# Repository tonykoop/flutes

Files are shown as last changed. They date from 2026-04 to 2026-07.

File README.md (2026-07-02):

# Flutes — Engineering Documentation for Native American Style Wooden Flutes

> *150+ Native American style wooden flutes built between roughly 2018 and 2021, plus the parametric design table that produced them and the build registry that tracked them.*

**Status:** L1 concept packet — L1 V5 packet/explorer scaffold. The repo contains strong historical design-table and build-registry evidence, but this Round 31 packet does not claim V5 build-ready, measured-current, or runtime-verified status until the family rows are extracted from the workbook, mapped to current CAD/DXF, and checked against physical measurements.

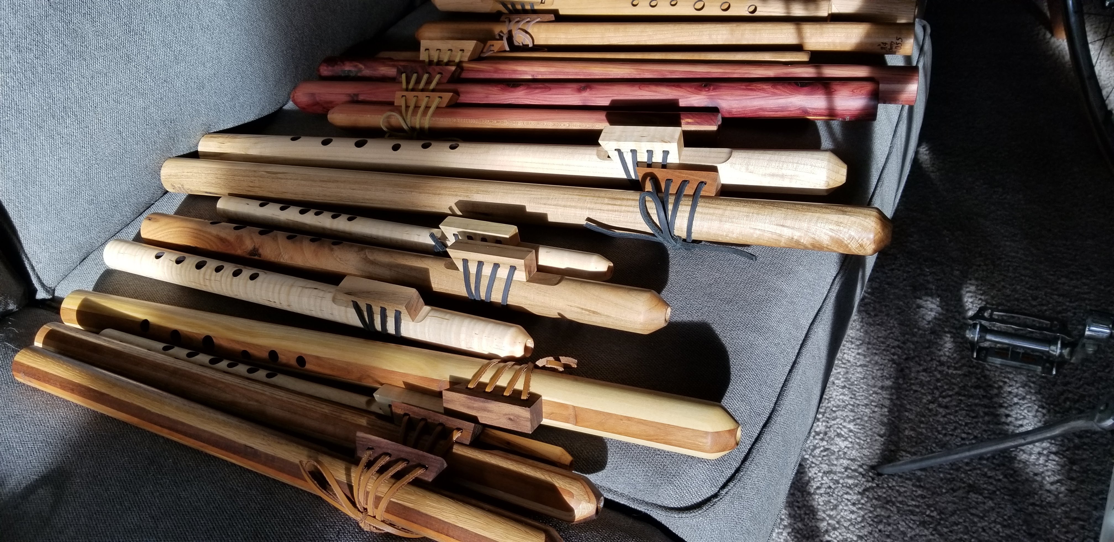
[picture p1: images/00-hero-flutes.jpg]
Hero photo

*A fan-out of finished Native American style wooden flutes across multiple wood species, keys, bird/fetish block styles, and lacing details — the production outcome of the parametric design table and build registry documented below.*

## What this is

Engineering documentation for a multi-year personal practice of building **Native American style flutes** — a two-chambered, end-blown, fipple-class wooden flute tuned to the pentatonic minor scale, traditionally associated with the music of various Indigenous peoples of North America.

This repository combines four threads:

1. **A parametric design table** ([`design-table/flute-dimensions-parametric.xlsx`](design-table/flute-dimensions-parametric.xlsx)) covering flutes from **F4 to E5**, with formulas that derive every build dimension — bore ID, wall thickness, hole positions, hole diameters, blank dimensions, board feet of wood — from a single input: the target fundamental note. Built around the canonical NAF pentatonic-minor hole spacing (3-2-2-3-2 semitones).
2. **A build registry** of **150+ serial-numbered flutes** I've made, recording wood species, key, dimensional measurements, failure modes, and final build status.
3. **CAD geometry** for the body, the slow-air chamber, the nest, the bird/fetish block, and the cutting jigs.
4. **Lineage:** the build methodology was learned from the **[Blue Bear Flutes](https://www.youtube.com/@bluebearflutes)** YouTube channel and developed forward from there into a parametric system.

Sister project to [`djembe`](https://github.com/tonykoop/djembe), [`dundun`](https://github.com/tonykoop/dundun), [`didgeridoo`](https://github.com/tonykoop/didgeridoo), and [`ashiko-drum-workshop`](https://github.com/tonykoop/ashiko-drum-workshop).

Computational counterpart: the Wolfram Summer School notebook **[`Properties of a Native American Flute.nb`](https://github.com/tonykoop/WSS-2019/tree/main/Homework/Final%20Submission)** in [`WSS-2019`](https://github.com/tonykoop/WSS-2019), where the same instrument family gets treated as a computational essay rather than a shop-and-build archive.

## V5 Packet Entry Points

- [design.md](design.md) — Round 31 packet design intent, family split, and evidence boundaries.
- [family-spec.csv](family-spec.csv) — multi-flute family rows with explicit acoustic-law and measurement gates.
- [validation.csv](validation.csv) — current blockers before this becomes a build-ready V5 packet.
- [visual-output-register.csv](visual-output-register.csv) — CAD/DXF/design-table/photo authority map.
- [capstone-manifest.json](capstone-manifest.json) — repo-relative packet inventory for the explorer.
- [explorer.html](explorer.html) — conservative browser explorer for issue #3.
- [CAD/flutes_family.scad](CAD/flutes_family.scad) — minimal OpenSCAD scaffold, not a measured production model.
- [drawings/flutes-family-layout.svg](drawings/flutes-family-layout.svg) and [drawings/flutes-family-layout.dxf](drawings/flutes-family-layout.dxf) — first-pass family split plate.

## Cultural attribution

Native American flutes hold deep spiritual and cultural significance in many Indigenous communities of North America, with traditional roles in courtship, ceremony, healing, and storytelling. As a non-Indigenous maker, the instruments I build are more accurately termed **"Native American style flutes"** (sometimes NAF or NASF) — instruments inspired by, learned in dialogue with, and built in respect for the tradition, but not part of it. The methods documented here are publicly-available craft and engineering knowledge passed forward from contemporary makers to me; the deeper cultural practice belongs to the Indigenous communities from whom the instrument originates.

## Background — what makes a Native American flute different

A Native American flute is **two acoustic chambers in series** with an external block on top:

- **Slow Air Chamber (SAC)** — the short upper chamber. Player blows into the mouthpiece; air enters the SAC and is rerouted up through a small flue, across the open top of the body, and into the True Sound Hole.
- **Bird / Fetish Block** — a removable wooden block sitting on top of the flute, often carved into a totemic shape. Its underside has a precisely-cut channel that directs the air across the True Sound Hole at the right angle and speed to excite the playing chamber.
- **Long (Playing) Chamber** — the main body of the flute, with six finger holes drilled at calculated positions to produce the pentatonic minor scale.

The split-chamber design is what distinguishes the NAF from a Western fipple flute (recorder, tin whistle), where the fipple is integrated into the headjoint. The NAF's external block lets the maker tune the flute's voicing by adjusting the block's position, the flue dimensions, and the angle of the cut into the True Sound Hole — all without disturbing the body. This is also what makes the NAF an extraordinarily sensitive instrument to engineer correctly: small geometry changes shift the tuning audibly.

## The parametric design table

The single most engineering-heavy artifact in this repository is the parametric design table — a spreadsheet that takes a target fundamental note as input and computes every dimension required to build a flute that plays in tune.

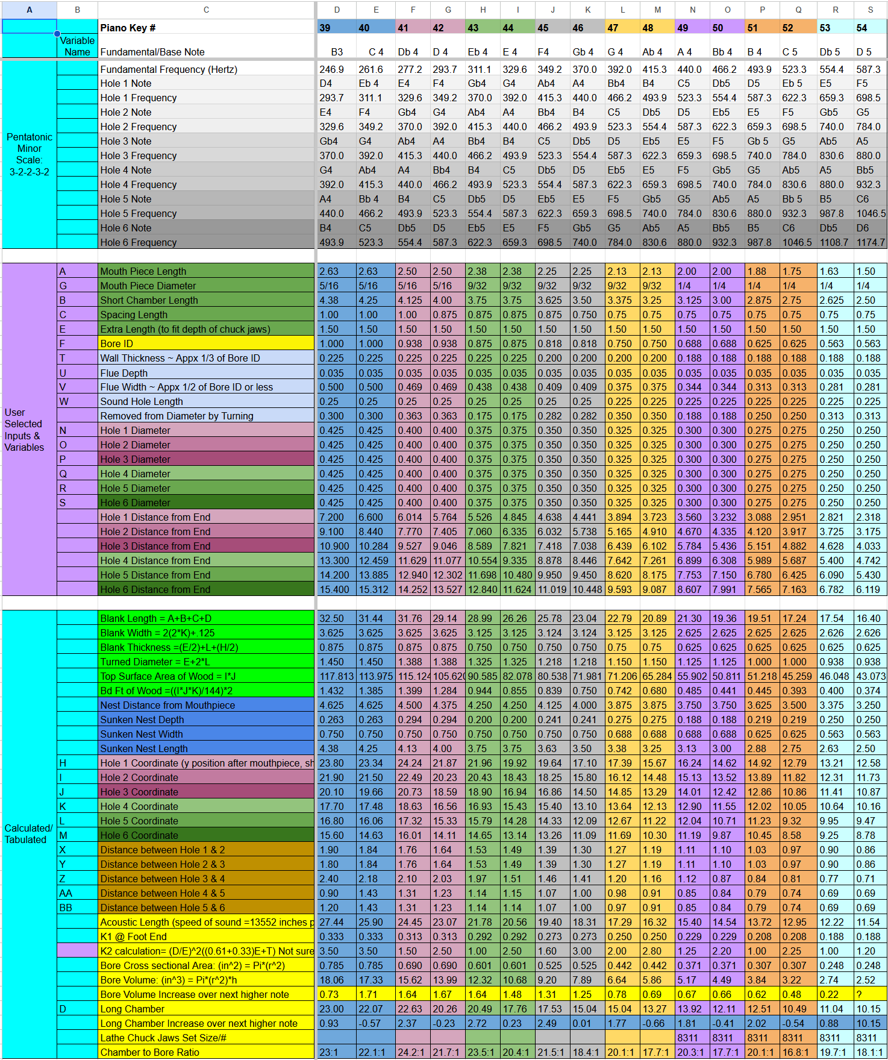
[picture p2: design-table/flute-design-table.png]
Screenshot of the parametric flute design table — keys F4 through E5 as columns, three colored bands of rows: pentatonic-minor scale frequencies, user-set inputs, and derived/calculated dimensions

*The full design table at a glance. **Columns** are target keys (piano key numbers 38–54, i.e. F4 through E5) — pick the column for the flute you want to build. **Rows** are organized into three colored bands: the **beige Pentatonic Minor Scale** band at the top tabulates the fundamental and the six hole frequencies (the canonical **3-2-2-3-2** semitone pattern); the **green User-Selected Inputs & Variables** band in the middle is where you set mouthpiece/chamber/bore/wall/flue/hole-diameter values; and the **red Calculated/Tabulated** band at the bottom derives blank dimensions, board feet of wood, nest position and depth, hole-to-hole spacings, and the K1/K2 acoustic-length corrections that close the loop on the tuning. Change one cell in the green band and the entire red band recomputes — that's the engineering core. The full workbook with formulas live is at [`design-table/flute-dimensions-parametric.xlsx`](design-table/flute-dimensions-parametric.xlsx).*

Inputs are listed in column A, calculated/tabulated values in column G:

**User-set variables (per key):**

| Var | Meaning |
|---|---|
| A | Mouthpiece length |
| B | Short chamber length (the SAC) |
| C | Spacing length (between SAC and playing chamber) |
| E | Extra length to fit lathe chuck jaws |
| F | Bore inner diameter |
| G | Mouthpiece diameter |
| N–S | Hole diameters (six finger holes) |
| T | Wall thickness (~ 1/3 of bore ID) |
| U | Flue depth (~ 0.035" across all keys) |
| V | Flue width (~ 1/2 of bore ID) |
| W | Sound hole length |

**Calculated/derived (per key, formula-driven):**

- Blank length, blank width, blank thickness — total wood requirements
- Turned diameter — finished outside surface
- Board feet of wood — material cost
- Nest distance from mouthpiece — where the bird/fetish block sits
- Sunken nest depth + width — to keep the bird flush with the body
- Hole positions (six holes) — distance from foot end of flute, computed from acoustic relationships

**Tuning:** the design assumes a **pentatonic minor scale** with the standard NAF semitone pattern of **3-2-2-3-2** above the fundamental. The hole frequencies are computed from `f = 440 × 2^((n-49)/12)` where `n` is the piano key number — chromatic equal temperament referenced to A4 = 440 Hz.

Both `CNC Flute Dimensions` (designed for CNC-machined blanks, very precise) and `Low to High Range` (broader range, hand-builder friendly) sheets live in the workbook and produce slightly different geometry trade-offs.

## The build registry

The `Built` sheet of the workbook tracks every flute I've made by serial number. Engineering columns include: number, wood species, key, true-sound-hole width (TSH), track length, nest width, fetish requirement, finished long chamber length, hole pattern reference, date glued, date routered. Customer and gift-recipient information is kept private and is not included in the public version of this registry.

Patterns from the registry as of last update:

- **150+ flutes** documented across the build sheet (numbers 001 through 153 at last update).
- **Wood species** explored: White Oak, Pine, Mahogany, Hard Maple, Western Red Cedar, Black Walnut, Brazilian Walnut, Ambrosia Maple, Birch, Poplar, Oak.
- **Keys** covered: F4, Gb4, G4, Ab4, A4, Bb4, B4, C5, Db5, D5, Eb5, E5 — most of the playable middle range.
- **Failure modes** logged honestly: *"Death on the Router," "Exploded on the lathe, bark inclusion," "Failed Quality Control," "TSH too big," "cut into signature."* Engineering yield was a real consideration; the registry is what let me see which wood/key combinations were durable and which weren't.
- **Dispositions** ranged from gifts to art-fair sales to in-stock inventory and learning-experience builds — recipient details are kept private.

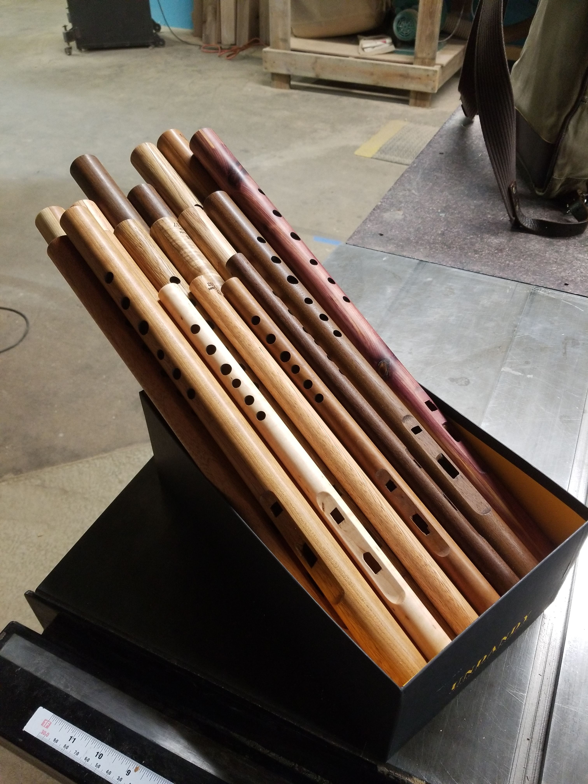
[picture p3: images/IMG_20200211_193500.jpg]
A bundle of finished Native American style flutes across multiple wood species

*A representative bundle of finished flutes — multiple wood species visible (purpleheart, walnut, maple, cedar, oak), various keys, all hand-built to the parametric design table specs.*

## Engineering challenges this repository documents

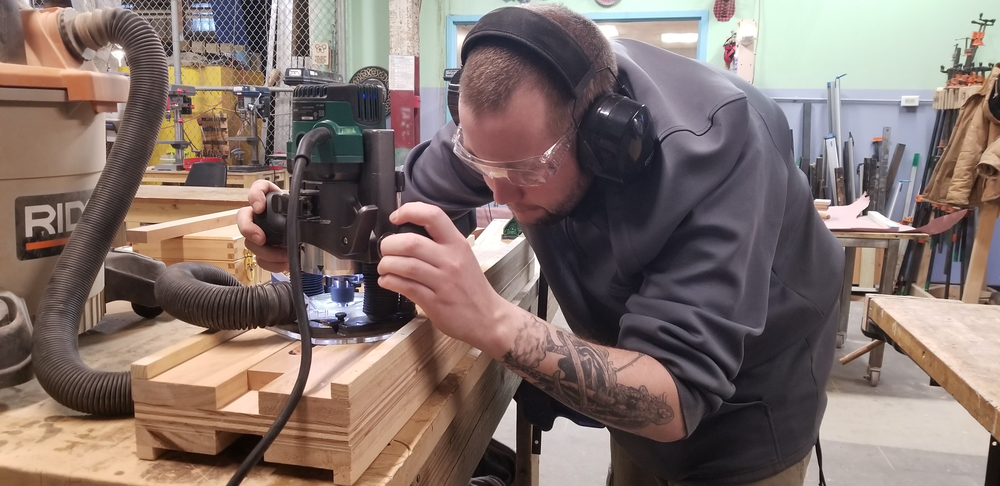
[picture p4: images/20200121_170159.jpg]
Routing the slow-air-chamber profile on a flute body

*In the shop with the plunge router — cutting the slow-air-chamber and true-sound-hole geometry into a flute body. The routing fixture is what makes the SAC and TSH cuts repeatable across builds.*

**1. Two-chamber acoustic tuning.** Unlike a single-chamber instrument (didgeridoo, recorder), the NAF has air paths that interact in the SAC → flue → TSH → playing-chamber sequence. The fundamental of the playing chamber depends on the Long Chamber's effective length, but the playing *response* (how much breath pressure produces clean tone) depends on the SAC, flue, and block geometry. The parametric table captures the dimensional rules; the build registry captures what worked.

**2. Wood-species variation.** The same dimensional spec produces audibly different tone in cedar, walnut, and maple. The registry's `Wood Species` and `Notes` columns let me track which species were forgiving (cedar — very) and which were unforgiving (hard maple — yes; ambrosia maple — also unforgiving, with a high failure rate noted in the registry).

**3. Yield management.** The registry's failure-mode entries are an honest record of how often a flute didn't survive the build. Lathe explosions and routing accidents were not rare. Building a parametric design table didn't reduce yield to 100%; it *bounded* the tolerance window, made each failure diagnosable, and let me iterate the table by what failed.

## CAD and jig design

> *(Forthcoming — pulling SolidWorks files for the body, nest, fetish block, and routing jigs into `/CAD/` as I get SolidWorks running again.)*

Repository structure is laid out for:

- `/CAD/flute-body/` — the body geometry parametric in target key.
- `/CAD/nest-and-fetish/` — the sunken nest where the bird/fetish block sits, and the block geometry itself (with the air-direction channel underneath).
- `/CAD/jigs/` — the routing fixture for cutting the SAC and TSH, and any sanding or hole-drilling jigs.

## Lineage and acknowledgments

The build methodology in this repository was learned primarily from the **[Blue Bear Flutes](https://www.youtube.com/@bluebearflutes)** YouTube channel — an extraordinary public archive of craft knowledge from a contemporary maker generously sharing technique. The parametric design table and the engineering documentation are my own derivations from that learning process; the underlying craft is not.

## What this work is for

- **The engineering question** — does a parametric design table let you reliably build flutes in tune across multiple wood species and a wide key range? The build registry says: yes, *bounded by* yield. Improving the table's predictions is the iterative loop the table itself enables.
- **The portfolio frame** — for engineers and recruiters: this repository documents an ongoing engineering-grade craft practice. The parametric table is a working SolidWorks-adjacent design tool; the build registry is the production data that validated it; the failure-mode column is the honest engineering-yield record. All from one personal practice spanning ~3+ years.
- **The personal frame** — these flutes have been gifts, art-fair sales, family heirlooms, and personal instruments. The people who received them are not named in this repository.

## License

Released under [CC-BY 4.0](LICENSE) — use freely with attribution. The Native American flute originates with Indigenous peoples of North America and remains culturally significant; the engineering documentation, parametric design table, build registry, and analysis in this repository are my own work, free to reuse and adapt with credit. The Blue Bear Flutes lineage is acknowledged above and any derivative work should reference that source as well.

## Repository structure

```
flutes/
├── README.md                  ← you are here
├── LICENSE                    ← CC-BY 4.0
├── .gitignore
├── design-table/
│   └── flute-dimensions-parametric.xlsx   ← the engineering core
├── built-log/
│   └── (extracts from the Built sheet — flute build registry)
├── research/                  ← Blue Bear Flutes references, NAF acoustic notes
├── analysis/                  ← derived charts, yield analysis (forthcoming)
├── CAD/
│   ├── flute-body/            ← body geometry parametric in key
│   ├── nest-and-fetish/       ← sunken nest + bird/fetish block geometry
│   └── jigs/                  ← routing fixture, hole-drilling jigs
├── drawings/                  ← PDF exports of hole patterns + body sections
├── images/                    ← finished-flute photos, build photos, fetish detail shots
└── reference/                 ← scale/temperament references, NAF community resources
```

## Status

| Section | Status |
|---|---|
| Repo description, license, gitignore | ✓ done |
| Parametric design table | ✓ committed (the engineering core) |
| Build registry summary | ✓ summarized in this README |
| Hero photos | ✓ done |
| Cultural attribution | ✓ done |
| CAD — body geometry | not yet committed (SolidWorks access pending) |
| CAD — nest + fetish | not yet committed |
| CAD — jigs | not yet committed |
| Yield analysis from build registry | forthcoming |
| Evolution-pipeline intake | Stage 0 intake added under `evolution/` (manifest, design-intent, revisions); Gate A not yet run |

Living document — the empirical core is already here; CAD exports and yield-analysis follow-ons are the main remaining additions.
## Learn to play

Starter songbooks for the flutes built from this repo's design table
live under [`learn-to-play/`](learn-to-play/), one per build family:

- [`learn-to-play/naf-6hole/`](learn-to-play/naf-6hole/) — A-tuned
  6-hole NAF starter songbook: warmup scales, three beginner tunes
  (Amazing Grace, Star of the County Down, What Wondrous Love Is This),
  two intermediates (Simple Gifts, Twinkle Twinkle), and one Heifer
  Zephyr original (Pre-Dawn Field). Open `songsheet.pdf` for the
  one-page summary.

Songbooks are generated by [sheet-music](https://github.com/tonykoop/sheet-music)
— pair `instrument-maker-v4` (designs the flute) with that skill (writes
the music for it).

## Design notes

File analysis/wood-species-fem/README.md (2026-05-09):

# Wood-Species Coupled Structural-Acoustic FEM

**Issue:** `flutes#1` — Coupled structural-acoustic FEM: quantify wood-species
effect on tone (cedar vs walnut vs hard maple).

**Readiness:** L3-frontier analysis (methodology complete, analytical results
computed, FEM execution ready, empirical gate deferred).

---

## Summary

This analysis quantifies how wood species — Western Red Cedar, Black Walnut,
and Hard Maple — affects the tone of a Native American style flute with a fixed
A4-key bore geometry.

**Key finding:** At A4, the "forgiving vs demanding" character difference between
species is driven primarily by **wall damping** (η_L), not by structural-acoustic
mode coincidence.

| Species | η_L | f_QSC (Hz) | Tone |
|---|-----|---|---|
| W. Red Cedar | 0.030 | **1141** | Warm, forgiving |
| Black Walnut | 0.020 | **1176** | Balanced |
| Hard Maple | 0.014 | **1203** | Bright, demanding |

f_QSC is the Q-weighted spectral centroid — a scalar tone-brightness index.
Cedar's higher damping attenuates upper partials 2.1× faster than maple,
explaining the registry observation without requiring structural modes to
coincide with acoustic partials.

No structural-acoustic avoided crossing was found at < 5% separation for
any species at A4 key (smallest observed separation: 9.1%, Hard Maple
2nd bending mode vs acoustic n=3).

---

## Files in this directory

| File | Contents |
|---|---|
| `README.md` | This summary |
| `wood-property-table.md` | E, ρ, η, Poisson ratios per species with FPL-GTR-190 citations |
| `fem-scenario.md` | Geometry, mesh, BCs, coupling physics, analysis type |
| `modal-results-table.md` | 5 acoustic modes + 3 structural modes per species; Q-factor tables |
| `tone-color-comparison.md` | f_QSC computation, spectrum ASCII plot, root-cause analysis |
| `capstone-design-table.md` | All parameters in one table; FEM execution status; next steps |
| `references.md` | Literature and software citations |

---

## Physics overview

### Air-column modes

Open-open cylindrical bore, L_eff = 390 mm (A4 key):

    f_n = n × 440 Hz    for n = 1, 2, 3, 4, 5

These are the same for all species. Wall compliance shifts modes < 1%
(bore is stiff relative to air pressure at these dimensions).

### Body bending modes

Hollow cylinder, simply-supported, L = 381 mm.

    f_body_n = n² × (π / 2L²) × √(EI / ρA)

| Species | f_body_1 | f_body_2 |
|---|---|---|
| Cedar | 388 Hz  | 1552 Hz |
| Walnut  | 371 Hz  | 1484 Hz |
| Maple | 360 Hz  | 1440 Hz |

### Acoustic Q-factor

    1/Q_n = 1/Q_rad_n + 1/Q_wall
    Q_rad_n ≈ n × 15     (radiation loss, bore geometry)
    Q_wall = 1/η_L        (species-dependent wall damping)

### Tone color metric

    f_QSC = Σ(f_n × Q_n × A_n) / Σ(Q_n × A_n)
    A_n = 1/n   (fipple excitation amplitude model)

---

## Relationship to registry observations

The build registry records: "Cedar is forgiving; hard maple is demanding;
ambrosia maple has a high failure rate." This analysis provides the first
principled physical explanation: **cedar's 2.1× higher damping factor
attenuates upper partials faster**, reducing the sensitivity of the
instrument to embouchure variations and overblowing.

The analysis also rules out structural-acoustic mode coincidence as a
first-order explanation at A4 key — all species show body modes separated
from acoustic harmonics by > 9%.

---

## FEM execution status

Analytical pre-computation complete. Full FEM execution (COMSOL Acoustic-Solid
Interaction or Ansys Harmonic Acoustics) will refine:
- Exact body mode frequencies (cylindrical shell vs beam approximation)
- Orthotropic vs isotropic material response
- Radiation impedance at open ends

Empirical validation (FFT blow test on three A4 registry flutes)
is deferred; no measured spectral data exists in the repo yet.

**Do not claim L4 build-ready.** This is a frontier analysis; computed
FEM results and empirical comparison are required for L4.

---

## Cross-references

- `design-table/flute-dimensions-parametric.xlsx` — bore geometry source
- `built-log/` — build registry with species-resolved entries
- `tonykoop/WSS-2019` — Wolfram notebook: air-column acoustic model
- `tonykoop/tensile-testing` — orthotropic E-tensor measurement pipeline
- `tonykoop/tongue-drum` analysis `docs/study/fem-modal-validation.md`
  — FEM pipeline reused; FFT measurement protocol shared

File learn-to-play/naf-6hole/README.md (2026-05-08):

# learn-to-play / Native American Flute (6-hole)

A starter songbook for the **A-tuned 6-hole Native American flute**
you built from [`flutes`](https://github.com/tonykoop/flutes) (the
parametric design table family). Generated by the
[`sheet-music`](https://github.com/tonykoop/sheet-music) skill.

This songbook is calibrated for the **A-tuned NAF** specifically —
fundamental A4, range A4–D6, A minor pentatonic. If your build is in a
different key (G, F#, D are also common in the registry), the same
tune.abc files transpose naturally; re-deposit with `--instrument
naf-6hole` after updating the registry row.

## Folder map

| Folder | Contents |
|---|---|
| `00-warmup-scales/` | Range walk, pentatonic intervals, and the single-grace ornament drill |
| `01-easy/` | Three slow, beginner-friendly PD tunes |
| `02-intermediate/` | Two brisker PD tunes with wider intervals |
| `03-original/` | *Pre-Dawn Field* — the Heifer Zephyr original written for this build |
| `fingering-charts.svg` | Combined fingering chart for every NAF pitch (A4–D6) |
| `songsheet.pdf` | Printable one-page summary of the whole songbook |

## Repertoire

### 01-easy

| Tune | Tradition | Key on A-NAF |
|---|---|---|
| Amazing Grace | Hymn (Newton 1779 / "New Britain" 1835) | A min pent (transposed up an octave from canonical G) |
| Star of the County Down | Trad. Irish ("Dives and Lazarus" family, pre-1855) | A min pent (pentatonicised from A dorian) |
| What Wondrous Love Is This | Trad. Appalachian (1811 / 1835) | A min pent (pentatonicised from A dorian) |

### 02-intermediate

| Tune | Tradition | Key on A-NAF |
|---|---|---|
| Simple Gifts | Shaker dance song (Brackett 1848) | A min pent (re-keyed from F major) |
| Twinkle Twinkle Little Star | Mozart K. 265 (1781) / Taylor 1806 | A min pent (re-keyed from C major) |

### 03-original

**Pre-Dawn Field** — composed for this build. AABA, 32 bars, ♩=60.
Written for the Heifer Zephyr origin moment: chasing aurora north of
Minneapolis, sitting up all night counting constellations, watching
cold fog settle on the field as the sun rose, breath flaring in the
chill like a heifer bison's in a Yellowstone morning. Read the full
story in [`03-original/pre-dawn-field/notes.md`](03-original/pre-dawn-field/notes.md).

## How to use the per-tune files

Every tune folder has multiple files. The canonical source is
`tune.abc` — everything else is generated from it.

| File | Purpose |
|---|---|
| `tune.abc` | Canonical notation in ABC format (plain text) |
| `tune.musicxml` | Notation for Ableton, Logic, MuseScore, Sibelius, etc. |
| `tune.mid` | Playable MIDI (uses GM preset 76 — Pan Flute) |
| `tune-fingering.svg` | Fingering chart, one diagram per distinct pitch |
| `tune.pdf` | Per-tune one-page printable songsheet |
| `notes.md` | Source / provenance, range notes, practice tip |
| `render-summary.json` | Which pipeline stages succeeded / were skipped |

> **Skipped stages on this generation:** `tune.ly` (LilyPond not
> installed locally), `tune.svg` (depends on LilyPond), and `tune.wav`
> (fluidsynth not installed). These are honest skips — install the
> binaries and re-run `scripts/render_pipeline.py` to fill them in.
> See `references/audio-rendering.md` in the `sheet-music` repo.

## Suggested practice path

1. Open the day with `00-warmup-scales/range-walk.abc`. Hold each note
   long enough to find a steady tone before moving up. Ascending,
   descending, twice through.
2. Run `intervals.abc` once. The 5ths and the octave are the wider
   embouchure stretches you'll need for the songbook.
3. Pick one tune from `01-easy/`. Open its `tune.mid` to hear the
   melody, then read its `notes.md` for the range check and practice
   tip.
4. Play the first phrase slowly with the per-tune fingering SVG open.
   Don't worry about tempo — find the breath first, the rhythm second.
5. When all three easy tunes feel comfortable, move to
   `02-intermediate/`. Simple Gifts and Twinkle Twinkle have wider
   intervals and brisker tempos.
6. Save `03-original/pre-dawn-field/` for a quiet hour. It's meant to
   be played slowly, alone.

## Re-generating

If you change a `tune.abc` (transposing, ornamenting, fixing a typo),
regenerate the derived files:

```bash
# from the sheet-music repo root:
python scripts/render_pipeline.py \
  --tune <tune.abc path> \
  --instrument naf-6hole \
  --out <output dir>
```

## License

- **Pre-Dawn Field** (the original) — MIT-licensed, same as the rest
  of `sheet-music`. Yours to perform, record, arrange, and adapt.
- **Public-domain tunes** — PD by virtue of pre-1929 publication.
  Per-tune provenance is documented in each `notes.md`. The specific
  arrangements (which transpose / pentatonicise the originals for the
  A-NAF) are MIT-licensed by Tony Koop / Heifer Zephyr.

## Where to ask for more

- More tunes for the NAF: open an issue in
  [`sheet-music`](https://github.com/tonykoop/sheet-music) with the
  tradition or mood you want, and reference `naf-6hole` as the target.
- Build questions for the flute itself: see [`flutes`](https://github.com/tonykoop/flutes).
- Companion skill that designs and documents the build: `instrument-maker-v4`.

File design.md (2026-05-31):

# Flutes V5 Packet Scaffold

## Design Intent

This packet promotes the `flutes` repository from a historical engineering archive toward a V5 packet/explorer scaffold. The repo already has unusually strong evidence for Native American style wooden flutes: a parametric workbook, build photos, historical SolidWorks files, learning material, and a wood-species FEM study. Round 31 does not convert that history into a build-ready packet by assertion. It makes the family split explicit and records the measurement gates needed before any row can be treated as current fabrication authority.

## Family Split

| Family | Scope | Current authority | Measurement gate |
| --- | --- | --- | --- |
| `NAF-6H` | Six-hole Native American style wooden flutes from the historical workbook | Public F4/A4/C5 workbook rows and sanitized build-log aggregates now exist, but they are comparison evidence only | Log current measured fundamental plus six-hole tuning for each selected key before treating the rows as CAD/DXF or build authority |
| `PVC-TRAIN` | PVC training or proof flute using the same open-open acoustic law | Planning family only | Select bore stock, measure actual ID, then compute and drill a proof flute before publishing dimensions |
| `LEGACY-SW` | Historical SolidWorks body/nest/fetish/jig assets | Archived source files exist under `legacy/` and stashed CAD paths, but they are not normalized into V5 CAD | Recover the chosen model, export clean neutral geometry, and map dimensions back to family rows |
| `SONGBOOK` | Learn-to-play assets for the 6-hole NAF family | Documentation/playability support | Keep separate from fabrication authority; fingering charts do not validate geometry |

## Governing Acoustic Model

The target rows are duct flutes with an effectively open-open long playing chamber. The first-order model is:

```text
L_eff = c / (2f)
L_geom = L_eff - end_correction
```

The historical design table also includes NAF-specific corrections and voicing geometry for the slow-air chamber, flue, true sound hole, bird block, and six finger holes. Those corrections are design-table evidence, not something this scaffold re-derives by hand. The extracted F4/A4/C5 rows stay `dimension_provenance=measurement_required` until checked against current measured tuning traces.

## Evidence Boundary

- The workbook extraction and sanitized build-log comparison support an L1 packet scaffold and justify a future L2 shop-packet candidate after current measured tuning checks.
- The FEM analysis is a study artifact for wood-species behavior. It does not replace per-flute pitch, decay, or hole-tuning measurements.
- The new OpenSCAD, SVG, and DXF files are family-split scaffolds. They show packet organization and authority routing, not a complete production flute.
- Photos are documentation and provenance support only. They are not dimensional authority.

## Next Promotion Gates

1. Capture current measured fundamental plus six-hole tuning for the F4, A4, and C5 public workbook rows.
2. Reconcile the C5 historical chamber-length mismatch before using that row for CAD/DXF or cut-list authority.
3. Keep the A4 FEM simplification analysis-only until it is reconciled with the workbook row and measured logs.
4. Replace scaffold CAD/DXF with checked geometry generated from reviewed design-table rows.
5. Add MCP provenance entries only when an actual OpenSCAD, Blender, Illustrator, or Photoshop MCP session produces a repo artifact.

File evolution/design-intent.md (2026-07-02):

# Design Intent — flutes rev A

- Master CAD: `CAD/flutes_family.scad` (sha256: da8ef2fa96771d89ffb48a29936026cc3f3fe4fb7997d9f78b5e01fbb8e4db68), driven by seed `CAD/design-table-seed.csv` (sha256: 6ed4ceb9d774c4f560a766ce802a76e79e68c5fdd5b87be7ef8ca6b55cc04e46) and historical workbook `Flutes.xlsx` (sha256: 3a58014cc2f502797e02126382682203d9d7711faf644c904f6b40cbbbca840d)
- Function: Native American style six-hole wooden flutes (NAF-6H) plus PVC training and legacy-SolidWorks families. Duct flutes with an effectively open-open long playing chamber: L_eff = c/(2f); L_geom = L_eff − end_correction. NAF-specific corrections and voicing (slow-air chamber, flue, true sound hole, bird block, six finger holes) live in the historical workbook as evidence, not re-derived here.
- Environment: L1 concept/explorer scaffold on top of a strong historical archive (150+ serial-numbered builds, workbook, FEM wood-species study, legacy SolidWorks). Nothing is build-ready until family rows are extracted from the workbook and checked against current measured tuning.
- Target qty: 1 (per selected key). Deadline: TBD. Budget/unit ceiling: TBD.

## Critical dimensions (carry tolerances)

| Feature | Nominal | Tolerance | Why critical | Source |
| --- | --- | --- | --- | --- |
| NAF-6H F4 predicted geometric length | 432.562 mm | measure current fundamental before authority | fundamental pitch (F4 = 349.23 Hz) | family-spec.csv NAF-6H-F4 (measurement_required) |
| NAF-6H A4 predicted geometric length | 337.490 mm | measure current A4 tuning | fundamental pitch (A4 = 440.00 Hz) | family-spec.csv NAF-6H-A4 (measurement_required) |
| NAF-6H C5 predicted geometric length | 285.318 mm | reconcile built-log chamber mismatch | fundamental pitch (C5 = 523.25 Hz) | family-spec.csv NAF-6H-C5 (measurement_required) |
| NAF-6H A4 bore ID | 19.050 mm | measure fired/turned bore | bore governs pitch/response | family-spec.csv NAF-6H-A4 (measurement_required) |
| Hole count | 6 | ergonomic + tuning gate | six-hole tuning log required | family-spec.csv (measurement_required) |
| PVC-TRAIN bore ID | measurement_required | measure stock before computing | planning row only | family-spec.csv PVC-TRAIN-A4 |

## Incidental (free for DFM)

- Wood species/figure, bird/fetish block style, lacing/decoration, exterior body profile, finish — all documented historically but not dimension-controlling.

## Must-nots (DFM may never violate)

- Do not treat extracted workbook rows as CAD/DXF or tuning authority until logged against current measured fundamental + six-hole tuning (design.md evidence boundary; family-spec next_measurement_gate).
- Voicing geometry (flue/true sound hole/bird block) is tuning-sensitive: refine by hand, do not freeze from a scaffold or lossy export.
- Do not derive PVC-TRAIN dimensions from the wooden NAF table without measuring actual PVC stock (family-spec PVC-TRAIN).
- Legacy SolidWorks archive is not current CAD authority until normalized and reviewed (family-spec LEGACY-SW).

## Material intent

- Preferred: wood (NAF-6H) per historical build registry; PVC proof stock for training family (family-spec material_system).
- Acceptable subs: per sourcing.csv / bom.csv (spec-first; live prices unverified).
- Forbidden: none recorded (mouth-safe finishes on played bodies).

## Stage status

Stage 0 intake complete 2026-07-01. Gate A (Alpha shop compile) NOT yet run — no concessions logged, nothing presented as shippable. L1 concept scaffold; authority remains measurement-gated.

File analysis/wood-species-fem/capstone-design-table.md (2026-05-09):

# Capstone Design Table — Wood-Species Coupled Structural-Acoustic FEM

Issue: `flutes#1` — Coupled structural-acoustic FEM: quantify wood-species
effect on tone (cedar vs walnut vs hard maple).
Readiness: L3-frontier analysis.

---

## Fixed geometry (A4 key)

| Parameter | Value | Source |
|---|---|---|
| Target fundamental f₁ | 440 Hz | Design table A4 column |
| Effective acoustic length L_eff | 390 mm | c/(2f₁), c=343 m/s |
| Bore inner diameter D_bore | 15.2 mm | Design table |
| Wall thickness h_wall | 5.1 mm | ≈ D_bore/3 (design table rule) |
| Outer diameter D_outer | 25.4 mm | D_bore + 2h_wall |
| Physical chamber length L_chamber | 381 mm | L_eff − 2δ (end correction) |

---

## Material properties summary

| Species | E_L (GPa) | ρ (kg/m³) | η_L | Q_wall |
|---|---|---|-----|---|
| W. Red Cedar  | 7.7  | 370 | 0.030 | 33 |
| Black Walnut  | 11.6 | 610 | 0.020 | 50 |
| Hard Maple | 12.6 | 705 | 0.014 | 71 |

Source: FPL-GTR-190 [1]; damping from Haines 1979 [2].

---

## Acoustic modal series (all species — bore geometry dominant)

| Mode n | f_n (Hz) | Note |
|---|---|---|
| 1 | 440 | A4 |
| 2 | 880 | A5 |
| 3 | 1320 | E6 |
| 4 | 1760 | A6 |
| 5 | 2200 | C#7 |

Wall compliance correction < 1% for all species; not included.

---

## Structural bending modes (simply-supported hollow cylinder)

| Species | f_body_1 (Hz) | f_body_2 (Hz) | f_body_3 (Hz) |
|---|---|---|---|
| Cedar | 388 | 1552 | 3492 |
| Walnut  | 371 | 1484 | 3339 |
| Maple | 360 | 1440 | 3240 |

---

## Acoustic Q-factor table

| Species | Q_n=1 | Q_n=2 | Q_n=3 | Q_n=4 | Q_n=5 |
|---|---|---|---|---|---|
| Cedar | 10.3 | 15.7 | 19.0 | 21.3 | 22.9 |
| Walnut  | 11.5 | 18.8 | 23.7 | 27.3 | 30.0 |
| Maple | 12.4 | 21.1 | 27.6 | 32.6 | 36.6 |

---

## Tone color metric (Q-weighted spectral centroid)

| Species | f_QSC (Hz) | Rank | Character |
|---|---|---|---|
| W. Red Cedar  | 1141 | 1 — warmest | Forgiving, dark, high dynamic range |
| Black Walnut  | 1176 | 2 | Balanced, moderate warmth |
| Hard Maple | 1203 | 3 — brightest | Demanding, bright, long sustain |

Species spread: 62 Hz (5.4% of centroid). Rank order is stable to
reasonable variation in excitation model and radiation damping.

---

## Avoided-crossing proximity

| Species | Body mode | f_body (Hz) | Nearest acoustic | Separation |
|---|---|---|---|---|
| Cedar  | 2nd bend | 1552 | n=4 (1760 Hz) | 11.8% |
| Walnut | 2nd bend | 1484 | n=3 (1320 Hz) | 12.4% |
| Maple  | 2nd bend | 1440 | n=3 (1320 Hz) | 9.1% |

No species shows structural-acoustic near-coincidence (< 5%).
Mode-coupling is a secondary mechanism at A4; damping is primary.

---

## Root-cause summary

| Mechanism | Cedar | Walnut | Maple | Dominant? |
|---|---|---|---|---|
| Wall damping η_L | 0.030 (high) | 0.020 | 0.014 (low) | **Yes** |
| Closest body-acoustic separation | 11.8% | 12.4% | 9.1% | No (> 5%) |
| f_QSC outcome | Warm (1141 Hz) | Mid (1176 Hz) | Bright (1203 Hz) | — |

**Registry observation confirmed:** Cedar's high damping (η_L = 0.030)
is the primary physical cause of its forgiving, warm character — not
structural mode coincidence with acoustic partials.

---

## FEM execution requirements

| Requirement | Status |
|---|---|
| Geometry defined | ✅ |
| Mesh strategy defined | ✅ |
| BCs defined | ✅ |
| Material inputs ready | ✅ |
| Damping values assigned | ✅ |
| COMSOL/Ansys license + workstation | ⚠️ Required for computed results |
| Empirical validation recordings | ⏳ Deferred |

Analysis readiness: **L3-frontier**. Ready for FEM execution; empirical
validation gate deferred until registry recordings (per-species A4 flute
FFT blow tests) are available.

---

## Next steps for L4 build-readiness

1. Execute FEM in COMSOL Acoustic-Solid Interaction or Ansys Harmonic Acoustics
   using inputs from this design table and `fem-scenario.md`.
2. Extract computed modal results; compare against analytical pre-computation
   in `modal-results-table.md` — flag any mode that deviates > 5%.
3. Record phone-mic FFT blow tests on three A4 registry flutes (one per species).
4. Overlay measured vs. FEM-predicted spectrum; confirm f_QSC rank order.
5. Publish validated spectral fingerprints in `analysis/wood-species-fem/measured/`.

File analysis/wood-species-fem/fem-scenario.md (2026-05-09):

# FEM Scenario — Coupled Structural-Acoustic Analysis

Analysis readiness: L3-frontier (methodology and inputs defined;
software execution requires COMSOL or Ansys licence on a workstation
with the Acoustic-Solid Interaction module).

---

## Instrument geometry

Fixed bore: A4 key (fundamental 440 Hz).

### Playing-chamber dimensions

| Parameter | Symbol | Value |
|---|---|---|
| Target fundamental | f₁ | 440 Hz |
| Speed of sound (20°C) | c | 343 m/s |
| Effective acoustic length | L_eff | c/(2f₁) = 390 mm |
| End correction per open end | δ | 0.6 × R_bore = 4.6 mm |
| Physical chamber length | L_chamber | 390 − 2×4.6 = 381 mm |
| Bore inner diameter | D_bore | 15.2 mm |
| Bore inner radius | R_bore | 7.60 mm |
| Wall thickness | h_wall | 5.10 mm |
| Outer diameter | D_outer | 25.4 mm |

Source: parametric design table
`design-table/flute-dimensions-parametric.xlsx`, column A4
(derived values; see README for design table description).

The SAC (slow air chamber), nest, and bird block are excluded from this
analysis; the playing chamber alone is modeled. The SAC–TSH junction
is treated as an open boundary condition for the air column (pressure-release
at the True Sound Hole end).

---

## Finite element model

### Geometry

- Cylindrical shell: hollow tube, L = 381 mm, D_inner = 15.2 mm,
  D_outer = 25.4 mm.
- Air domain: cylindrical volume, L = 381 mm, D = 15.2 mm.
- Two end caps: open (pressure-release) boundary conditions at both
  ends of the air domain (playing position with all holes covered
  except the foot opening is not modeled here; open-open is the
  conservative acoustic boundary).

### Mesh

- Solid (tube wall): 8-node hexahedral (SOLID186/C3D20R equivalent).
  Target max element size: h_wall/3 = 1.7 mm. Minimum 3 elements
  through wall thickness.
- Acoustic (air): 8-node acoustic hexahedral (FLUID30/AC3D8).
  Target max element size: c/(10 × f_max) = 343/(10×2200) = 15.6 mm.
  Adequate for 5-mode extraction to 2200 Hz.
- Acoustic–solid interface: conforming mesh with coupling DOFs
  at the shared surface.

### Boundary conditions

| Surface | Condition |
|---|---|
| TSH end (top) | Acoustic: pressure-release (p = 0) |
| Foot end (bottom) | Acoustic: pressure-release (p = 0) |
| Tube outer surface | Structural: free (no constraint) |
| TSH end of tube | Structural: simply-supported (w = 0, θ = free) |
| Foot end of tube | Structural: simply-supported (w = 0, θ = free) |

### Material assignment

Each run uses one of the three species (isotropic approximation using E_L and ν_LR
from the wood property table; full orthotropic tensor available in [1]).
Isotropic approximation is the first-order model; orthotropic refinement is the
Phase 2 FEM update.

### Coupling physics

Acoustic-Solid Interaction multiphysics (COMSOL) or Fluid–Structure
Interaction (Ansys Harmonic Acoustics):
- Normal acceleration continuity at the solid–fluid interface:
  ∂²u_n/∂t² = (1/ρ_air) × ∂p/∂n
- Pressure load on solid from fluid:
  F_n = −p × n_hat (pressure acts inward on tube wall)

### Analysis type

Frequency-domain harmonic analysis (eigenfrequency extraction):
- Frequency range: 200–3000 Hz (captures 5 acoustic modes + structural modes)
- Solver: MUMPS or PARDISO direct solver; complex eigenvalue extraction
  for damped modes.
- Damping: structural loss factor η_L applied as isotropic loss factor
  in solid domain; fluid damping ignored (air is lightly damped at these
  frequencies).

---

## Mode identification protocol

Acoustic-dominated modes: pressure field shows clear standing-wave pattern
(n half-wavelengths along bore axis); wall displacement amplitude is small
relative to air particle displacement.

Structural-dominated modes: wall displacement pattern is dominant;
air-pressure perturbation is secondary. Identify by modal strain energy
fraction in solid domain > 50%.

Coupled modes (avoided crossings): energy shared between air and wall;
frequency splitting visible in the modal map. Flag for qualitative
species comparison.

---

## Output deliverables

1. Modal map: plot of all modes (structural + acoustic character)
   vs frequency for each species, 200–2500 Hz.
2. Modal table: 5 lowest acoustic-dominated modes per species
   (frequency, Q-factor, acoustic energy fraction).
3. Structural mode table: lowest 3 bending modes per species.
4. Q-weighted spectral centroid: tone-color metric per species.
5. Avoided-crossing proximity table: separation between each
   structural mode and the nearest acoustic harmonic.

---

## Validation plan

Compare predicted acoustic fundamentals against phone-mic FFT recordings
of three A4 registry flutes (one per species), single-blow methodology
consistent with `tongue-drum` measurement protocol. Empirical gate
deferred until recordings are available.

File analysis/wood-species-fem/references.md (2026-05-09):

# References — Wood-Species Coupled Structural-Acoustic FEM

## Primary material property sources

**[1] Wood Handbook — Wood as an Engineering Material**
Forest Products Laboratory. USDA Forest Service, Forest Products Laboratory.
General Technical Report FPL-GTR-190. Madison, WI, 2010.
Table 5-1 (orthotropic elastic constants for clear, straight-grained wood by species) and
Table 5-2 (strength properties).
URL: https://www.fpl.fs.usda.gov/documnts/fplgtr/fpl_gtr190.pdf

Species values used:
- Western Red Cedar (*Thuja plicata*): Table 5-1, moisture content 12%.
- Black Walnut (*Juglans nigra*): Table 5-1, moisture content 12%.
- Hard Maple (*Acer saccharum*): Table 5-1, moisture content 12%.

**[2] Haines, D. W.** "On musical instrument wood."
*Journal of the Catgut Acoustical Society*, Vol. 31, pp. 23–32, 1979.
Longitudinal loss factor (damping) measurements for spruce, cedar, maple, and walnut.

**[3] Schelleng, J. C.** "The bowed string and the player."
*Journal of the Acoustical Society of America*, Vol. 53, No. 1, pp. 26–41, 1973.
Discussion of Q-factor and damping in musical wood.

## Acoustic modeling references

**[4] Fletcher, N. H., and Rossing, T. D.**
*The Physics of Musical Instruments*, 2nd ed. Springer, New York, 1998.
Chapter 16: Flutes and flue instruments. Air-column mode theory, end corrections, open-hole cutoff frequency.

**[5] Nederveen, C. J.**
*Acoustical Aspects of Woodwind Instruments*. Northern Illinois University Press, 1998.
Detailed treatment of end corrections, tone-hole lattice, and inharmonicity for
open-cylindrical instruments.

**[6] Wolfe, J.** "Flute acoustics: an introduction."
UNSW School of Physics, Music Acoustics group, 2005.
URL: https://www.phys.unsw.edu.au/music/flute/

## Structural-acoustic coupling references

**[7] Fahy, F. J.**
*Sound and Structural Vibration: Radiation, Transmission and Response*.
Academic Press, London, 1985.
Chapters 4 and 5: radiation efficiency of cylindrical shells; vibroacoustic coupling loss factor.

**[8] Cremer, L., Heckl, M., and Ungar, E. E.**
*Structure-Borne Sound: Structural Vibrations and Sound Radiation at Audio Frequencies*.
Springer-Verlag, Berlin, 1988.
Chapter 9: Cylindrical shells, breathing modes, ring frequency.

**[9] Gough, C. E.** "Musical acoustics." In *Springer Handbook of Acoustics*,
T. D. Rossing, ed., Springer, New York, 2007, pp. 533–621.
Section 15.4: Wood and its acoustic properties; loss factor tables for instrument woods.

## FEM software references

**[10] COMSOL Multiphysics 6.x — Acoustics Module User's Guide.**
Acoustic-Solid Interaction multiphysics coupling; frequency-domain harmonic analysis.
Chapter 3: Acoustic-Structural Interaction.

**[11] Ansys Mechanical 2023 — Harmonic Acoustics Module.**
System coupling: Fluid–Structure Interaction for acoustic cavities and elastic shells.
Ansys Help Portal: Harmonic Acoustics documentation.

## Sister-repo cross-references

- `tonykoop/flutes` — build registry and parametric design table.
- `tonykoop/WSS-2019` — Wolfram Summer School notebook:
  *Properties of a Native American Flute.nb* (air-column acoustic model).
- `tonykoop/tensile-testing` — orthotropic elastic constant measurement pipeline,
  source of species-resolved E-tensor data.
- `tonykoop/tongue-drum` — FEM modal pipeline reused for this analysis;
  measurement protocol shared.

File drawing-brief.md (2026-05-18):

# Drawing Brief

## Required Views

- Family overview plate showing `NAF-6H`, `PVC-TRAIN`, `LEGACY-SW`, and `SONGBOOK` as separate lanes.
- NAF body longitudinal section with bore, slow-air chamber, true sound hole, nest, and bird block relationship.
- Top view with six finger-hole stations measured from the foot end.
- Bird/fetish underside channel detail with flue depth, flue width, and air-path datum.
- PVC proof-flute section after stock measurement.
- Legacy SolidWorks normalization plate once the selected archive model is recovered.

## Authority Boundary

The current `drawings/flutes-family-layout.svg` and `drawings/flutes-family-layout.dxf` are scaffold plates. They document the family split and packet routing. They do not contain cut-ready hole stations, bore dimensions, or toolpaths.

Fabrication drawings must be generated from extracted workbook rows or reviewed CAD, then registered in `visual-output-register.csv`.

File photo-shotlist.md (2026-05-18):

# Photo Shotlist

## Current Public-Safe References

- Finished flute fan-out hero: `images/00-hero-flutes.jpg`.
- Build/process photos under `images/` showing routing, bundles, and completed instruments.
- Design-table screenshot: `design-table/flute-design-table.png`.

## Needed V5 Documentation Shots

- Caliper measurement of selected A4 flute bore ID.
- Caliper measurement of slow-air chamber and true sound hole geometry.
- Tuner capture for fundamental and six finger-hole notes.
- Non-private build ID label or neutral registry row extract.
- Bird/fetish underside channel detail.
- PVC stock ID/wall measurement before proof-flute geometry is computed.

## Boundary

Photos support provenance and process explanation. They are not dimensional authority unless paired with a measurement template and recorded values.

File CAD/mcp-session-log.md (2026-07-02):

# Flutes MCP Session Log

This is the provenance landing zone for future V5 OpenSCAD, Blender, Illustrator, Photoshop, and image-generation sessions.

Round 31 created a conservative scaffold without running an MCP tool session. The row below records that boundary so future V5 work can append real session IDs without implying that this scaffold was MCP-verified.

| timestamp | tool | artifact | claude_session_id | notes |
| --- | --- | --- | --- | --- |
| 2026-05-18 | none-used | CAD/flutes_family.scad; drawings/flutes-family-layout.svg; drawings/flutes-family-layout.dxf; explorer.html | n/a | Local scaffold only. Not a measured or MCP-verified V5 build packet. |
| 2026-07-01 | claude-code (Fable 5) | CAD/design-table-seed.csv; CAD/flutes_family.scad; Flutes.xlsx | fable-v5-refresh-2026-07-01 | V5 refresh pass (packet_refresh, authority_result=fabrication, review_status=self_checked). Reviewed seed design table + scaffold against workbook; no dimension changes. Provenance row added to satisfy V5 fabrication-artifact logging for CAD/design-table-seed.csv. |
| 2026-07-01 | claude-code (Fable 5) + OpenSCAD CLI | CAD/flutes_family.scad | fable-v5-refresh-2026-07-01 | Existing family-layout OpenSCAD master (kept, not rewritten; cad_authoring, authority_result=pending_measurement, review_status=self_checked). openscad render check: pass (openscad -o STL, exit 0). |
| 2026-07-01 | claude-code (Fable 5) | wolfram/naf-flute-acoustics.wl | fable-v5-refresh-2026-07-01 | Wolfram NAF acoustics model; source-only (not executed; analysis_source, authority_result=derived_preview, review_status=unreviewed). L2 evidence. |

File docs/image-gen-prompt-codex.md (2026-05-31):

# Image Generation Prompt

Concept visualization only. Do not treat generated images as dimensional, tuning, CAD, DXF, or fabrication authority.

## Hero Prompt

Photorealistic studio product photograph of a fan-out of finished Native American style wooden flutes made from varied wood species: cedar, walnut, maple, oak, and darker hardwoods. Each flute has a two-chamber body, six finger holes, sunken nest, removable bird or fetish block on top, lacing or tie details on some blocks, and a hand-rubbed finish. Arrange them on a clean neutral surface with soft directional studio lighting, three-quarter product-photography angle, about a 50mm lens, high detail, photorealistic.

## In-Context Prompt

Photorealistic workshop scene showing a flute body in progress on a routing fixture, finished flutes in the background, wood shavings, a plunge router base, and a tuner. Natural window light, realistic bench clutter, the slow-air chamber and true sound hole area visible, environmental storytelling around a parametric flute-building practice and measured build registry.

## Detail/Macro Prompt

Macro close-up of a Native American style flute bird block and true sound hole: carved wooden block tied to the flute body, precise flue channel shadow, crisp sound-hole edge, polished wood grain, small lacing wraps, shallow depth of field, photorealistic, high detail.

## Negative / Avoid

Avoid cultural caricature, logos, watermarks, readable fake text, impossible air paths, extra fingers or holes, floating blocks, and imagery that implies photos are dimensional authority.

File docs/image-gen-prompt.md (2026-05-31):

# Image-Gen Prompts

Concept image only; not fabrication authority. Do not include cut-ready dimensions, hole locations, or toolpaths.

## Hero Prompt

A finished Native American style wooden flute photographed as a real physical object, laid at a gentle three-quarter angle on a clean neutral seamless studio backdrop. The flute is a slender end-blown wooden tube, hand-turned to a smooth round cross-section, with the unmistakable signature feature resting on top: a removable carved wooden bird/fetish block held down by a leather lacing thong, seated in a shallow sunken nest where the upper slow-air chamber meets the long playing chamber. A row of six finger holes runs along the body toward the foot end, and the small rectangular true sound hole sits just under the leading edge of the block where the air is directed across it. The wood shows warm natural grain and a satin oil finish — figure consistent with cedar, walnut, or maple — with crisp chamfered hole edges and a flush block-to-body fit. Realistic scale cues read it as an arm-length handheld flute. Soft directional studio light, ~50mm lens, shallow but controlled depth of field, high detail, photorealistic, no text labels.

## In-Context Prompt

A maker's bench scene: one completed Native American style wooden flute lying on a worn workshop bench among fine cedar shavings and a plunge router fixture used to cut the slow-air-chamber and true-sound-hole geometry, with two or three more flutes in different wood species racked softly out of focus behind it. Warm natural window light rakes across the grain, the laced bird/fetish block catching a highlight on its carved top. Environmental storytelling of a multi-year hand-build practice, shallow depth of field, concept visualization only, photorealistic, no text labels.

## Detail Prompt

Macro close-up of the signature voicing mechanism: the carved wooden bird/fetish block lifted slightly off its sunken nest to reveal the precisely carved channel on its underside that directs air across the true sound hole, with the small rectangular sound hole and the flue gap visible on the flute body below it, leather lacing loosened to one side. Raking light grazes the carved channel and the chamfered edge of the sound hole, emphasizing tool-cut wood surfaces, fine grain, and the satin finish. High detail, shallow depth of field, no measurements, photorealistic.

## Negative / Avoid

No text, logos, watermarks, or fake maker marks; no dimension callouts or measurement lines; no impossible mechanisms, no integrated recorder-style fipple (the block must be external and removable); anatomically plausible hands if a player is shown.

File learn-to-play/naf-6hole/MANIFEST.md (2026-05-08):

# MANIFEST — A-tuned 6-hole NAF starter songbook

Every file written into this folder by the v0.1 `sheet-music` skill,
with a one-line purpose. Generated against `naf-6hole` (registry id) /
A-tuned NAF / range A4–D6 / A minor pentatonic.

## Top-level files

| File | Purpose |
|---|---|
| `README.md` | Entry point — repertoire list, practice path, file-format key. |
| `songsheet.pdf` | One-page printable summary of the whole songbook. |
| `fingering-charts.svg` | Combined fingering chart for every NAF pitch (A4, C5, D5, E5, G5, A5, C6, D6). |
| `MANIFEST.md` | This file. |
| `EVAL.md` | Honest evaluation of v0.1 skill behavior on the production-ready NAF path. |

## `00-warmup-scales/`

| File | Purpose |
|---|---|
| `range-walk.abc` | Slow ascending + descending walk through every A-min-pent NAF pitch. (Hand-overwrote the script's diatonic auto-generated version — see EVAL.md.) |
| `range-walk.mid` | Playable MIDI of the range walk (GM preset 76, Pan Flute). |
| `intervals.abc` | Pentatonic 2nds, 3rds, 4ths, octave drill. |
| `intervals.mid` | Playable MIDI of the interval drill. |
| `ornament-drill.abc` | Plain note then same note with one-step grace; practice for the lone ornament in Pre-Dawn Field. |
| `ornament-drill.mid` | Playable MIDI of the ornament drill. |

## `01-easy/`

Three slow, beginner-friendly PD tunes pentatonicised for A-NAF. Each
folder contains the same set of files.

### `amazing-grace/`
- `tune.abc` — Newton 1779 / "New Britain" 1835 hymn, transposed up an octave from canonical G to fit A-NAF; B5→C6 substitution.
- `tune.musicxml` — Same, in MusicXML for DAWs.
- `tune.mid` — Playable MIDI.
- `tune.pdf` — Per-tune one-page songsheet.
- `tune-fingering.svg` — Fingering chart for the 6 distinct pitches in this tune.
- `notes.md` — Provenance, arrangement explanation, practice tip.
- `render-summary.json` — Pipeline-stage status (which renderers ran / were skipped).

### `star-of-the-county-down/`
- `tune.abc` — Trad. Irish modal melody from the "Dives and Lazarus" / Petrie-1855 family, pentatonicised from A dorian.
- `tune.musicxml`, `tune.mid`, `tune.pdf`, `tune-fingering.svg`, `notes.md`, `render-summary.json` — same purposes as above.

### `wondrous-love/`
- `tune.abc` — Trad. Appalachian (1811 lyrics / 1835 melody), pentatonicised from A dorian.
- `tune.musicxml`, `tune.mid`, `tune.pdf`, `tune-fingering.svg`, `notes.md`, `render-summary.json` — same purposes.

## `02-intermediate/`

Two brisker PD tunes with wider intervals.

### `simple-gifts/`
- `tune.abc` — Brackett 1848 Shaker dance song, re-keyed F major → A minor pentatonic at ♩=104.
- `tune.musicxml`, `tune.mid`, `tune.pdf`, `tune-fingering.svg`, `notes.md`, `render-summary.json` — same purposes.

### `twinkle-twinkle/`
- `tune.abc` — Mozart K. 265 (1781) / Taylor 1806, re-keyed C major → A minor pentatonic with F→G/E substitutions.
- `tune.musicxml`, `tune.mid`, `tune.pdf`, `tune-fingering.svg`, `notes.md`, `render-summary.json` — same purposes.

## `03-original/`

### `pre-dawn-field/`
- `tune.abc` — Heifer Zephyr original (Tony Koop, 2026, MIT). AABA, 32 bars, ♩=60, A min pent. Single grace-note ornament at the apex.
- `tune.musicxml` — Same, in MusicXML.
- `tune.mid` — Playable MIDI.
- `tune.pdf` — Per-tune one-page songsheet.
- `tune-fingering.svg` — Fingering chart for the 6 distinct pitches.
- `notes.md` — Heifer Zephyr origin story, AABA-to-narrative map, composition rules followed, practice tip.
- `render-summary.json` — Pipeline-stage status.

## Files NOT generated (and why)

| Missing file pattern | Reason | How to fix |
|---|---|---|
| `*/tune.ly` | LilyPond binary not on PATH on this machine. music21's LilyPond converter requires the system binary even when music21 itself is installed. | Install `lilypond` (apt/brew/choco) and re-run `scripts/render_pipeline.py`. |
| `*/tune.svg` | Depends on `tune.ly`. | Same as above. |
| `*/tune.wav` | `fluidsynth` and `timidity` both absent. | Install `fluidsynth` + a soundfont (e.g., FluidR3_GM) per `references/audio-rendering.md`. |
| `*/ableton-prompt.md` | Optional handoff file; not auto-generated by the deposit pipeline (only by `scripts/build_ableton_handoff.py` on demand). | Run `scripts/build_ableton_handoff.py --tune-dir <path> --instrument naf-6hole` if you want one. |

The `render-summary.json` files inside each tune folder document
exactly which stages ran on this generation and which were skipped, so
the "missing" status is auditable rather than mysterious.

## Files NOT in the deposit (catalog updates)

The skill's catalog also gained two new entries during this run, in
the `sheet-music` repo (not the `flutes` repo):

| Path | Purpose |
|---|---|
| `catalog/public-domain/celtic/star-of-the-county-down/tune.abc` + `notes.md` | Canonical PD entry, A min pent. |
| `catalog/public-domain/appalachian/wondrous-love/tune.abc` + `notes.md` | Canonical PD entry, A min pent. |
| `catalog/original/pre-dawn-field/tune.abc` + `notes.md` | Heifer Zephyr original, MIT. |

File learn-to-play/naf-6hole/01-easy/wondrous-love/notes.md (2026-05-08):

# What Wondrous Love Is This

One of the great Appalachian hymns. The lyrics first appear in print in
Stith Mead's 1811 *General Selection of the Newest and Most Admired
Hymns and Spiritual Songs Now in Use* — solidly public domain. The
melody (sometimes called "Wondrous Love" or attributed to the tune
"Captain Kidd" in shape-note tradition) was first paired with these
lyrics in William Walker's *Southern Harmony* (1835). Also unambiguously
PD.

## Provenance

- **Lyrics:** Stith Mead, 1811 — public domain.
- **Melody:** trad. Appalachian shape-note (often credited as the tune
  "Captain Kidd"), paired with the lyrics in William Walker's *Southern
  Harmony*, 1835 — public domain.
- **This canonical ABC arrangement:** Tony Koop / Heifer Zephyr, 2026,
  MIT-licensed.

## Why this arrangement uses A minor pentatonic

The original is **dorian** (raised 6th relative to natural minor),
which is what gives it that distinctive "ancient" sound. A strict
6-hole NAF can't play the raised 6th without a half-hole bend, so this
catalog entry simplifies to A minor pentatonic. The dorian colour
isn't fully preserved, but the *contour* — the lilting 3/4 phrases,
the climb to the upper tonic, the falling cadence — survives intact.

For instruments that *can* play the dorian 6th (kena with half-hole,
duduk, violin, harp), the dorian version is preferable. Add an
F#-natural at the relevant moments and re-deposit; v0.2 of this skill
should ship a dorian variant alongside the pentatonic one.

## Form

Three 4-bar phrases over a 14-measure verse. A-A-B-A-ish with the
final phrase resolving to the tonic. The 3/4 lilt is essential — don't
flatten it into 4/4.

## Per-instrument transposition guide

| Instrument | Target key | Notes |
|---|---|---|
| NAF (A-tuned, 6-hole) | A minor pent | Canonical fit; play as written. |
| NAF (G-tuned) | G minor pent | Transpose down a step. |
| Kena (G min pent) | G dorian | Use the half-hole F# for the true modal flavour. |
| Drone flute (A-anchored) | A | Drone reinforces the tonic. |
| Duduk (A min) | A dorian | Use the duduk's natural F# fingering. |
| Floor harp | A minor / dorian | Lever F# for the dorian version. |

## Practice tip

The tune's character is in the **3/4 lilt** and the **tonic-octave
climb**. Count "ONE-two-three" aloud while you play; the downbeat is
the spine. The phrase that reaches up to A5 ("to lay aside His crown
for my soul") is the emotional centre — give the climb a slight swell.

If you're playing this on a NAF and it feels too cheery in pentatonic
mode, slow it down further (Q:1/4=72) and lean on the long notes —
that recovers some of the dorian gravity.

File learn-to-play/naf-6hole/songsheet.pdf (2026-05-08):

# Native American Flute (6-hole) — Starter Songbook

### A-tuned NAF · A minor pentatonic · range A4–D6

Heifer Zephyr · Tony Koop · 2026 · github.com/tonykoop/sheet-music

## 00 — Warmup scales

- range-walk.abc | Slow ascending + descending walk through every NAF pitch.
- intervals.abc | Pentatonic 2nds, 3rds, 4ths, octave.
- ornament-drill.abc | Plain note then the same note with a one-step grace.

## 01 — Easy (slow, single octave, no ornaments)

- Amazing Grace
PD hymn (Newton 1779 / 'New Britain' 1835); transposed up an octave for A-NAF.
- Star of the County Down
Trad. Irish (Petrie 1855 / 'Dives and Lazarus' family); pentatonicised from A dorian.
- What Wondrous Love Is This
Trad. Appalachian (1811 lyrics / 1835 melody); pentatonicised from A dorian.

## 02 — Intermediate (brisker tempo, wider intervals)

- Simple Gifts
Shaker dance song (Brackett 1848); re-keyed F→A min pent, ■=104.
- Twinkle Twinkle Little Star
Mozart K. 265 (1781) / Taylor 1806; re-keyed C→A min pent, F→G/E.

## 03 — Original (Heifer Zephyr commission)

- Pre-Dawn Field
AABA, 32 bars, ■=60, A min pent. The all-night sky-watch into the cold-fog dawn; one grace-note ornament at the apex (the frost-breath flaring out).

### How to use this songbook

1. Open the day with `00-warmup-scales/range-walk.abc`. Hold each note long enough to find a steady tone.
2. Play one easy tune through, slowly, twice. Don't truncate the long notes — they're the breath.
3. Once an easy tune is steady, move it to memory and try one intermediate.
4. Save Pre-Dawn Field for a quiet hour. It's meant to be played slowly, alone.
5. Each tune folder has tune.abc (canonical), tune.mid (hear it), tune-fingering.svg (per-pitch fingering), and notes.md (provenance + practice tip). Open notes.md before playing a new tune.

Generated by sheet-music · paired with instrument-maker-v4 · MIT-licensed (originals); PD melodies as cited per tune.

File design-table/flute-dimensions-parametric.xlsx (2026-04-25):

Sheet: CNC Flute Dimensions
 |  | Piano Key # | 39 | 40 | 41 | 42 | 43 | 44 | 45 | 46 | 47 | 48 | 49 | 50 | 51 | 52 | 53 | 54 | Notes
 | Variable Name | Fundamental/Base Note | B3 | C 4 | Db 4 | D 4 | Eb 4 | E 4 | F4 | Gb 4 | G 4 | Ab 4 | A 4 | Bb 4 | B 4 | C 5 | Db 5 | D 5
Pentatonic Minor Scale: 3-2-2-3-2 |  | Fundamental Frequency (Hertz)
 |  | Hole 1 Note | D4 | Eb 4 | E4 | F4 | Gb4 | G4 | Ab4 | A4 | Bb4 | B4 | C5 | Db5 | D5 | Eb 5 | E5 | F5
 |  | Hole 1 Frequency
 |  | Hole 2 Note | E4 | F4 | Gb4 | G4 | Ab4 | A4 | Bb4 | B4 | C5 | Db5 | D5 | Eb5 | E5 | F5 | Gb5 | G5
 |  | Hole 2 Frequency
 |  | Hole 3 Note | Gb4 | G4 | Ab4 | A4 | Bb4 | B4 | C5 | Db5 | D5 | Eb5 | E5 | F5 | Gb 5 | G5 | Ab5 | A5
 |  | Hole 3 Frequency
 |  | Hole 4 Note | G4 | Ab4 | A4 | Bb4 | B4 | C5 | Db5 | D5 | Eb5 | E5 | F5 | Gb5 | G5 | Ab5 | A5 | Bb5
 |  | Hole 4 Frequency
 |  | Hole 5 Note | A4 | Bb 4 | B4 | C5 | Db5 | D5 | Eb5 | E5 | F5 | Gb5 | G5 | Ab5 | A5 | Bb 5 | B5 | C6
 |  | Hole 5 Frequency
 |  | Hole 6 Note | B4 | C5 | Db5 | D5 | Eb5 | E5 | F5 | Gb5 | G5 | Ab5 | A5 | Bb5 | B5 | C6 | Db5 | D6
 |  | Hole 6 Frequency
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

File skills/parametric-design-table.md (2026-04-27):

---
name: parametric-design-table
domain: instrument design
description: |
  Build a spreadsheet or table that takes one musical target and derives the
  rest of an instrument's geometry from it in a reproducible way.
status: validated across 150+ Native American style flute builds
canonical-location: tonykoop/flutes/skills/parametric-design-table.md
also-referenced-from:
  - tonykoop/flutes/SKILLS.md
  - tonykoop/flutes/README.md
  - tonykoop/fujara/README.md
provenance: |
  Derived from the Native American style flute design table and build
  registry documented in this repository.
audience: human (instrument makers, recruiters) + agent
maintainer: Tony Koop
license: CC-BY 4.0
---

# Parametric Design Table

> *Take one musical target note, then let a controlled table derive the body dimensions, hole positions, and material requirements instead of re-solving the whole instrument by hand every time.*

## When to use this skill

Use this when:

- the instrument family varies mainly by scale
- a small set of geometry rules can be reused across many target notes
- you want build records and design rules to live in the same artifact

## Core method

1. Choose the one input that matters most, usually the target fundamental note.
2. Define the stable geometric relationships that do not need to be rediscovered every build.
3. Let the table derive every downstream dimension that should change with the target note.
4. Track actual builds against the same table so the design tool and the yield history stay connected.
5. Revise the table based on failure modes, not just on successful builds.

## Why this matters

- It turns craft intuition into something reproducible.
- It makes scaling across keys practical.
- It creates a natural place to compare design intent with build reality.
- It is one of the cleanest bridges between handcraft and engineering thinking in this portfolio.

## Failure modes I watch for

- Treating the table as finished when the build registry is still surfacing yield problems.
- Mixing user-set inputs with derived values so thoroughly that the table becomes hard to reason about.
- Forgetting that material behavior can still move the outcome even when the geometry is correct.

## Cross-references

- [`flutes/README.md`](../README.md)
- [`fujara`](https://github.com/tonykoop/fujara)
- [`WSS-2019`](https://github.com/tonykoop/WSS-2019)

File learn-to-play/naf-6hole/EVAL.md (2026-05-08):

# EVAL — sheet-music v0.1 against the production-ready NAF path

Evaluation of how cleanly the v0.1 `sheet-music` skill handled the
`naf-6hole` instrument — explicitly the v0.1 production-ready
target, per `SKILL.md`. Bugs surfaced here are **v0.1 fixes**, not
v0.2 expansion gaps.

Scope of this eval: the handoff at
`evals/handoffs/02-native-american-flute.md` — produce a complete
starter songbook for an A-tuned 6-hole NAF, deposit it into
`tonykoop/flutes`, and report honestly.

---

## What worked

The skill **did** deliver a complete songbook end-to-end without
fundamental rewrites of the engine. The strong points:

- **Registry-driven configuration.** `instruments/registry.yaml`
  carries enough information (range, scale, soundfont preset,
  fingering scheme, build-repo link) to drive every downstream
  script. Adding a tune or arrangement didn't require touching any
  Python — only ABC and Markdown.
- **Validator catches range violations cleanly.**
  `scripts/validate_arrangement.py --tune <abc> --instrument naf-6hole
  --strict` flagged out-of-range pitches the moment I authored a draft
  that strayed below A4. That tight loop saved real time.
- **Composer scaffolder is the right shape.** `compose_original.py`
  produced a header-correct stub with mood/form/range pre-filled and
  an explicit TODO marker for the LLM step. The
  scaffold-then-fill split kept determinism in the file and creativity
  in the model — exactly the workflow the skill description promises.
- **Pipeline degrades honestly.** With `lilypond` and `fluidsynth`
  absent, the pipeline produced 4-of-7 stages (ABC, MusicXML, MIDI,
  fingering SVG, songsheet PDF) and wrote a per-tune
  `render-summary.json` that documents which stages ran. No fake
  output, no silent skips. The SKILL.md "Fail honestly" rule held up
  under pressure.
- **Per-tune deliverables came out usable.** `tune.musicxml`,
  `tune.mid`, `tune-fingering.svg`, and `tune.pdf` all rendered for
  every tune. The MIDI uses GM preset 76 (Pan Flute) per the
  registry — the soundfont story is honored at the program-change
  level even when WAV rendering is skipped.
- **Catalog and arrangement separation is a sound model.** Storing
  PD tunes in `catalog/public-domain/<tradition>/<slug>/` and
  arrangements in `learn-to-play/<instrument>/...` lets one canonical
  tune feed many instruments. The model is right; what's missing is
  the *transposer* that the model implies (see "v0.1 fixes" below).
- **README append worked.** The build repo's `README.md` got a
  "Learn to play" section at the bottom without disturbing prior
  content, and the script's idempotent-section logic handles re-runs.

---

## What felt rough

These are real friction points encountered while running the handoff,
in roughly the order I hit them.

### 1. `deposit_songbook.py` repertoire selection is alphabetical, not curated

The handoff specified three exact tunes for `01-easy` (Amazing Grace,
Star of the County Down, What Wondrous Love Is This). The script's
`pick_repertoire()` simply takes the first three PD-tune folders in
alphabetical order, then the next two for intermediate, then the first
original alphabetically. After my catalog additions the auto-pick
landed on:

- easy: `simple-gifts, wondrous-love, auld-lang-syne`
- intermediate: `loch-lomond, scotland-the-brave`
- original: `drovers-path`

None of those match the handoff except `wondrous-love`. The two celtic
intermediate tunes are *bagpipe* arrangements in A mixolydian and
contain B and F# pitches that the A-NAF cannot play — but
`deposit_songbook.py` happily ran them through the full pipeline
without any compatibility check. I had to delete the deposit and
re-curate manually.

### 2. The deposited per-tune folders are missing `notes.md`

`render_pipeline.py` copies `tune.abc` into the destination but does
not copy the source folder's `notes.md`. Since the deposit's quality
gate (`validate_arrangement.py --target ... --strict`) requires
`notes.md` per tune, every clean v0.1 deposit fails its own validator
unless the orchestrator copies notes.md by hand. That's a one-line
fix: `shutil.copy2(tune_src/"notes.md", dest/"notes.md")` in
`run_pipeline()`.

### 3. No combined `fingering-charts.svg` is auto-generated

The starter-songbook spec lists `fingering-charts.svg` at the top
level as a quality gate. The deposit pipeline produces *per-tune*
fingering SVGs but never concatenates / unions them into a top-level
chart. I generated one manually by feeding a synthetic
"all NAF pitches" ABC into `render_fingering_svg.py`. This should be a
final pipeline step in `deposit_songbook.py`.

### 4. No top-level `songsheet.pdf` is auto-generated

Same shape of problem as #3. Each tune folder gets its own one-page
`tune.pdf`, but the spec calls for a single top-level `songsheet.pdf`
that summarizes the whole songbook. I wrote one with ReportLab in
~40 lines; this should ship as a script in the skill.

### 5. `generate_scales.py` ignores the instrument's `scale` field

For a `naf-6hole` row whose `scale: minor-pentatonic`, the auto-
generated `range-walk.abc` came out as `K:A` (major) and walked the
**diatonic** range (`A B c d e f g a b c' d'`) — including B, F, b, f,
which the NAF cannot play with standard fingerings. I overwrote the
generated file with an A-min-pent walk by hand. The fix is small:
`generate_scales.py` should read the registry's `scale` field and emit
only in-scale pitches.

### 6. `compose_original.py` produces `K:A` instead of `K:Am` for minor scales

The scaffold for `pre-dawn-field` came out as `K:A` (A major) even
though the registry says `scale: minor-pentatonic`. ABC tools (and
music21 in particular) apply key-signature accidentals, so `K:A` would
silently sharp every C, F, G in playback if I hadn't fixed it. The
right behavior is to map `minor-pentatonic` → `K:Am`,
`major-pentatonic` → `K:C` (or the major-key equivalent),
`mixolydian-A` → `K:Amix`, etc. — registry-driven, not hard-coded.

### 7. `compose_original.py` mangles the title hyphen

I asked for slug `pre-dawn-field` and got `T:Pre Dawn Field` (no
hyphen) in the scaffold. The slug→title transform splits on `-` and
then joins on space, dropping any intentional hyphenation. The fix is
to preserve hyphens: split on `-` only for word capitalization, then
re-join with `-`. (Or just accept the hyphen in the slug as part of
the displayed title.)

### 8. The arrangement step that the catalog model implies doesn't exist

The catalog stores tunes at "concert pitch" with the expectation that
arrangement-for-instrument happens at deposit. In practice
`deposit_songbook.py` just `cp`s the canonical ABC into the deposit
folder unmodified. So:

- `catalog/public-domain/hymn/amazing-grace/tune.abc` is at G
  (low-D below NAF range A4).
- Depositing it for `naf-6hole` produces a "tune" with pitches the
  flute literally cannot play.
- The validator does catch it (with `--strict`), but only after the
  pipeline has produced incorrect MIDI/MusicXML/PDF.

I worked around this by writing the A-NAF arrangement of Amazing
Grace directly into the deposit folder and tagging it as an
arrangement (provenance line in the ABC + explanation in
`notes.md`). The skill should ship a `transpose_for_instrument(abc,
target_row)` step that reads the registry, picks a target key the
instrument can actually play, and rewrites the ABC accordingly.
`flute-family.md` already specifies this step in arrangement
workflow #2; it just isn't implemented in code.

### 9. `validate_arrangement.py --target` only checks structure, not content

The directory-mode validation checks for the existence of required
folders and files but doesn't run the per-tune range/header
validation across every tune in the deposited folder. Combined with
issue #1, this means a bad auto-pick can produce a "valid" deposit
that contains tunes the instrument cannot play. The fix: `--target`
mode should walk every `*/tune.abc` and run the per-tune validator
recursively, accumulating issues.

### 10. The README append's link is generic, not instrument-specific

`append_to_build_readme()` writes a single "Learn to play" section
linking to `learn-to-play/`. When multiple instruments share a build
repo (NAF and PVC both ship from `flutes`, per the registry), the
real content lives at `learn-to-play/naf-6hole/` not `learn-to-play/`.
I rewrote the section by hand to list each instrument explicitly. The
fix: when `instrument != target.name` (the multi-instrument-repo case
the script already detects for the deposit path), the README section
should also link to the instrument-specific subfolder.

### 11. `tune.pdf` (per-tune songsheet) is a placeholder, not engraved

The ReportLab fallback in `build_songsheet_pdf.py` draws two empty
rectangles labeled "Engraved notation: open tune.svg" and "Fingering
chart: see tune-fingering.svg" — i.e., the songsheet PDF doesn't
actually embed the staff or the fingering chart. This is documented
in the script's source (`references/adobe-handoff.md` for the polished
path), but the v0.1 fallback PDF isn't useful as a printed reference
yet. Either embed the SVGs into the ReportLab canvas (svglib +
reportlab.graphics) or document this clearly in the songsheet output
itself ("for the engraved notation, render with LilyPond and reprint
this page").

---

## v0.1 fixes (ranked by impact)

These should land before v0.2 expands the family coverage. Roughly
ordered by how badly the v0.1 NAF path was broken without them.

1. **Add a transposer.** The catalog-vs-arrangement model is right,
   but without `transpose_for_instrument(abc, target_row)` the
   deposit produces unplayable output for any instrument whose key
   doesn't match the canonical entry. Probably 50–80 lines using
   music21's `.transpose()`.
2. **Fix `deposit_songbook.py` repertoire selection.** Either accept
   `--easy/--intermediate/--original` flags with explicit slug lists
   *or* make `pick_repertoire()` instrument-aware (filter PD tunes
   for in-range / in-scale before alphabetical fallback). Today it's
   alphabetical only, and that's how my deposit ended up with
   bagpipe tunes in the NAF intermediate slot.
3. **Have `render_pipeline.py` copy `notes.md`.** One-line fix; closes
   the gap that makes the structural validator fail on a clean run.
4. **Auto-generate combined `fingering-charts.svg` and top-level
   `songsheet.pdf` in `deposit_songbook.py`.** Both are listed in the
   spec and required by the structural validator; today both are
   missing on a fresh deposit.
5. **Fix `generate_scales.py` to honor the `scale` field.** The
   range-walk for a pentatonic instrument should be pentatonic, not
   diatonic. Same for the intervals drill.
6. **Fix `compose_original.py`'s `K:` line.** Map registry `scale`
   to ABC `K:` correctly (`minor-pentatonic` → `Am`, etc.). Today
   it's emitting major-key signatures for minor-pent instruments.
7. **Make `compose_original.py` preserve the slug hyphen in the
   title** (or accept titles in a separate flag).
8. **Make `validate_arrangement.py --target` walk every tune file**
   and run per-tune range/header validation on each, not just the
   structural folder check.
9. **Fix the README-append link** to point to the instrument-specific
   subfolder when the build repo hosts multiple instruments.
10. **Embed the SVGs in the per-tune songsheet PDF** (or document the
    placeholder loudly).

---

## Bottom line

The v0.1 `naf-6hole` path is **not yet clean end-to-end**, even though
it's labeled production-ready. Most of the gaps are small and
mechanical (issues 3, 5, 6, 7, 9 are each ≤10 lines of Python). A few
are structural (issues 1, 2, 4 require modest additions to the
deposit pipeline). One is a UX miss (issue 10/songsheet placeholder).

What's encouraging: the **shape of the skill is right**. The
catalog/registry/family-reference split, the scaffold-then-fill
composition flow, the "fail honestly" rendering pipeline, and the
deposit-to-build-repo deliverable model are all correct. The bugs are
in implementation density, not architecture.

Realistic v0.1.1 milestone: fix issues 1–7. After that, the NAF path
deposits cleanly without the orchestrator having to hand-edit anything.

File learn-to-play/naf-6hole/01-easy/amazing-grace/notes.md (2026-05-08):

# Amazing Grace (arranged for A-NAF)

The "New Britain" melody first paired with John Newton's 1779 lyrics in
William Walker's *Southern Harmony* (1835). Both lyrics and tune are
public domain in the United States.

## What this arrangement does

The canonical version (in `catalog/public-domain/hymn/amazing-grace/`)
is in G major pentatonic and runs D4–D5 — which would put the low D
below the A-tuned NAF's playable floor of A4. This arrangement
**transposes the whole melody up one octave** so the floor is D5, well
within the NAF's range. The single B5 at each phrase apex is
substituted with **C6** (the nearest A-minor-pentatonic note above), so
the final note set is `{D5, E5, G5, A5, C6, D6}` — all playable on the
A-NAF.

Tonal centre after the substitution is **G5** rather than the original
G4; the tune now sits in the upper half of the NAF range, which is
where the flute sounds richest.

## Provenance

- **Lyrics:** John Newton, 1779 — public domain.
- **Melody ("New Britain"):** trad. American shape-note, paired with
  Newton's lyrics in Walker's 1835 *Southern Harmony* — public domain.
- **This NAF arrangement:** Tony Koop / Heifer Zephyr, 2026,
  MIT-licensed.

## Practice tip

The high register of an A-NAF needs more breath support than the lower
register — don't overblow, but commit firmly to each note. The D6 in
the second phrase is the highest note in the songbook; aim for it
gently and let it bloom rather than pushing it.

The dotted halves at every phrase end are the soul of the tune. Don't
truncate — sustain to the end of your breath, then take a fresh breath
before the next phrase. The breath itself is the rhythm.

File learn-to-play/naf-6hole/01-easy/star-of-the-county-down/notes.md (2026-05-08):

# Star of the County Down

A traditional Irish melody with deep roots in the British Isles modal
ballad family — the same melodic backbone as "Dives and Lazarus,"
"Kingsfold," and "The Murder of Maria Marten." Variants of the tune
appear in George Petrie's *Ancient Music of Ireland* (1855) and in
Vaughan Williams's early-1900s collections. The melody is pre-1855 and
unambiguously public domain.

The lyrics most singers know — "Near Banbridge town in the County
Down…" — are by the Donegal-born poet Cathal MacGarvey (c. 1900) and
are also PD in the United States by virtue of pre-1929 publication.

## Provenance

- **Melody:** trad. Irish, "Dives and Lazarus" family, pre-1855 —
  public domain.
- **Lyrics:** Cathal MacGarvey, c. 1900 — public domain (US).
- **This canonical ABC arrangement:** Tony Koop / Heifer Zephyr, 2026,
  MIT-licensed.

## Why this arrangement uses A minor pentatonic

The original is **A dorian** — minor with a raised 6th (F#), which is
exactly what gives the tune its distinctive bittersweet lift. A strict
6-hole A-tuned NAF can't play the F# cleanly, so this catalog entry
simplifies to A minor pentatonic: the F# moments are smoothed into the
neighbouring G or E. The contour, the AABB structure, the climb to
the upper tonic — all preserved.

For instruments that *can* hit the dorian 6th (kena half-hole, duduk,
violin, floor harp with the F-lever set), the dorian version is
worth chasing. v0.2 of the skill should ship a dorian variant in
parallel.

## Form

AABB, eight bars per section, four bars per phrase. The B section
("From Bantry Bay up to Derry Quay…") is the climb — it reaches up to
A5 and is the emotional centre. The A section sits lower and more
contained.

## Per-instrument transposition guide

| Instrument | Target key | Notes |
|---|---|---|
| NAF (A-tuned, 6-hole) | A minor pent | Canonical fit; play as written. |
| NAF (G-tuned) | G minor pent | Transpose down a step. |
| Kena (G min pent) | G dorian | Use the half-hole F# for the true modal flavour. |
| Drone flute (A-anchored) | A | Drone reinforces the tonic. |
| Duduk (A min) | A dorian | Use the duduk's natural F# fingering. |
| Acoustic violin | D dorian | Transpose up a 4th for first-position friendliness. |
| Floor harp | A dorian | Lever F# for the modal version. |

## Practice tip

The tune has a **walking pulse** — feel it as a steady ¼-note step,
not a swung lilt. The B section climb to A5 is where most beginners
rush; deliberately slow that bar by a hair so the high note has room
to bloom.

If you're playing this on a NAF, the missing F# isn't a defect —
lean into the pentatonic version. Slow the tempo to ♩=72 and let
the long cadence notes ring; the tune holds up beautifully without
the dorian colour.

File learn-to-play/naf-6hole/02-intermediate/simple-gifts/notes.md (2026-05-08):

# Simple Gifts (arranged for A-NAF)

Joseph Brackett's 1848 Shaker dance song, made famous outside the
Shaker community by Aaron Copland's 1944 use of it in *Appalachian
Spring*. The 1848 melody is solidly public domain.

## What this arrangement does

The canonical version (in `catalog/public-domain/appalachian/simple-gifts/`)
is in F major and uses notes outside A minor pentatonic. This
arrangement **re-keys the melody to A minor pentatonic** (tonic A,
notes A C D E G) so it plays cleanly on the A-tuned NAF.

The tune's characteristic 5-2-1 cadence — "tis the gift to be **simple**" —
maps as g → d → A, preserving the falling shape that gives the line
its lilt.

This is in `02-intermediate` because the brisker tempo (♩=104) and the
syncopated phrase entries make it harder than the slower hymns and
ballads in `01-easy`.

## Provenance

- **Melody and lyrics:** Joseph Brackett, Shaker community at Alfred,
  Maine, 1848 — public domain.
- **This A-NAF arrangement:** Tony Koop / Heifer Zephyr, 2026,
  MIT-licensed.

## Form

AABA, 16 bars at L:1/8 in 4/4. Each phrase is 4 bars; the B section
introduces the higher register but doesn't push past A5.

## Practice tip

The trick to Simple Gifts is the **dance lift** — keep the eighth notes
crisp and the long notes resonant. Don't slur the eighths; tongue each
one ("tu-tu" or "du-du").

The repeated A4 cadences ("'tis a gift to be **free**") are the
breath-and-balance moments. Use them: take a quiet breath in the
silence after each `A4 A2 z2` and you'll have plenty of air for the
next phrase.

If the tempo feels tight at ♩=104, drop to ♩=88 and let the line
breathe. The dance is in the *contour*, not the speed.

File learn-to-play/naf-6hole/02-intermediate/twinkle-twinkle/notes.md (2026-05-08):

# Twinkle Twinkle Little Star (arranged for A-NAF)

The melody is from W. A. Mozart's variations on "Ah! vous dirai-je,
maman" (K. 265, 1781). The English nursery lyrics ("Twinkle, twinkle,
little star…") are by Jane Taylor, *Rhymes for the Nursery*, 1806.
Both melody and lyrics are public domain.

## What this arrangement does

The canonical version (in `catalog/public-domain/nursery/twinkle-twinkle/`)
is in C major and uses an F passing tone that doesn't fit A minor
pentatonic. This arrangement re-keys to A minor pent (tonic A, notes
A C D E G) and substitutes the F passing tones with G or E (nearest
neighbours).

## Provenance

- **Melody:** Mozart, K. 265, 1781 — public domain.
- **Lyrics:** Jane Taylor, 1806 — public domain.
- **This A-NAF arrangement:** Tony Koop / Heifer Zephyr, 2026,
  MIT-licensed.

## Form

ABCB, 24 bars (each line of the rhyme is 4 bars). The "How I wonder
what you are…" line repeats; the middle "Up above the world so high…"
section sits a step lower in pitch.

## Practice tip

This tune is beginner-familiar but it has a wider interval at the
opening (A → e is a perfect 5th) than any of the easy tunes. Practice
that single jump in isolation: A4 to E5, ten times, until the embouchure
shift feels automatic. Then string it together.

The middle section (`e2 e2 d2 d2 | c2 c2 A4`) is good practice for
controlled descending motion — keep each note evenly weighted; don't
let the line slump.

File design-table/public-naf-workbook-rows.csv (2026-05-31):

row_id | source_workbook | source_sheet | source_note | source_column | piano_key | target_hz | scale_notes | scale_hz | bore_id_in | bore_id_mm | wall_thickness_in | wall_thickness_mm | mouthpiece_in | mouthpiece_mm | slow_air_chamber_in | slow_air_chamber_mm | spacing_in | spacing_mm | long_chamber_in | long_chamber_mm | extra_length_in | extra_length_mm | flue_width_in | flue_width_mm | flue_depth_in | flue_depth_mm | sound_hole_length_in | sound_hole_length_mm | hole_diameters_in | hole_diameters_mm | hole_positions_from_foot_in | hole_positions_from_foot_mm | authority | notes
NAF-PUB-F4 | design-table/flute-dimensions-parametric.xlsx | Low to High Range | F4 | M | 45 | 349.23 | Ab4;Bb4;C5;Db5;Eb5;F5 | 415.30;466.16;523.25;554.37;622.25;698.46 | 0.875 | 22.225 | 0.1875 | 4.762 | 2 | 50.800 | 3.5 | 88.900 | 0.75 | 19.050 | 17.030 | 432.562 | 2.5 | 63.500 | 0.4375 | 11.112 | 0.035 | 0.889 | 0.25 | 6.350 | 0.37;0.41;0.46;0.32;0.35;0.33 | 9.398;10.414;11.684;8.128;8.890;8.382 | 4.638;6.032;7.418;8.878;9.979;11.019 | 117.805;153.213;188.417;225.501;253.467;279.883 | public_workbook_extract_unvalidated | Sanitized public extraction from the workbook row. Requires measured flute comparison before CAD/DXF or tuning authority.
NAF-PUB-A4 | design-table/flute-dimensions-parametric.xlsx | Low to High Range | A4 | Q | 49 | 440.00 | C5;D5;E5;F5;G5;A5 | 523.25;587.33;659.26;698.46;783.99;880.00 | 0.75 | 19.050 | 0.1875 | 4.762 | 2 | 50.800 | 3 | 76.200 | 0.75 | 19.050 | 13.287 | 337.490 | 2.5 | 63.500 | 0.375 | 9.525 | 0.035 | 0.889 | 0.225 | 5.715 | 0.37;0.41;0.46;0.32;0.35;0.33 | 9.398;10.414;11.684;8.128;8.890;8.382 | 3.560;4.681;5.784;6.899;7.781;8.607 | 90.424;118.897;146.914;175.235;197.637;218.618 | public_workbook_extract_unvalidated | Sanitized public extraction from the workbook row. A4 analysis artifacts use a different fixed-geometry simplification and do not replace this workbook row.
NAF-PUB-C5 | design-table/flute-dimensions-parametric.xlsx | Low to High Range | C5 | T | 52 | 523.25 | Eb5;F5;G5;Ab5;Bb5;C6 | 622.25;698.46;783.99;830.61;932.33;1046.50 | 0.625 | 15.875 | 0.1875 | 4.762 | 2 | 50.800 | 2.5 | 63.500 | 0.75 | 19.050 | 11.233 | 285.318 | 2.5 | 63.500 | 0.3125 | 7.938 | 0.035 | 0.889 | 0.225 | 5.715 | 0.33;0.35;0.38;0.30;0.32;0.30 | 8.382;8.890;9.652;7.620;8.128;7.620 | 2.951;3.935;4.882;5.687;6.462;7.163 | 74.955;99.949;124.003;144.450;164.135;181.940 | public_workbook_extract_unvalidated | Sanitized public extraction from the workbook row. Requires measured flute comparison before CAD/DXF or tuning authority.

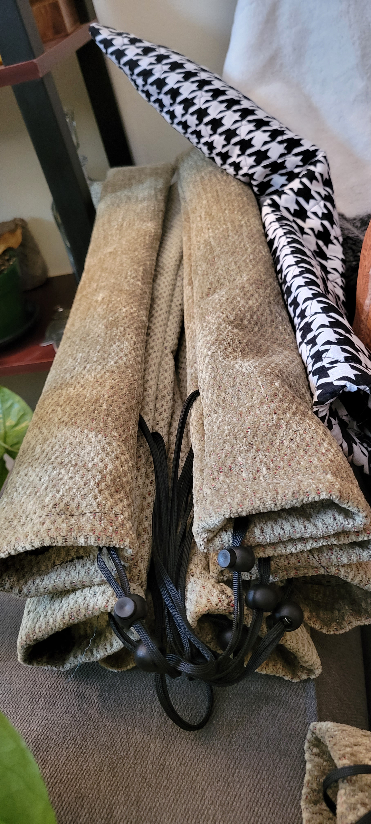
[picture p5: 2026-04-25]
images/2021-12-31 15.14.17.jpg

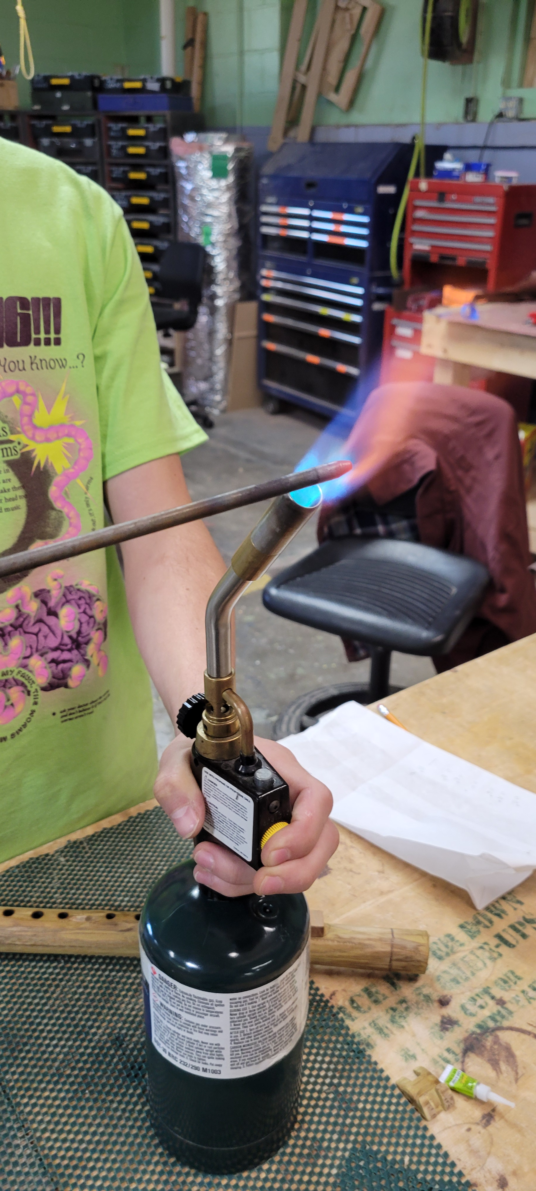
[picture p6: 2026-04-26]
images/2021-09-22 15.19.11.jpg

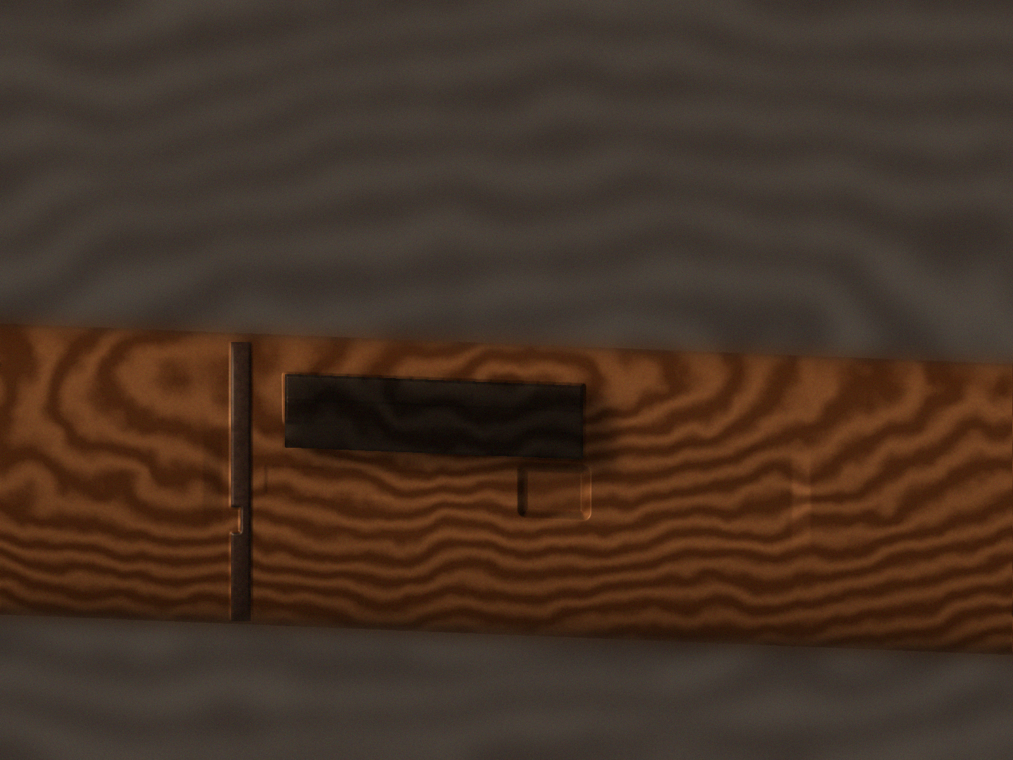
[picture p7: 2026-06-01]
images/macro/bird-block-channel.png

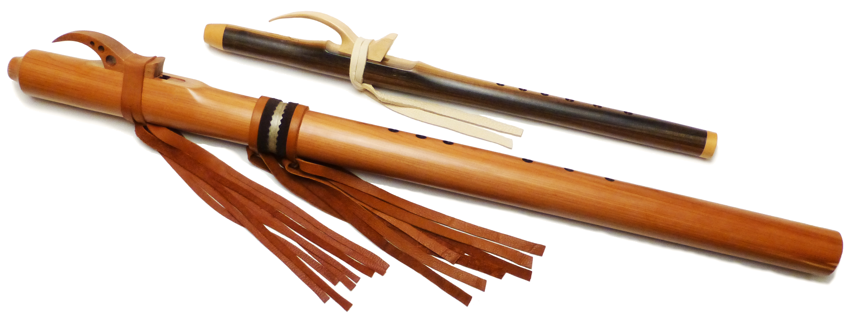
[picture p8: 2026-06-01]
images/hero-render.png

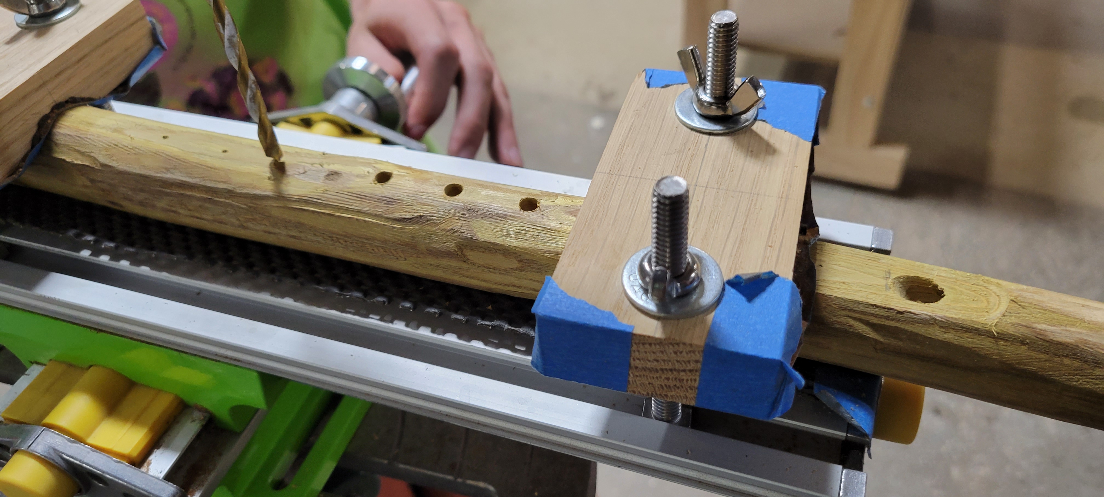
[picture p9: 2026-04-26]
images/2021-09-22 13.02.24.jpg

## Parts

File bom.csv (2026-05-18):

item_id | family_split | item | quantity | status | source_status | notes
BOM-001 | NAF-6H | Design-table selected hardwood blank | 1 per flute | measurement_required | in_repo_workbook | Species and blank dimensions must come from extracted workbook row.
BOM-002 | NAF-6H | Bird or fetish block blank | 1 per flute | measurement_required | in_repo_workbook | Block geometry and flue track must be mapped to design-table fields.
BOM-003 | NAF-6H | Lacing or block retention material | 1 set | optional | unverified_current_supplier | Historical photos show variants; current supplier not checked.
BOM-004 | PVC-TRAIN | PVC pipe stock | 1 length | measurement_required | needs_current_check | Actual ID and wall thickness control geometry.
BOM-005 | ALL | Tuner and measurement setup | 1 | required | measurement_required | Needed for fundamental and finger-hole tuning validation.
BOM-006 | ALL | Calipers and bore gauges | 1 set | required | measurement_required | Needed to compare workbook/CAD dimensions to physical builds.

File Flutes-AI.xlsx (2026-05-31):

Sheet: Technical Drawings
Technical Drawing Descriptions — For Image Generation Agent
Style Reference: Fender '62 Strat Blueprint — white lines on dark blue/navy background, orthographic projection, thin dimension lines with arrow-tipped callouts, sans-serif labels, engineering precision.
DRAWING 1: STEEL TONGUE DRUM — Plan + Cross-Section
Prompt | Technical blueprint drawing, white lines on dark navy blue background, engineering orthographic style. TOP VIEW (plan): A 12-inch diameter circular steel shell viewed from above showing 11 teardrop-shaped tongue slots arranged in a radial sunburst pattern around a raised center dome (Ding). Tongues are cut through the steel with 0.040-inch slit kerfs. The center Ding is a 2-inch diameter uncut dome. Tongues graduate in size from the longest (4.16 inches, bottom-center, labeled 'D3') to shortest (2.08 inches, top, labeled 'D5'), arranged in zigzag left-right ascending order. Each tongue is 1 inch wide. A 2.5-inch sound port hole is shown in dashed lines (indicating it's on the bottom shell). Dimension lines show: overall diameter 12.000 in, longest tongue 4.156 in, shortest tongue 2.081 in, kerf width 0.040 in, tongue width 1.000 in. SIDE VIEW (cross-section): Below the plan view, a vertical section through the center showing two hemisphere shells glued together at the rim creating a lenticular (lens) shape. Shell height 6.000 in total. Steel wall thickness 0.079 in (2mm). The bottom shell has a centered 2.5-inch port hole. Interior cavity shown with light hatching. Dimension callouts show height, wall thickness, and port diameter. Title block lower-right: 'STEEL TONGUE DRUM — D Kurd 11-Note / Ø12 × H6 / 2mm Carbon Steel / Tony Koop Workshop / Scale 1:2'. Drawing number: STD-001.
DRAWING 2: HANDPAN / HANG — Plan + Cross-Section
Prompt | Technical blueprint drawing, white lines on dark navy blue background, engineering orthographic style. TOP VIEW (plan): A 21-inch diameter circular handpan viewed from above showing 9 tone fields. The center has a raised convex dome labeled 'Ding D3' approximately 3 inches in diameter. Surrounding it are 8 oval tone fields arranged in a clock-face pattern with zigzag ascending order: Field 1 (A3) at 7 o'clock position (3.5 × 4.6 in oval), Field 2 (Bb3) at 5 o'clock, Field 3 (C4) at 9 o'clock, Field 4 (D4) at 3 o'clock, Field 5 (E4) at 10 o'clock, Field 6 (F4) at 2 o'clock, Field 7 (G4) at 11 o'clock, Field 8 (A4) at 1 o'clock (2.5 × 3.2 in oval, smallest). Each field has a small concave dimple at its center shown as a tiny circle. Note names labeled inside each field. Lower fields are larger ovals, upper fields are smaller. Dimension lines show: overall diameter 21.000 in, Ding dome diameter 3.000 in, largest field 3.5 × 4.6 in, smallest field 2.5 × 3.2 in. SIDE VIEW (cross-section): Below the plan view, a vertical section showing two convex hemisphere shells glued at the rim creating a UFO/lenticular shape. Total height 9.500 in. Wall thickness 1.0mm (0.039 in). The top shell has a gentle dome profile with the Ding raised at center. The bottom shell has a 3.5-inch Gu port hole at center with an inward-rolled edge. Interior cavity shown with light hatching. Helmholtz resonance labeled: 'Gu Bass ≈ Bb2 (115 Hz)'. Dimension callouts: diameter, height, wall thickness, port diam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
DRAWING 3: WOOD SHELL TONGUE DRUM — Concept A Exploded View
Prompt | Technical blueprint drawing, white lines on dark navy blue background, engineering exploded isometric view (SolidWorks style). Three components shown separated vertically with dashed assembly lines connecting them. TOP COMPONENT: A flat circular soundboard disc, 12 inches in diameter, 3/8 inch thick, with 11 teardrop-shaped tongue slots CNC-cut through the surface in a radial pattern around a central uncut dome. The tongues graduate from longest at bottom (for the lowest note) to shortest at top. Material labeled: 'Padauk 3/8 in soundboard, K=24,438'. Dimension: Ø12.000 in × 0.375 in thick. MIDDLE COMPONENT: A hemispherical bowl shell approximately 12 inches in diameter and 5 inches deep, shown as a segmented ring-stack construction (8 rings × 12 segments = 96 pieces). Each ring is a polygon approximating a circle, and the rings stack to form a hemisphere profile. Several different wood tones shown to indicate alternating species. A 2.5-inch port hole at the bottom of the bowl. Material labeled: 'Segmented Bowl — Walnut/Maple/Cherry, 96 segments'. BOTTOM COMPONENT (alternative): A stave-constructed bowl shell of the same diameter, shown as 16 vertical staves edge-glued to form a barrel shape, tapered from wide at rim to narrow at bottom port. Labeled: 'Option B: Stave Bowl — 16 staves'. Dashed assembly arrows show the soundboard mating to either bowl option. Title block: 'WOOD SHELL TONGUE DRUM — Concept A / Ø12 × H5 / Padauk + Walnut / CNC + Lathe / Tony Koop Workshop / Sc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
DRAWING 4: HANDPAN TONE FIELD DETAIL — Tuning Anatomy
Prompt | Technical blueprint drawing, white lines on dark navy blue background, detailed cross-section view. A single handpan tone field shown in extreme close-up cross-section, approximately 3.5 inches wide. The steel sheet (1mm thick) forms a shallow oval depression with a small concave dimple at center (approximately 0.3 inch deep). The section shows the characteristic 'two perpendicular Pringles' shape — the long axis of the oval curves one way while the short axis curves the other, creating the two vibration modes. Three frequency labels with arrows pointing to different zones of the field: 'Fundamental (f₁) — strike zone' pointing to the area between dimple and edge, 'Octave (2×f₁) — long axis mode' with a dashed vibration mode line along the major axis, 'Compound 5th (3×f₁) — short axis mode' with a dashed line along the minor axis. The dimple at center labeled 'Dimple — stabilizes vibration, reduces metallic ring'. The boundary between tone field and interstitial area shown as a subtle ridge labeled 'Isolation boundary — prevents crosstalk to adjacent fields'. Surrounding flat steel labeled 'Interstitial (untuned)'. Dimension callouts: field width 3.500 in, field height 4.550 in, dimple depth 0.300 in, steel thickness 0.039 in. Title block: 'HANDPAN TONE FIELD — Vibration Mode Anatomy / Scale 2:1'. Drawing number: HAN-001-D.
DRAWING 5: THREE INSTRUMENTS — Comparison Lineup
Prompt | Technical blueprint drawing, white lines on dark navy blue background. Three instruments shown side by side in front elevation (cross-section) view, drawn to the same scale for size comparison. LEFT: Steel Tongue Drum — 12 inch diameter lenticular shell, 6 inches tall, with tongue slits visible on the top profile and a 2.5-inch port on bottom. Labeled 'Steel Tongue Drum / Ø12 × H6 / 2mm Carbon Steel / 11 tongues / $130-335'. CENTER: Handpan — 21 inch diameter, 9.5 inches tall, much larger than the tongue drum. Tone field contours visible on top shell as gentle depressions, Ding dome raised at center, Gu port on bottom. Labeled 'Handpan / Ø21 × H9.5 / 1mm Nitrided Steel / 9 fields × 3 partials / $395-935'. RIGHT: Wood Shell Tongue Drum — 12 inch diameter, 5 inches tall, with flat soundboard on top (tongue slits visible) mated to a segmented wood bowl below. The wood cross-hatch pattern differentiates it from the steel instruments. Labeled 'Wood Shell Tongue Drum / Ø12 × H5 / Padauk + Walnut / 11 tongues / $200-400'. A horizontal dimension line spans all three showing the scale relationship. Below each, a small physics icon: cantilever beam symbol under the tongue drums, clamped plate symbol under the handpan, and Helmholtz resonator symbol under all three. Title block: 'INSTRUMENT COMPARISON — Steel Percussion Family / Tony Koop Workshop / Scale 1:4'. Drawing number: FAM-001.

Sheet: Index
Flutes-AI.xlsx — Instrument Design Workbook Index
52 sheets · Cross-references to Instrument Workshop Master v3.xlsx · Updated 2026-05-02
ORIGINAL SHEETS (Tony's Legacy Data)
# | Sheet Name | Type | Description | Master v3 Catalog ID
1 | CNC Flute Dimensions | Design | Pentatonic Minor hole layout B3-D5 (exploratory, never built) | LEG-DES-003
2 | Low to High Range | Design | NAF design table G3-D6, Pentatonic + Arabic scales, 32 keys | LEG-DES-004
3 | Pivot Table 2 | Analysis | Build data cross-tab
4 | Built | Log | 153 flute builds #001-153 with dimensions and outcomes | Production Log
5 | Price Calculator | Business | Pricing by key (D5=$75 to D4=$135) + modifiers
6 | Customers | Business | ~22 leads from events | Contacts
7 | Mode 1&4 Pent. | Design | Flute calculator for 26 keys G3-Ab5 | LEG-DES-005
8 | Wolfram Export | Data | 153-build CSV for Wolfram Cloud acoustic model validation
WORLD FLUTE DESIGN TABLES (Claude-Built)
9 | Irish Flute | Design | 6-hole diatonic, 25 keys D4-D6
10 | Shakuhachi | Design | 5-hole D minor pentatonic, 25 keys
11 | Tin Whistle | Design | 6-hole diatonic + fipple
12 | Fujara | Design | 3-hole overtone + blow pipe, D2-G3 | LEG-DES-001
13 | Tuning Reference | Reference | ET table A2-D7, K2 corrections, cent calculator
14 | Kena - Kenacho | Design | 7-hole diatonic Andean, G4-D6 (Kena) + D3-F#4 (Kenacho)
15 | Xiao Family | Design | 8-hole bei/nan/qin xiao, 3 bore variants, 27 keys
16 | Duduk Family | Design | 9-hole stopped pipe, 4 regional variants, 20 keys
17 | Moseno | Design | 6-hole diatonic + blow pipe + 4 tuning holes, 20 keys
18 | Andean Duct Flutes | Design | Pinkullo + Tarka (square exterior CNC), 20 keys
19 | Siku - Zampoña | Design | Pan flute, 13 pipes (7 arka + 6 ira), closed tube
20 | Didgeridoo | Design | Stopped pipe, 3 bore profiles (cyl/cone/bell), 24 keys D1-Db3 | LEG-DES-002
PERCUSSION DESIGN TABLES
21 | Tongue Drum | Design | Cantilever beam, 9 wood species, 3 drum sizes, DOE protocol | TNG-001/002/003
22 | Marimba | Design | Free-free beam, 49 bars C3-C7, arch CNC, resonators
23 | Xylophone | Design | Free-free beam (no arch), 44 bars F4-C8
24 | Resonant Box | Design | CAPSTONE: cantilever tongues + Helmholtz chambers, 5-instrument family
STRINGED INSTRUMENTS (BOM + Method)
25 | Electric Guitar Bodies | BOM+Method | 2 solid-body styles, 32-step CNC method
26 | Electric Violin | BOM+Method | CNC sculpted body, piezo electronics
27 | Floor Harp | Design+BOM | 34-string Mersenne-Taylor + 4-size comparison + 19-string lap harp
28 | Whamola Bass | BOM+Method | Single-string lever bass, P-bass pickup
29 | Ukulele | BOM+Method | Soprano/concert/tenor, Mersenne-Taylor string calc
30 | Acoustic Violin | BOM+Method | CNC top/back plates, hand-carved scroll
DRUMS (BOM + Method)
31 | Segmented Ashiko | Cut List+BOM | 29 rings x 16 seg = 464 pcs, diamond pattern, 4 woods | ASH-001+
32 | CNC Guitar Bodies | Reference | Jazz Bass + Les Paul '59 + '62 Strat blueprint dimensions
33 | Segmented Conga | Cut List+BOM | 34 rings x 20 seg = 680 pcs, barrel profile, 3 woods | CON-001
34 | Didgeridoo | Design+BOM | Stopped pipe, 3 profiles, 24 keys + agave/split-blank methods | LEG-DES-002
WORLD STRINGS (Claude-Built)
35 | Kora | Design+BOM | 21-string harp-lute, segmented/stave bowl, Mersenne-Taylor, bridge physics, electric option, 24-step build | KOR-001
36 | Ngoni | Design+BOM | 3 variants (Donso 6/Kamele 10/Kamele 14), segmented bowl, pentatonic D-F-G-A-C, 10-step build | NGO-001
37 | Stave Lute-Oud | Design+BOM | Oud (11-str, fretless) + Lute (8-course, fretted), steam-bent ribs, CNC mold, fret calculator, bendability ref | LUT-001
ORIGINAL DESIGNS (Claude + Tony)
38 | Duntong | Design+BOM | ORIGINAL — Cylindrical tongue drum, 4 end configs, 4 layouts, 3 construction methods, 8-note pentatonic, 2 sizes, 13-step build | DUN-001
PERCUSSION — STEEL (Claude-Built)
39 | Handpan | Design+BOM | Hang/Handpan: Helmholtz Gu, 8 scale library, 9-note tone field calc with harmonics, shell forming, 16-step build | HAN-001
40 | Steel Pan | Design+BOM | Tenor C4-F#6, 29 chromatic notes, 3 rings circle-of-fifths, note sizing, 14-step build from 55-gal drum | STP-001
46 | Glockenspiel | Design+BOM | 25-bar chromatic C5-C7, free-free beam, 5 metal K constants, CNC walnut frame, art fair pentatonic option | GLK-001
42 | Technical Drawings | Image Prompts | 5 Fender-blueprint-style prompts: Steel Tongue plan+section, Handpan plan+section, Wood Shell exploded, Tone Field anatomy, Family comparison | DRW-001
CERAMIC INSTRUMENTS (Claude-Built)
48 | Ocarina | Design+BOM | 12-hole Alto C Helmholtz vessel flute, hole sizing calculator, 7 size library, ceramic slip cast workflow, art fair $25-60 | OCR-001
49 | Ceramic Electric Violin | Design+BOM | 3D print→mold→slip cast porcelain body, wood neck, piezo, 4 body concepts, engineering constraints, $250-485 | CEV-001
50 | Udu Drum Family | Design+BOM | Dual Helmholtz ceramic pot drum, 4 sizes S/M/L/XL, 5 variants (Utar/Kim Kim/Claytone/Udongo/Water), slip cast workflow, $8-20/unit | UDU-001
52 | Ceramic Tongue Drum | Design+BOM | Cantilever beam in fired ceramic, 17-material acoustic comparison, inharmonic spectrum, Helmholtz coupling, Wolfram Cloud synth params | CTD-001
PIPED INSTRUMENTS (Claude-Built)
51 | Great Highland Bagpipe | Full Set Design | Chanter (conical, open-pipe, 9-note Mixolydian JI), 2 tenor + 1 bass drone (cylindrical, stopped-pipe), 4 reeds, bag, blowpipe, 5 stocks, $555-1170 | GHB-001

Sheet: CNC Flute Dimensions
 |  | Piano Key # | 39 | 40 | 41 | 42 | 43 | 44 | 45 | 46 | 47 | 48 | 49 | 50 | 51 | 52 | 53 | 54 | Notes
 | Variable Name | Fundamental/Base Note | B3 | C 4 | Db 4 | D 4 | Eb 4 | E 4 | F4 | Gb 4 | G 4 | Ab 4 | A 4 | Bb 4 | B 4 | C 5 | Db 5 | D 5
Pentatonic Minor Scale: 3-2-2-3-2 |  | Fundamental Frequency (Hertz) | 246.9 | 261.6 | 277.2 | 293.7 | 311.1 | 329.6 | 349.2 | 370.0 | 392.0 | 415.3 | 440.0 | 466.2 | 493.9 | 523.3 | 554.4 | 587.3
 |  | Hole 1 Note | D4 | Eb 4 | E4 | F4 | Gb4 | G4 | Ab4 | A4 | Bb4 | B4 | C5 | Db5 | D5 | Eb 5 | E5 | F5
 |  | Hole 1 Frequency | 293.7 | 311.1 | 329.6 | 349.2 | 370.0 | 392.0 | 415.3 | 440.0 | 466.2 | 493.9 | 523.3 | 554.4 | 587.3 | 622.3 | 659.3 | 698.5
 |  | Hole 2 Note | E4 | F4 | Gb4 | G4 | Ab4 | A4 | Bb4 | B4 | C5 | Db5 | D5 | Eb5 | E5 | F5 | Gb5 | G5
 |  | Hole 2 Frequency | 329.6 | 349.2 | 370.0 | 392.0 | 415.3 | 440.0 | 466.2 | 493.9 | 523.3 | 554.4 | 587.3 | 622.3 | 659.3 | 698.5 | 740.0 | 784.0
 |  | Hole 3 Note | Gb4 | G4 | Ab4 | A4 | Bb4 | B4 | C5 | Db5 | D5 | Eb5 | E5 | F5 | Gb 5 | G5 | Ab5 | A5
 |  | Hole 3 Frequency | 370.0 | 392.0 | 415.3 | 440.0 | 466.2 | 493.9 | 523.3 | 554.4 | 587.3 | 622.3 | 659.3 | 698.5 | 740.0 | 784.0 | 830.6 | 880.0
 |  | Hole 4 Note | G4 | Ab4 | A4 | Bb4 | B4 | C5 | Db5 | D5 | Eb5 | E5 | F5 | Gb5 | G5 | Ab5 | A5 | Bb5
 |  | Hole 4 Frequency | 392.0 | 415.3 | 440.0 | 466.2 | 493.9 | 523.3 | 554.4 | 587.3 | 622.3 | 659.3 | 698.5 | 740.0 | 784.0 | 830.6 | 880.0 | 932.3
 |  | Hole 5 Note | A4 | Bb 4 | B4 | C5 | Db5 | D5 | Eb5 | E5 | F5 | Gb5 | G5 | Ab5 | A5 | Bb 5 | B5 | C6
 |  | Hole 5 Frequency | 440.0 | 466.2 | 493.9 | 523.3 | 554.4 | 587.3 | 622.3 | 659.3 | 698.5 | 740.0 | 784.0 | 830.6 | 880.0 | 932.3 | 987.8 | 1046.5
 |  | Hole 6 Note | B4 | C5 | Db5 | D5 | Eb5 | E5 | F5 | Gb5 | G5 | Ab5 | A5 | Bb5 | B5 | C6 | Db5 | D6
 |  | Hole 6 Frequency | 493.9 | 523.3 | 554.4 | 587.3 | 622.3 | 659.3 | 698.5 | 740.0 | 784.0 | 830.6 | 880.0 | 932.3 | 987.8 | 1046.5 | 1108.7 | 1174.7
User Selected Inputs & Variables | A | Mouth Piece Length | 2.62 | 2.62 | 2.50 | 2.50 | 2.38 | 2.38 | 2.25 | 2.25 | 2.12 | 2.12 | 2.00 | 2.00 | 1.88 | 1.75 | 1.62 | 1.50 | Guide a
 | G | Mouth Piece Diameter | 5/16 | 5/16 | 5/16 | 5/16 | 9/32 | 9/32 | 9/32 | 9/32 | 9/32 | 9/32 | 1/4 | 1/4 | 1/4 | 1/4 | 1/4 | 1/4 | 3/8" is too big and less than 1/4" is too small
 | B | Short Chamber Length | 4.38 | 4.25 | 4.125 | 4.00 | 3.75 | 3.75 | 3.625 | 3.50 | 3.375 | 3.25 | 3.125 | 3.00 | 2.875 | 2.75 | 2.625 | 2.50 | Smallest is 2.5 inches, it may be nice to increase these lengths
 | C | Spacing Length | 1.00 | 1.00 | 1.00 | 0.875 | 0.875 | 0.875 | 0.875 | 0.750 | 0.75 | 0.75 | 0.75 | 0.75 | 0.75 | 0.75 | 0.75 | 0.75 | Test with CNC to see if smaller flutes could handle a .625" or .50" spacing
 | E | Extra Length (to fit depth of chuck jaws) | 1.50 | 1.50 | 1.50 | 1.50 | 1.50 | 1.50 | 1.50 | 1.50 | 1.50 | 1.50 | 1.50 | 1.50 | 1.50 | 1.50 | 1.50 | 1.50 | Double check the depth of jaws required for the coresponding flute diameter
 | F | Bore ID | 1.000 | 1.000 | 0.938 | 0.938 | 0.875 | 0.875 | 0.818 | 0.818 | 0.750 | 0.750 | 0.688 | 0.688 | 0.625 | 0.625 | 0.562 | 0.562 | Smallest flutes may want to increase bore ID.
 | T | Wall Thickness ~ Appx 1/3 of Bore ID | 0.225 | 0.225 | 0.225 | 0.225 | 0.225 | 0.225 | 0.200 | 0.200 | 0.200 | 0.200 | 0.188 | 0.188 | 0.188 | 0.188 | 0.188 | 0.188 | Test these numbers, see how durable the flutes feel. Change if they need more or less thickness, .30 is probably too thick and probably don't want to go thinner than 0.1875"
 | U | Flue Depth | 0.035 | 0.035 | 0.035 | 0.035 | 0.035 | 0.035 | 0.035 | 0.035 | 0.035 | 0.035 | 0.035 | 0.035 | 0.035 | 0.035 | 0.035 | 0.035 | Might want to test as low as .020" and as large as .050"
 | V | Flue Width ~ Appx 1/2 of Bore ID or less | 0.500 | 0.500 | 0.469 | 0.469 | 0.438 | 0.438 | 0.409 | 0.409 | 0.375 | 0.375 | 0.344 | 0.344 | 0.312 | 0.312 | 0.281 | 0.281 | Need to do some testing on flue width. 0.5" is probably too big
 | W | Sound Hole Length | 0.25 | 0.25 | 0.25 | 0.25 | 0.25 | 0.25 | 0.25 | 0.25 | 0.225 | 0.225 | 0.225 | 0.225 | 0.225 | 0.225 | 0.225 | 0.225 | Double check some of these numbers against good sounds flutes from inventory
 |  | Removed from Diameter by Turning | 0.300 | 0.300 | 0.362 | 0.362 | 0.175 | 0.175 | 0.282 | 0.282 | 0.350 | 0.350 | 0.188 | 0.188 | 0.250 | 0.250 | 0.313 | 0.313 | Check these numbers, it may be wasting wood to remove .35" and it may be removing too little to only remove .175"
 | N | Hole 1 Diameter | 0.425 | 0.425 | 0.400 | 0.400 | 0.375 | 0.375 | 0.350 | 0.350 | 0.325 | 0.325 | 0.300 | 0.300 | 0.275 | 0.275 | 0.250 | 0.250 | Start with every finger hole at 0.25", then make several of one key and tune them with hot iron rods, then take an average for those hole sizes. Try to keep finger hole sizes between .25" and .45"
 | O | Hole 2 Diameter | 0.425 | 0.425 | 0.400 | 0.400 | 0.375 | 0.375 | 0.350 | 0.350 | 0.325 | 0.325 | 0.300 | 0.300 | 0.275 | 0.275 | 0.250 | 0.250
 | P | Hole 3 Diameter | 0.425 | 0.425 | 0.400 | 0.400 | 0.375 | 0.375 | 0.350 | 0.350 | 0.325 | 0.325 | 0.300 | 0.300 | 0.275 | 0.275 | 0.250 | 0.250
 | Q | Hole 4 Diameter | 0.425 | 0.425 | 0.400 | 0.400 | 0.375 | 0.375 | 0.350 | 0.350 | 0.325 | 0.325 | 0.300 | 0.300 | 0.275 | 0.275 | 0.250 | 0.250
 | R | Hole 5 Diameter | 0.425 | 0.425 | 0.400 | 0.400 | 0.375 | 0.375 | 0.350 | 0.350 | 0.325 | 0.325 | 0.300 | 0.300 | 0.275 | 0.275 | 0.250 | 0.250
 | S | Hole 6 Diameter | 0.425 | 0.425 | 0.400 | 0.400 | 0.375 | 0.375 | 0.350 | 0.350 | 0.325 | 0.325 | 0.300 | 0.300 | 0.275 | 0.275 | 0.250 | 0.250
 |  | Hole 1 Distance from End | 7.200 | 6.600 | 6.014 | 5.764 | 5.526 | 4.845 | 4.638 | 4.441 | 3.894 | 3.723 | 3.560 | 3.232 | 3.088 | 2.951 | 2.821 | 2.318 | Starting points given from Flutopedia NAF Calculator. Make Prototypes and Adjust as neccesary. These numbers should actually measure distance from Sound Hole
 |  | Hole 2 Distance from End | 9.100 | 8.440 | 7.770 | 7.405 | 7.060 | 6.335 | 6.032 | 5.738 | 5.165 | 4.910 | 4.670 | 4.335 | 4.120 | 3.917 | 3.725 | 3.175
 |  | Hole 3 Distance from End | 10.900 | 10.284 | 9.527 | 9.046 | 8.589 | 7.821 | 7.418 | 7.038 | 6.439 | 6.102 | 5.784 | 5.436 | 5.151 | 4.882 | 4.628 | 4.033
 |  | Hole 4 Distance from End | 13.300 | 12.459 | 11.629 | 11.077 | 10.554 | 9.335 | 8.878 | 8.446 | 7.642 | 7.261 | 6.899 | 6.308 | 5.989 | 5.687 | 5.400 | 4.742
 |  | Hole 5 Distance from End | 14.200 | 13.885 | 12.940 | 12.302 | 11.698 | 10.480 | 9.950 | 9.450 | 8.620 | 8.175 | 7.753 | 7.150 | 6.780 | 6.425 | 6.090 | 5.430
 |  | Hole 6 Distance from End | 15.400 | 15.312 | 14.252 | 13.527 | 12.840 | 11.624 | 11.019 | 10.448 | 9.593 | 9.087 | 8.607 | 7.991 | 7.565 | 7.163 | 6.782 | 6.119
Calculated/Tabulated |  | Blank Length = A+B+C+D | 32.50 | 31.44 | 31.76 | 29.14 | 28.99 | 26.26 | 25.78 | 23.04 | 22.79 | 20.89 | 21.30 | 19.36 | 19.51 | 17.24 | 17.54 | 16.40
 |  | Blank Width = 2(2*K)+.125 | 3.625 | 3.625 | 3.625 | 3.625 | 3.125 | 3.125 | 3.124 | 3.124 | 3.125 | 3.125 | 2.625 | 2.625 | 2.625 | 2.625 | 2.626 | 2.626
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

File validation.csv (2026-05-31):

gate_id | family_split | artifact | claim | status | method | next_action | evidence
VAL-001 | ALL | family-spec.csv | Acoustic-law and provenance columns are explicit | ready_for_validator | Run installed acoustic-law validator | Keep warnings visible for unknown-required rows | family-spec.csv
VAL-002 | ALL | visual-output-register.csv | Visual authority boundaries are explicit | ready_for_validator | Run installed visual-authority validator | Do not mark photos or renders as fabrication authority | visual-output-register.csv
VAL-003 | NAF-6H | design-table/flute-dimensions-parametric.xlsx | Workbook rows can drive packet geometry | public_extract_added | Review design-table/public-naf-workbook-rows.csv against current measured tuning logs | Keep rows public_workbook_extract_unvalidated until a full tuning trace is logged | design-table/public-naf-workbook-rows.csv
VAL-004 | NAF-6H | built registry | Historical builds validate table behavior | comparison_added_private_fields_omitted | Review analysis/naf-workbook-measured-log-comparison.csv and collect current per-hole tuning logs | Keep owner price dates notes and recipient details out of public packet | analysis/naf-workbook-measured-log-comparison.csv
VAL-005 | NAF-6H | A4 species analysis | FEM study explains tone-color trend | analysis_only | Compare against FFT blow tests | Record measured spectra before L4 wording | analysis/wood-species-fem/
VAL-006 | PVC-TRAIN | proof flute row | PVC dimensions are known | measurement_required | Measure stock ID/wall and update family row | Do not port wooden table directly to PVC | sourcing.csv
VAL-007 | LEGACY-SW | archive CAD | Legacy SolidWorks can become V5 CAD | blocked | Recover selected model and export reviewed neutral geometry | Map model constants to design-table rows | legacy/archive-2018/native-style-flutes/
VAL-008 | EXPLORER | explorer.html | Explorer is present and conservative | ready_for_review | Open locally or serve via static server | Keep status as scaffold until measurement gates close | explorer.html
VAL-009 | NAF-6H | public workbook comparison | Public rows and sanitized comparison stay aligned | ready_for_validator | Run scripts/check_public_naf_comparison.py | Keep private workbook/build-log fields out and keep rows comparison-only | scripts/check_public_naf_comparison.py

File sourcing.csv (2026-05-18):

source_id | family_split | item | preferred_source | status | last_checked | notes
SRC-001 | NAF-6H | Hardwood blanks | existing shop or lumber supplier | unverified_current_supplier | TBD | Do not claim current price or availability from historical builds.
SRC-002 | NAF-6H | Western red cedar blank | existing shop or lumber supplier | unverified_current_supplier | TBD | FEM study treats cedar as warm/forgiving but current stock must be measured.
SRC-003 | NAF-6H | Black walnut blank | existing shop or lumber supplier | unverified_current_supplier | TBD | FEM study treats walnut as balanced; dimensions still come from workbook extraction.
SRC-004 | NAF-6H | Hard maple blank | existing shop or lumber supplier | unverified_current_supplier | TBD | FEM study treats maple as brighter/demanding; high failure risk needs validation.
SRC-005 | PVC-TRAIN | PVC pipe stock | local hardware supplier | needs_current_check | TBD | Measure actual ID rather than trusting nominal pipe size.
SRC-006 | ALL | Reference lineage | Blue Bear Flutes public videos | reference_only | TBD | Craft lineage acknowledged; not dimensional authority for this V5 packet.

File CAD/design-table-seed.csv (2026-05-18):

parameter_id | family_split | parameter | value | unit | status | source | notes
DT-001 | NAF-6H | target_fundamental | TBD | Hz | measurement_required | design-table/flute-dimensions-parametric.xlsx | Select key-specific row before release.
DT-002 | NAF-6H | bore_inner_diameter | TBD | mm | measurement_required | design-table/flute-dimensions-parametric.xlsx | A4 FEM row cites 15.2 mm but packet needs workbook extraction.
DT-003 | NAF-6H | wall_thickness | TBD | mm | measurement_required | design-table/flute-dimensions-parametric.xlsx | A4 FEM row cites 5.1 mm for analysis geometry.
DT-004 | NAF-6H | physical_chamber_length | TBD | mm | measurement_required | design-table/flute-dimensions-parametric.xlsx | Must distinguish effective and physical length.
DT-005 | NAF-6H | slow_air_chamber_length | TBD | mm | measurement_required | design-table/flute-dimensions-parametric.xlsx | Critical voicing parameter.
DT-006 | NAF-6H | true_sound_hole_width | TBD | mm | measurement_required | design-table/flute-dimensions-parametric.xlsx | Critical voicing parameter.
DT-007 | NAF-6H | flue_depth | TBD | mm | measurement_required | design-table/flute-dimensions-parametric.xlsx | README notes about 0.035 inches historical rule; extract exact row.
DT-008 | NAF-6H | flue_width | TBD | mm | measurement_required | design-table/flute-dimensions-parametric.xlsx | README notes about half-bore historical rule; extract exact row.
DT-009 | PVC-TRAIN | stock_inner_diameter | TBD | mm | measurement_required | physical_measurement | Measure actual pipe.
DT-010 | PVC-TRAIN | stock_wall_thickness | TBD | mm | measurement_required | physical_measurement | Measure actual pipe.

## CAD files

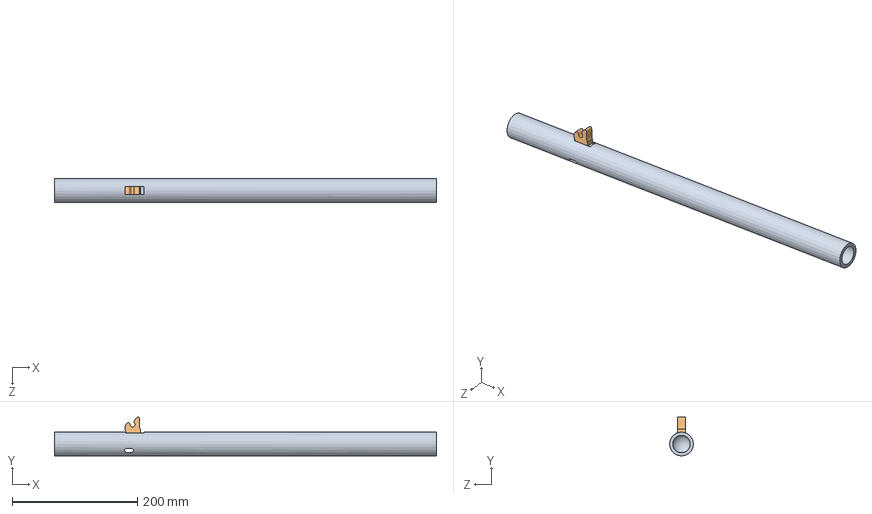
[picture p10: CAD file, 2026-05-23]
CAD/Native American Flutes/Epsilon.SLDASM
609.6 x 62.2 x 38.1 mm
Fetish
Native Flute Epsilon

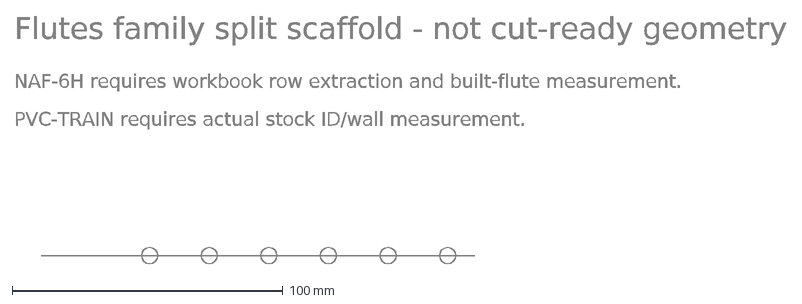
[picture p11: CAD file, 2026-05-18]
drawings/flutes-family-layout.dxf
Flutes family split scaffold - not cut-ready geometry
NAF-6H requires workbook row extraction and built-flute measurement.
PVC-TRAIN requires actual stock ID/wall measurement.

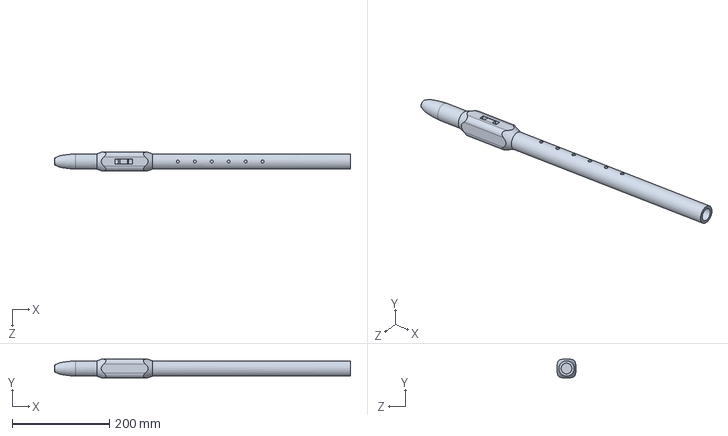
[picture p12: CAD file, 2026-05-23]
CAD/Native American Flutes/Native Flute Alpha.SLDPRT
609.6 x 38.1 x 38.1 mm

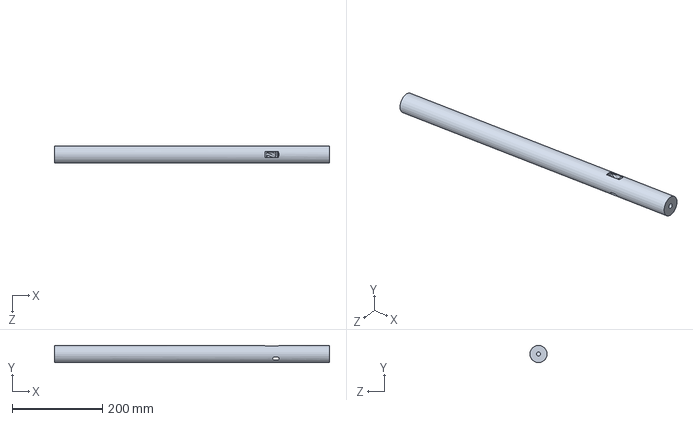
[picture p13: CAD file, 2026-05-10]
CAD/Native American Flutes/Native Flute Gamma2.SLDPRT
609.6 x 38.1 x 38.1 mm

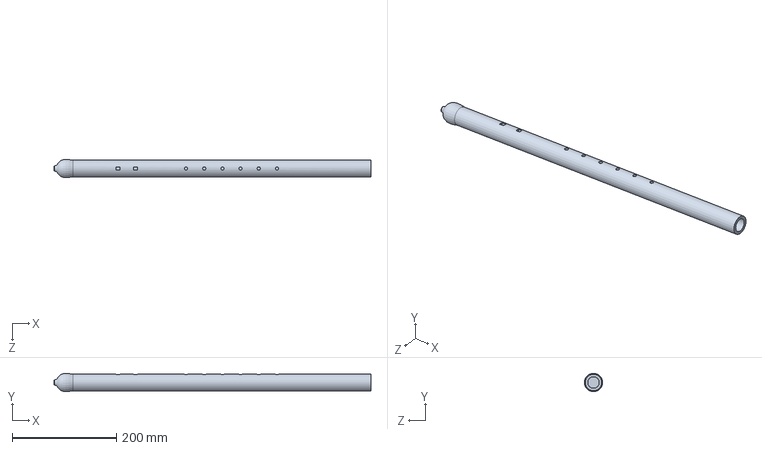
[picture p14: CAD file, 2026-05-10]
CAD/Native American Flutes/Native Flute beta.SLDPRT
609.6 x 35.1 x 35.1 mm

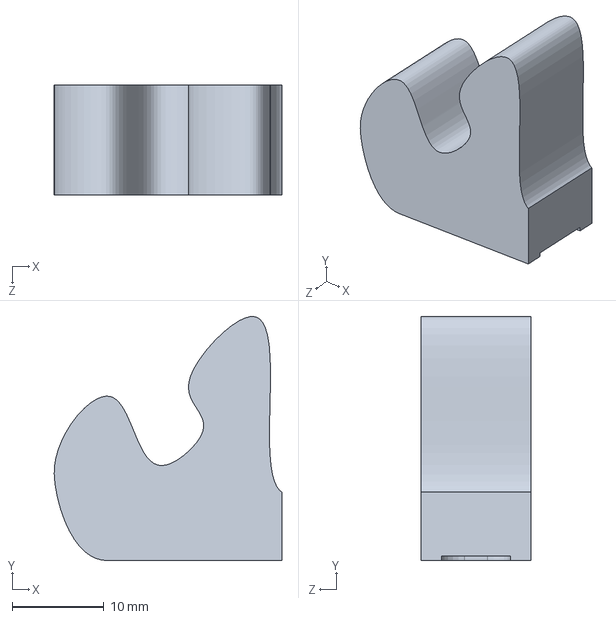
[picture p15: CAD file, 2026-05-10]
CAD/Native American Flutes/Fetish.SLDPRT
24.8 x 26.6 x 12.0 mm

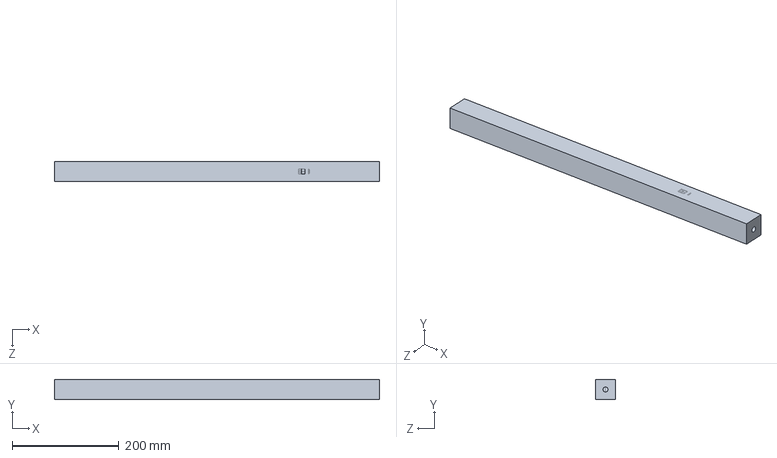
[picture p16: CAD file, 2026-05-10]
CAD/Native American Flutes/Native Flute Delta.SLDPRT
609.6 x 38.1 x 38.1 mm

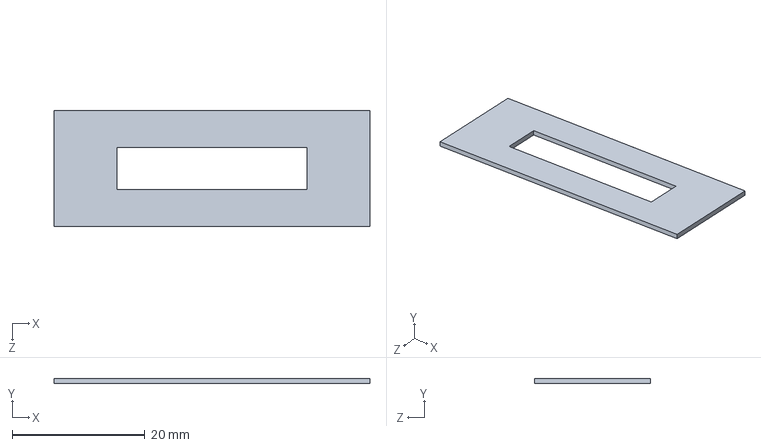
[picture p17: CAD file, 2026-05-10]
CAD/Native American Flutes/Native Flute Alpha - Overblow Float.SLDPRT
47.6 x 0.794 x 17.5 mm

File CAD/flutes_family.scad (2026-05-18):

// Flutes family scaffold for Round 31 issue #3.
// This is not a cut-ready flute model. Critical dimensions stay tied to
// cad/design-table-seed.csv and family-spec.csv until workbook rows and
// physical measurements are extracted.

$fn = 64;

show_family = "NAF-6H"; // NAF-6H, PVC-TRAIN, LEGACY-SW

naf_placeholder_length_mm = 390; // A4 analysis effective length reference only
naf_placeholder_bore_mm = 15.2;  // A4 FEM analysis row, not full packet authority
pvc_placeholder_length_mm = 390; // measurement_required
pvc_placeholder_bore_mm = 19.0;  // nominal placeholder, measure actual stock
body_wall_mm = 5.1;              // A4 FEM analysis row, measurement_required

module flute_body(length_mm, bore_mm, wall_mm) {
  difference() {
    cylinder(h = length_mm, d = bore_mm + 2 * wall_mm);
    translate([0, 0, -1])
      cylinder(h = length_mm + 2, d = bore_mm);
  }
}

module six_hole_markers(length_mm, bore_mm, wall_mm) {
  // Marker stations only. Real stations must come from workbook extraction.
  for (i = [1:6]) {
    translate([0, -(bore_mm / 2 + wall_mm + 1), length_mm * (0.28 + i * 0.075)])
      rotate([90, 0, 0])
        cylinder(h = 2, d = 4);
  }
}

module naf_scaffold() {
  color([0.55, 0.33, 0.18])
    flute_body(naf_placeholder_length_mm, naf_placeholder_bore_mm, body_wall_mm);
  color([0.1, 0.1, 0.1])
    six_hole_markers(naf_placeholder_length_mm, naf_placeholder_bore_mm, body_wall_mm);
}

module pvc_scaffold() {
  color([0.85, 0.85, 0.8])
    flute_body(pvc_placeholder_length_mm, pvc_placeholder_bore_mm, 2.5);
  color([0.1, 0.1, 0.1])
    six_hole_markers(pvc_placeholder_length_mm, pvc_placeholder_bore_mm, 2.5);
}

if (show_family == "PVC-TRAIN") {
  pvc_scaffold();
} else {
  naf_scaffold();
}

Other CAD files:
CAD/Native American Flutes/Native Flute Gamma.SLDPRT
CAD/Native American Flutes/Native Flute Epsilon.SLDPRT

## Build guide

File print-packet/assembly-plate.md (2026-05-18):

# Flutes Assembly Plate Placeholder

This is not the V5 PDF assembly plate. It records the required callout plan until a Photoshop or Illustrator MCP session produces `print-packet/assembly-plate.pdf`.

Required future callouts:

- Family split: `NAF-6H`, `PVC-TRAIN`, `LEGACY-SW`.
- Source row ID from `family-spec.csv`.
- Design-table parameter IDs from `CAD/design-table-seed.csv`.
- Measurement gate for bore ID, wall thickness, effective length, slow-air chamber, flue, true sound hole, and six finger-hole stations.
- Visual authority note: concept and photo assets do not control dimensions.

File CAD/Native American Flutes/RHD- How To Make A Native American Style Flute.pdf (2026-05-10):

### Fipple Designs - For Native American Flute

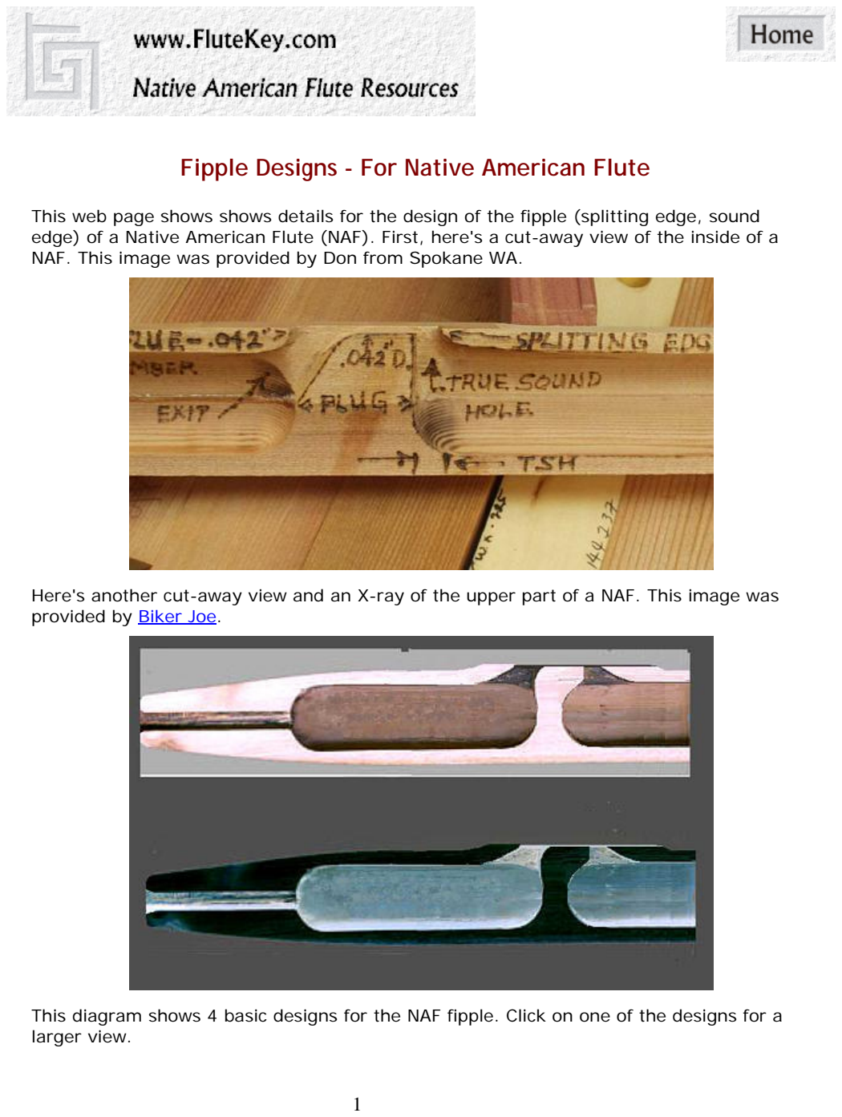
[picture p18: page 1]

This web page shows shows details for the design of the fipple (splitting edge, sound edge) of a Native American Flute (NAF). First, here's a cut-away view of the inside of a NAF. This image was provided by Don from Spokane WA.

Here's another cut-away view and an X-ray of the upper part of a NAF. This image was provided by Biker Joe.

This diagram shows 4 basic designs for the NAF fipple. Click on one of the designs for a larger view.

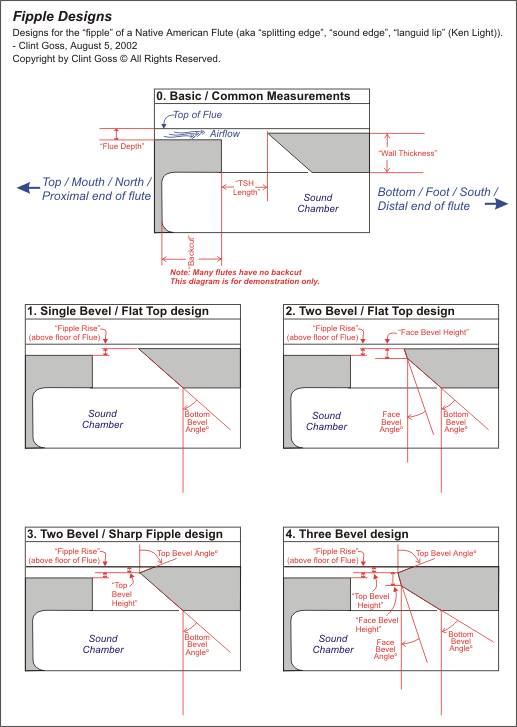
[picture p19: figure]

Notes:
1. The terms "Top", "North end", "Mouth end", and "Proximal" all mean the end of the flute you blow in. The terms "Bottom", "South end", "Foot", and "Distal" are all used for the other end.
2. "TSH" stands for "True Sound Hole".
3. The measurement "Flue Depth" in these diagrams is made at the location nearest the TSH. In many cases, the flue does not have a constant depth along it's length. The depth of many flues decreases as it nears the TSH.
4. Diagram 0. Basic / Common Measurements shows dimensions that are common to all the designs.
5. The shape of the flue can be achieved in a number of ways, which are not reflected in these diagrams. The flue can be:
- cut into the body of the flute,
- cut into the bird (also called "totem", "fetish", or "block"),
- formed with a spacer plate, or
- some combination of these designs.
6. If the top (proximal) edge of the TSH lines up with the top of the sound chamber, the "backcut" measurement is zero. Many flutes are constructed with no backcut.
7. The measurement "TSH Length" is always between the top (proximal edge) of the TSH and the face or edge at the bottom (distal end) of the TSH.
8. The Bottom Bevel Angle and Face Bevel Angle are smaller for angles that are more "vertical". They both increase as the amount of wood that is "undercut" increases. This is the reverse of the way that Russ A. Wolf measures these angles in his excellent reference Flute Shop: A guide to Crafting the Native American Style Flute.
9. Measurements of the height of the Top, Face, and Bottom bevels are always done perpendicular to the floor of the flute. They are not done in line with the bevel.

Web site by Clint Goss - Last updated February 5, 2005.

### 2005 Flute Class

Fundamental Varies as Diameter: Length of bore measured from splitting edge (TSH) to the end of flute: 18:1 i.e. 0.5” diameter bore X 18 = ¾” I.D. => key of G#, A, A# 9” bore length; 0.875 X 18 = 15.75” bore length, etc.

7/8” I.D. => Key of F, F#, G

1” I.D. => Key of D, D#, E

1 ½” I.D. => Key of A

Started with routered half blanks of curly maple.
- Sand bore smooth. Don’t sand rails. Cleanoff sawdust.

__________________________________________________________________
- | ___________________________________________________________________________________________________
North | True Sound hole | South

Mouth end of flute is north end. Finger holes are numbered from the south (being #1).

- seal bore with two coats of shellac.
- Smooth with fine Liberon steel wool.
- Mark location of rails on top of blank
- Mark location of front slot, 1/8” x ½” wide on top of blank starting above point where router bit stopped and channel flattens (bottom of ski slope). True sound hole
- Northern sound hole ¼-5/16” x ½’ , center on bore from true center, closest to mouth hole
- Sound holes are usually ½ of bore diameter.

Sharpen chisel on automotive grit wheel then finish with rouge on leather wheel. For sharpening tips see Scareysharp.com

-Use 1/8” end mill to cut slot, mounted on Dremel $29 or Proxon $39 router attachment.

Use cross slide vise to hold flute steady.
- Form underside cut ramp for true sound hole (cutting edge) with 12 mm chisel to a 32-45 degree angle . Should be about 1/16” thick leading edge. Wiggle chisel side to side, edge should be uniform thinckness and level .

On back slot, closest to mouth smooth with emory cloth.
Small machinists files, spring clamps, 12 mm chisel, knife edge chisel, 90 degree chisel And machinists file, and Roll of stick on grit paper.

Stick grit paper to top of saw table to flatten rails.

- Make a glue clean-up dowel by wrapping a clean 2” wide cloth around dowel.

Gluing
Find dead center of bore with center finding ruler, mark on top and closed end
Clean rails.
- Spread thin film of Tight Bond II extend
- Join halves, slide back and forth a couple times
- Check alignment north and south, and clamp with six spring clamps
- Use clean-up dowel to wipe up excess glue from inside diameter

Lathe

Drill 1/16 pilot hole at dead center in end of flute or use lathe tailstock center.

Put cone shaped metal or wood end center in open end of blank and mount on lathe with north end at lathe right or chuck end. Tighten end stock for moderate tightness having care in not using too much pressure which will crack the blank.

- Start with very sharp bowl gouge taking very little off at first. Test for trueness of Mounting.
- Mark off flue area and don’t round
- Cut to a wall thickness of 1/8” to 3/16” from open end in about 2” from north. Stop and protect cut end with three wraps of nylon tape. This should prevent cracking.
- The depth of this cut will act as a guide for rounding the rest of the shaft.
- Continue to round blank measuring O.D. with calipers, especially at area of future finger holes.
- If shaft gets whippy be ready to support back of shaft at the middle of blank with open hand.

- Don’t lathe ‘bird nest’ area to 2” behind rear sound slot.
- Use skewer chisel to shape mouth piece.
- Sand shaft smooth.
- Remove from lathe.
- Drill out mouth hole to 3/8”.

Planning a Blank

Make a fixture to mount blank.
- A cone shaped support bolted to a wood ‘bookend’ clamped to bench for the open end.
- A similar ‘bookend’ with a metal 3/16” diameter pin clamped to bench at other end of blank.

Mark dead center of mouth piece. Drill a 3/8” hole into sac area.

Mark of birds nest area: 3/16 on each side for rail, 1” ahead of top slot, and 2” behind bottom slot.
Mark off faces of sides by thirds (1/2” wide strips for a 1 ½” blank).
Mark off open end for a 3/16 “ thick tube wall.
-Use block plane of spoke shave to cut down corners evenly.
- Round off with plane shave and sandpaper.
- Taper and shape mouth piece.

Router

Router birds nest flue 32/1000” deep with an end mill. This is the area between the slots. Router exit flue or air runout (area below/south of the true sound hole) to a 12/1000”-14/1000” depth.

Tuning

If you want an E flute and the chromatic tuner indicates the flute is low you can tune to an E by shortening it 1/8 inch at a time. Either cut off a small piece at the bottom or drill a hole in the side. You want to be a bit high (above) an E before you drill the finger holes.

The following applies to flutes one inch bore (inch inside diameter) and smaller.

Mark the centerline of the very top of the flute. Measure from the lower edge of the true sound hole to the bottom end of the flute. Make a mark one half of this distance on top of the flute.
- For larger sound holes drill the third hole ½ to ¾ inch south of the half way mark.start
- For smaller hands drop ½ inch below the half way mark drill smaller holes.
- Space holes 1 1/8 inches apart. Mark for six equally spaced holes.

- Drill six holes at 3/16 inch dia.
- Clean the bore using a dowel rod with stickey sand paper wrapped around it.

Seal sac hole with three coats of shellac. Clean up with denatured alcohol if necessary.

### The following tuning is for an E (fundamental) flute

For a flute in the key of E the six sound hole notes are;

TSH | E | D | C | B | A | G
Notes-→ | E | D | C | B | A | G
__________________________________________________________________
- | ___________________________________________________________________________________________________
North | True Sound hole | South

Clean up the six drilled holes from the top and underneath. Remove all bore boogers and hanging chads.

__________________________________________________________________
- | ___________________________________________________________________________________________________

Cover all holes except the bottom hole, #1 open;

- Note should be a G (-30 on chromatic tuner scale)
- If tone is below G -30, ream out or open sixth hole a bit
- As an alternative you can under cut the hole from the mouth piece side

__________________________________________________________________
- | ___________________________________________________________________________________________________

Cover all holes but the last two, #1 &2 open;

- Note should be an A, -30, if lower open up 2nd hole

__________________________________________________________________
- | ___________________________________________________________________________________________________

Cover all holes but the last three #1,2 &3 open;

- Note should be B,-30, but if A# open up 3rd hole with reamer.

__________________________________________________________________
- | ___________________________________________________________________________________________________

Cover up top two holes and 3rd hole to tune fourth hole.

- Should be a C, -30 is O.K., if lower open up 4th hole

For top two holes be very careful and open up in smaller increments.

__________________________________________________________________
- | ___________________________________________________________________________________________________

Cover up sixth and fourth holes to tune fifth hole.

- Should be D.

__________________________________________________________________
- | ___________________________________________________________________________________________________

Cover the fourth hole to tune the sixth.

- Should be tuned to E.

Now go back and check the tuning of the lower holes. Flute should be an E when all holes are covered.

If the tone goes over the desired note the hole is too big and should be plugged and redrilled.

If flute sound is weak or screechy not on key, at first measure and round/smooth sac hole slot and add a slight 45 degree angle to bottom front edge of bird.

Finish flute with three coats of shellac.
Dry and buff with fine steel wool.
Add one coat of paraffin oil, let dry.
Buff with crushed pummis.
Final buff with rotten rock powder.

www.flutopedia.com
www.flutekey.com
www.nativewoodworking.com
www.nativeamerican flute woodworking.com
www.cherrycows.com Keith Stanford – Flute Making Manual & Shop Booklet www.oregonflutestore.com Bill Hughes Flute Making DVD, Vol. 1 & 2

Fundamental Note

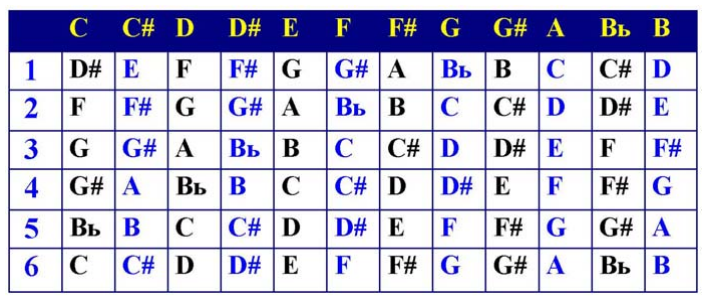
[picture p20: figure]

Finger
Holes

### For more information:

Richard Hodgin,

### friendshipflutes@msn.com

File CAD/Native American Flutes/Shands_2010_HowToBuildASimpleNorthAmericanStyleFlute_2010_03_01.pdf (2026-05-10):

It often comes a time in a persons life when they hear music with a beautiful and pleasing sound and wish they were capable of reproducing that sound on their own and to make their own expression of music. For those totally without knowledge of music and the ability to play any musical instrument, it will most likely appear to be a daunting wall of learning to have to scale.

While flute music has been in the world since the earliest of times, the music produced by the North American Style flute was not well known until late into the 20th century. With the advent of advanced electronics and recording capabilities, along with the sudden surge of New Age Music, the NAS Flute was a natural to be included in the cadre of instruments with soothing sounds and meditative potential. Many of the indigenous Native Americans with the musical knowledge of the flute passed on to them from their elders, became great leaders in the movement and reawakening of the joys of the flute.

Unlike the fipple flutes, and embrasure blown flutes, the North American Style flute is tuned to the Pentonic scale and not the Diatonic scale. Being Pentonic scale, the usual 5 notes being played will sound pleasing, and not discordant.
The flute is also constructed with a mechanism that produces the sound without a great deal of effort by a player. Much can be written about the history and the uniqueness of the North American Style flute, and that is saved for future writings.

Usually the first thing that comes to mind when a person wants to learn more about the NAS Flute, is they will inquire as to a source on where to purchase one.
A music shop will probably try to get them to go ahead and purchase a Recorder flute, which would be a huge mistake.
Then, the person would go on the internet and search about. Not being properly informed, they just might purchase a cheap knock off of what appears to be good craftsmanship and get a cheap, mass produced flute. Most often the knockoff was made in a foreign country and if even near to be in tune it would be a miracle.
Trying to learn on an inferior flute is frustrating and very unproductive.
The other thing that happens is that the person is daunted by the price of a well made flute.
What is left is a determined person that wants a flute and thinks they can make one on their own.

# How to build A simple North American Style Flute

By: Donn Shands

INTRODUCTION & DISCLAIMERS

At that point, they have no clue that there are many more just like themselves that desire to own and play a flute. They have no idea that there is help available through internet forums and through Flute Circles in their local area.
Usually, the first thing they will do is search on line on how to make a flute, and usually wind up trying to construct a PVC flute. Usually the first attempts will be miserable failures due to lack of crafting skills and lack of the proper tools for crafting. That also leads to great frustration.
The more fortunate will be lucky and find help through a local flute circle and a member that can pass on the knowledge of crafting a playing flute. If a person has gone this far, and still determined to obtain a quality instrument, and still has the desire to learn to play, then they have passed the first mark on their flute journey.

The set of chapters that have been provided in PDF form on this Beginner NAF Flute Forum that follow this introduction are provided by myself and several dedicated makers and players of the North American Style flute.
Each of us have gone through the hardships of the first steps of our personal Flute Journey.

Much thought has gone into coming up with a simpler method to produce a playable flute that was, made of wood, did not require the use of the more dangerous power tools in a workshop, and when finished, taught the basic skills needed to build future, more advanced flutes.

The simplicity of the construction lends itself to actually pre-cutting all the pieces needed for assembly and being provided as a kit for individuals to assemble in work shop type classes under supervision of a qualified flute crafting instructor.

The design of the flute in the project we are providing is that of a North American Style flute. The design results in a square shaped flute with a square bore. The shape has no effect on the playability or the sound. The design is not something that can be patented, as the concept is in the public domain. There might be individuals that will try to take the concept of providing a kit to construct this type flute to make a buck and try to patent the kit idea as something of their own creation. I am all for any instructor, or dedicated teacher of flute making, to being creative in making their own kits for their personal workshops. I would believe the World of flute makers would frown on any one person trying to corner the market on an idea that will provide for so many, a simple, inexpensive, safer, approach to making and playing their first flute.

Page 2

Disclaimers

I am not presenting this How To Manual as “The” only way to construct a flute. It is merely a simple means to an end that will provide a playable instrument with some of the pitfalls and more dangerous aspects removed that are found in advanced power tool filled wood workshops. It basically avoids the use of PVC, which is a possible source of toxic dust. Every attempt is made to explain possible shop dangers, and how to avoid them. Myself, and all those associated with the How To Manual, will not be held liable for any injuries, accidents, or medical problems that may result from any attempt to construct any portion of the project described.

At no time is the project to be construed as an official project sanctioned by an indigenous North American full or partial blooded native Indian. All caution has been taken as to call the flute being produced as a North American Style flute and not “Native American Style” flute.
All caution has been made to show respect to the history and the culture of the peoples of the lands of the Americas where the designs of the flute evolved over centuries of time to what it is today.

My name is Donn Shands, I am of Scottish/Welch/English decent. I claim no other blood lines. At no time do I represent myself as a blood line member of the American Indians.

Knowing there will be questions to be answered, I am providing a source of contact below for as long as the links hold up.

Donn Shands
Sugar Land, TX
tejasmed@chili-usa.com

Page 3

Chapter One The basic items needed to have in your beginner flute workshop.

Oh, the first thing you noticed was that the flute was square. Right, and it just so happens that it plays in tune and is a High D. Some people still believe that bumble bees can’t fly and still can’t understand how 747s stay in the air, and all steel ships float. Well, as long as the length of the walls are straight and the bore is consistent for the length of the flute, physics allow the flute to work as well as any round bore flute.

So, why a square bore flute? Because it is probably the easiest flute to make out of wood without using a workshop full of tools. Most beginners of flute making will try to construct a North American style flute out of PVC for their first flute. Many a beginner has started his flute journey with PVC. Problem is, most of the beginner makers have no clue about the potential dangers of working with PVC. The finished flute will not kill you, but what is produced during the process of making the flute is what gets you.
PVC saw dust and sanding powder can get into the lungs. Like black pepper that never dissolves in your stomach and sticks to the lining, PVC dust gets into the lungs and does not dissolve. It stays there, and sometimes the chemical make up of the plastic can create a form of lung cancer. If you must use PVC, then take the precautions of using a filter mask and other measures to cut out any breathing of the byproducts of flute making.

For a better idea, use wood to make the new flute.
Don’t have a router? No problem.
Don’t have a lathe? No problem.

You will need some simple tools, and we will discuss each of them and some suggestions as to how to obtain some that may not be readily available at the hardware store.

# How to build A simple North American Style Flute

By: Donn Shands

You are probably wondering why I am going to all the trouble to walk you through the tools and where to find them. First, you will need them to complete the project. Second, these tools will be part of your starter workshop for crafting future North American Type flutes. Sometimes it seems a bit costly to do a start up for such a simple project, but you need what you need to do the job. If you don’t want to make the investment in the future of a great hobby, and still want to play a flute, then just purchase a nice NAF from a reputable dealer. There are plenty to choose from, and they want the support. Pg 1

Wood.
Lowes and Home Depot have a couple of bins of specialized wood back in the lumber department.
There will be a bin of wood dowels, both round and square. Pick up a length of ½ inch square dowel. And for later use, buy a round dowel. Maybe ¼ in diameter, but smaller than ½ in diameter.
For the dowels try to obtain poplar if you can. Avoid oak if at all possible.

In another area, will be a bin of cut slats of finished smooth cut wood.
Usually the bin will be of poplar wood. Some stores have white and red oak, and finished cut pine usually called craft wood, and some even have white aspen wood.
For your first project, it is better to stay with the poplar wood.
You might as well pick up about 4 pieces of 4 ft long poplar. The slats are finished smooth, and are about ¼ in thick and about 1 ½ inches wide. The label will say ¼ X 2 X
4. The finished wood cut comes out to be 1 ½ inches wide.
Find the slats that have no cracks in the length, have no holes. The color of poplar ranges from off set white, to a greenish tinge, to almost black. Some slats will have some interesting patterns of all the colors mentioned. The more varied the colors of the grains, the more interesting the flute will be. The stains you might add later can enhance some of the patterns, or you can finish with a clear coat. For now, the main thing is getting a nice piece of tight grain wood to work with.

Glue
Most makers of North American style flutes have settled on using the White Gorilla Wood Working Glue, the type that does not foam up. Tight Bond III glue is another option. These glues will perform very well for wood projects. Usually, during glue up, the clean up is just water. They do not give off offensive fumes, and when dry, can be sanded smooth. Within reason, they are water resistant after curing.

#2 Pencil….sharp

Ruler ….usually a nice metal one that is 18 inches.
Ruler square…..does not have to be a real expensive one. But fairly accurate.

Clamps. For this project, it is better to use spring clamps. You can use C type clamps if necessary. Clamps that have rough faces will require some sort of cushion on their face to prevent marring of the wood surface.
This is a square flute being made, so it is not recommended to use rubber bands, Bicycle inner tube strips or bungie cords, or surgical tubing as a wrap clamp. The pressure will warp the sides of the project. The wrap type clamps are used on future projects when you learn how to make branch type flutes.

Small files. Diamond file sets are a good investment and will be a mainstay in your work shop.

The parts and tools suggested to be available are as follows:

Sand paper. For practical purposes, you could get by with a sheet of 80 grit and a sheet of 120 grit. The black water proof paper is more durable.
Small Exacto type knife set. You could get by with just one handle and a #11 blade. But it is better to make the investment as you go on a whole set.

Knife…..carving type. While the Exacto knife is the norm for most craft workers, the blades are usually too thin and brittle to use safely on certain carving projects.
The thick and stiffer blade on a good whittling knife is recommended, one that has a sturdy blade that ends in a point.

Rasp…..wood type. Most wood rasps are pure overkill on wood projects.
If you can obtain one, the small fine Microplane rasp is the best tool for the project. Do not get the Stanley rasp…it is overkill.

Chisel You will need a ¼ inch wide flat blade chisel. See later notes on the chisel.

Saw. Well, we can get really basic here. If you have absolutely no power saws, then you could get by with a simple hand coping saw. Buy some extra blades for backup. You could use an electric scroll saw. You could use an electric saber hand saw. You could use a band saw. For short cut offs, you can use a fine hack saw blade. I say no to any table saws for this project.

Further, there is no need to endanger yourself with trying to use an electric planner, or router for any reason in this project.

Sander. While I personally use a bench 4 inch wide table top belt sander, with a 6 in flat disk sander, and also an up-right oscillating drum sander, you could get by with only the rasp and the sand paper.

Safety equipment Eye protection…glasses. Leather apron. Leather gloves. Eventually you will need a dust mask, and possibly Nitryl gloves.

Burning rods to make the finger holes. We will discuss that at a later time in the project. Burning rods make cleaner holes than drill bits and over all give you less problems during and after construction of a wooden flute.
You may already have a bottle of propane along with a propane torch head in your tool collection.

Electric drill. Usually a common 3/8 in chuck electric drill will do. Personally, I have a table top drill press with a small drill press vice on the table plate.

Drill bits. Brad points are nice, and a good set of Forester bits are great to have. A few really fine drill bits should be obtained, you will need them in the project.

Dremel set. Best investment you will ever make. ½ inch sander drums with 120 grit are essential.

A bench vice. Usually every shop has one. I added some thick leather glued to the vice faces to help keep from marring the surface of the wood project being held.
No place for a vice? We are going to have to use something to hold the wood steady while cutting. If you have to, find two pieces of long 1 by 2 smooth straight boards, and clamp your piece of ¼” wood between them. Use your C clamps or even a couple of Vice grips if you have them.
When you get down to it…..this flute can be made without one power tool if necessary, and with the lowest common denominator of hand tools at your reach to use.

Now, before we get into the project, lets discuss where some of the sources are where you can obtain the mentioned tools and material you will need.

Wood Lowes and Home Depot. This is your first project, don’t attempt it with expensive exotic woods.

Glue Lowes and Home Depot. Maybe Walmart. The other local hardware stores and specialty shops will zing you for another 20 % mark up.

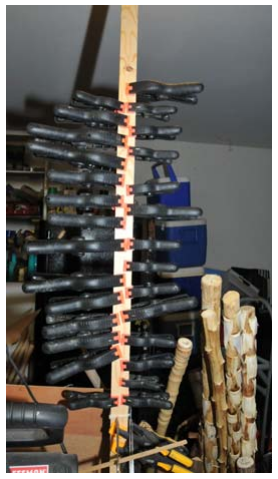
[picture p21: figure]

Pencil, Metal ruler, Square…. Small desk calculator
Nine out of ten of those reading this have a local Dollar Store.
While you are there, pick up a pack of the water sand
paper in an assorted pack for just a buck.

Clamps You can never have enough of them.
Over a few years, I have collected quite a few of the plastic spring clamps of different sizes. Probably for project, the 2 ½ inch jaw clamp is the best size. These clamps are available from Harbor Freight and Poppa Johns Tool box.
http://www.pjtool.com/springclamps.aspx
I think the 2 ½ in jaw is his 6 ½ long clamp
Get a box of 15 for less than 30 bucks at 2010 prices.

These clamps have a nice articulating plastic face too, that does not mar the wood surface. Try to avoid those metal flat spring clamps. They exert too much pressure on a smaller area of contact.

While you could get by with

your old Buck knife for
whittling, these custom
knives will be in your tool kit for life. Super strong carbon steel that keeps an edge. The top knife is the best to start with and give

You can almost start a war on the forum about which is the best cutting tools.
I was introduced by the Fallen Branch group to the Flexicut tool line.
Shown above is the flat blade, ¼ in chisel. The handle is called a power handle and can be used with a whole assortment of different blades. The blades easily pull out and replaced very securely in the handle. Later, when you learn to do gouging of flute bore blanks, you will purchase other blades with curved gouge tips to use in this handle. While most people are familiar with the common carpenters thick ¼ in chisel, this blade is thinner and is far easier to use for flute making purposes and will be a constant companion on your work bench. Make the investment, you will thank yourself hundreds of times over.

Exacto Knife

The more economical sets can be bought as off brand types at Harbor Freight.
You can find some Excel brand handles and blades at Hobby Lobby. Be careful, some brands of blades are a lot thinner than others and break easily.

Dremel When young, every kid’s dream was to own a Dremel kit.
It is an investment that keeps on giving. Just down the road, you might have to replace the electric brushes, and they are cheap at Lowes at the Dremel counter.
The best investment is the unit with the flex shaft.
Hang the unit over your work bench and attach it to a spring. Do not let the shaft hang down so that it will touch the floor. You might drop it and break or bend a tool in the chuck.
When you get established later down the road, go to the Master Carver site and investigate the Master Carver tool. Or check out the Fordom. Make sure you purchase a handle for those units that will take a ¼ in shank bit. But that is later.

Diamond Files
Probably the best place to find sets of diamond files is Widget Supply.
Their sets usually run less than 10 bucks.
http://www.widgetsupply.com/page/WS/CTGY/ht Search for files or type in diamond files in the search box.

Microplane rasp http://us.microplane.com/8snap-inrasps.aspxhttp://www.woodcarverssupply.com/FLEXCUT-ROUGHING-KNIFE-2-KN14/productinfo/993014/
Wood Carver Supply is a nice place to start unless you have a Woodworkers or Rockler’s in your neighborhood..

If you don’t want to buy a whole set of Microplane files, then just get the 8 in handle and the fine 8 in flat blade. Stay away from Stanley rasps…they are too rough.

Safety stuff.

Safety Pro
Protective gloves
Harbor Freight has a great assortment of work gloves.
Depending on your wallet, buy a good pair of comfortable gloves.
You can obtain a pair of Kevlar gloves, and there are gloves that protect against knife cuts. Most of my shop work, I find a good pair of flexible pig skin work gloves is the best protection and dexterity type. Stabbing yourself in the other hand with a knife or chisel can ruin your day. A sander will do a much faster job on bare skin than it will do good on the piece wood you are working on. Sanding damage can be like 2nd and 3rd degree burns…..not pleasant.

Which brings to mind the leather apron.

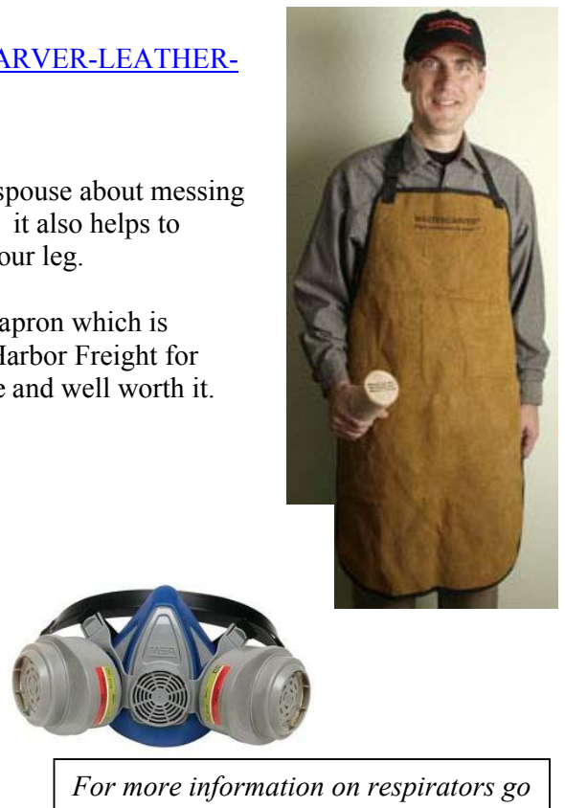
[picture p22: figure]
For more information on respirators go

http://www.woodcarverssupply.com/MASTERCARVER-LEATHER-APRON/productinfo/510009/

One day you will thank me for suggesting this.
It not only saves you a tongue lashing from your spouse about messing up your work pants with dust and glue and stains, it also helps to save you from slipping and poking a chisel into your leg.

If you can’t afford this apron, then a bit thicker apron which is
a welders leather apron can be purchased from Harbor Freight for half the price. This one is a lot more comfortable and well worth it.

A respirator mask to filter out dust is a
good investment. Check out all the respirators on Amazon. Com and find one to suit you. Purchase an extra set of filters at the same time you purchase the mask. At least with this mask you can wear your glasses.
Remember, in the future, you will be working with some woods that just might be real allergenic to you personally.
If you don’t believe me, blow your nose after a session in the shop after sanding. Or open up your shop vac and look at the filter.

Drill bits Browse Harbor Freight for economy drill bits. For your use, you will need a small set of foresters, and a set of brad point bits. Harbor Freight also has small blister packs of small fine drill bits. The finer drill bits will be a great help later on. The finer bits can be used in an adjustable chuck on your Dremel.

to Chapter 1a
Basic explanation of respirator use by Ellie Barbarash

This was an introductory chapter, mainly to get you off to the right start on this project, and to provide you with the basic necessary items to get you into the project.
As mentioned, you can really over spend and get distracted when shopping for workshop items. Having the basic items on the bench, BEFORE you start, will help to suppress the frustration of having to stop and go to the hardware store and pick up a missing item.

While a good ruler is essential, one of your best friends in the tool box is a good caliper. Not something you pick up at the dollar store, but for a reasonable price usually at Harbor Freight.
Note the one on the left is plastic. No frills, but effective in a pinch.
The two in the middle are composite. One measures inches, mm, and fractions, while the other measures inches and mm.
The third is metal and composite. When not on sale, it is usually in the 20 buck American range, but sometimes gets down to the 12 buck American when on sale.
It measures in inches and mm. It has the added feature of being able to thumb screw down and set a measurement temporarily. The metal, under thumb wheel makes precision setting of a measurement easy.
The thing to understand about the three electronic units is that they measure in decimals when looking at inches and mm. Later, when you are using the flute making programs like Flutomat, measurements are inserted into the program in decimals. These calipers save a lot of headache in trying to convert inches to decimals. When flute makers on the forums are exchanging data, they will
usually give each other required dimensions in
decimal inches.
Think of all the suggested items as the beginning basics of your flute making work shop.
As mentioned, you could make the flute in this project without using one power tool if you had to. But, there are some tools that with a bit of ingenuity, if you cannot buy them, you can come up with other solutions. However, I would not recommend the use of cruder tools to be used for cutting. The Flexicut chisel and knives should be the choice. Trying to use a cheap tool that will not hold up to pressure and use and not hold an edge will only frustrate you and provide shoddy workmanship.

Please go to Chapter 2

# How to build A simple North American Style Flute

By: Donn Shands

Chapter 1.a Some simple language about respirators. By: Ellie Barbarash

A respirator is better than a dust mask. It lets you breathe through a filter that protects your lungs and your nervous system from toxins in the air. A respirator is only as good as the way it fits on your face. If you have any facial hair, like big sideburns, a big mustache, or any kind of beard at all, a dust mask or a respirator is pretty ineffective, though it will keep the really big stuff out of your lungs at least. You can figure that for a poisonous gas or dust particle, the space between your beard hairs is a big open tunnel to get through to your mouth or nose, and some of the toxins will bypass the filter altogether and you'll just breathe them in through gaps in the facepiece seal. It's better than nothing, but when you're dealing with a chemical or a solvent that can slowly kill you, it's good to know you have all the protection you can get.

When you get a respirator, whether a disposable one or one of the silicone half faced ones, pay attention to the kind of filter you are purchasing. For sanding and cutting, you want a particulate filter. HEPA is best. If you're working with any solvents or finishes at all, you'll want one with an organic vapor filter. You can get a dual filter that has both. Comfort is important, and so is keeping the inside of your respirator clean, and storing it in a sealed Ziploc bag in between uses.

Chapter Two: Let’s get started with the project.

Lay out the first items you will need for the project.
Rulers, sharp pencil, the ½ in square dowel and the flat lengths of 1 ½ inch by ¼ inch thick poplar wood.

# How to build A simple North American Style Flute

By: Donn Shands

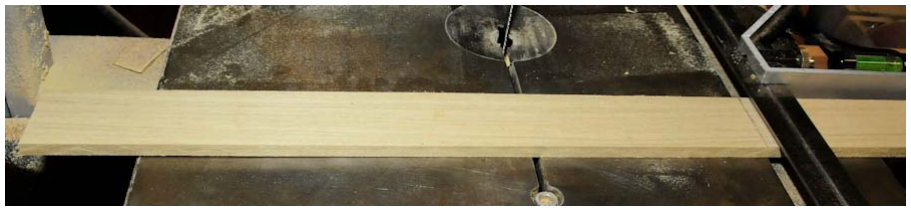
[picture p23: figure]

The first thing you do, is select a nice clear grained section of the slat and mark off 13 inches. Your band saw will probably not be able to cross cut this piece. Use the coping saw, or your table scroll saw, or in a pinch, use the shop vice, and carefully cut off the needed piece with a hack saw blade. If you have a miter box saw, that is the better answer.

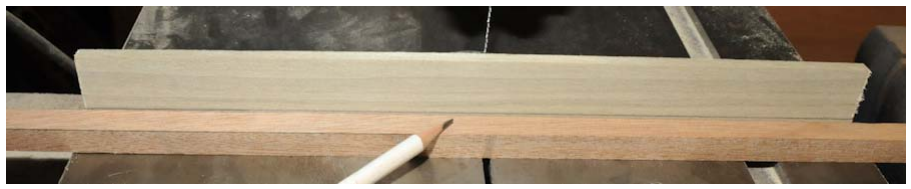
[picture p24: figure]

Now, find an absolutely flat, hard, smooth surface to work on. The band saw table top is about the most flat available. Turn the cut piece of slat on the edge and place it behind the dowel as shown in the picture Use the square dowel as a ruler and mark a line the full length of the wood slat set on edge. The purpose here is to obtain, after the next wood cut, a piece of the wood slat that is exactly the same width as the square dowel.

Cutting this long piece may present a problem to people that do not have a holding vice
for wood. It is simple on a band saw or a scroll saw. As mentioned before, you might
want to pinch this board between two other boards and clamp down with c clamps and extra pieces of thin wood to protect the work surface. That should hold the piece to be cut securely enough to cut with a coping saw.

Check the piece you just cut. It should have a smooth edge, and a rough edge. If you measure it to the square dowel, the entire length should be perfectly the same width as the square dowel. (oops….did you cut on the wrong side of the line? )
Take the cut piece and place it under the square dowel and place another piece of 13 inch cut slat behind the two and on edge. IMPORTANT….make sure the smooth edge of the slat is facing the bottom or on the table. Mark this with a pencil, then cut this piece to size.
Find another 13 inch piece of slat and repeat the cut, so now you have two sides for the flute.

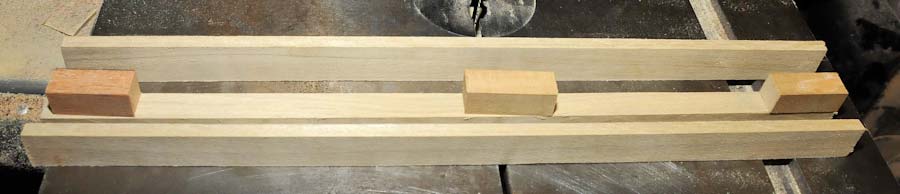
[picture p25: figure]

Use a saw and cut three or four short pieces of the square dowel. Make them about an inch and a half long. These are not a functional part of the flute, but provide accurate spacing while doing a glue up of the flute.

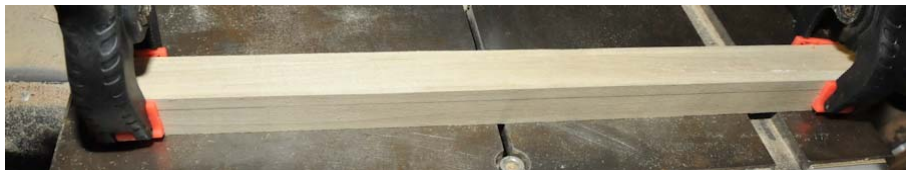
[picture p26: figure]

First step is to place the spacer blocks on the table.

Second step is to place the piece you have cut for the flute bottom, and put it on TOP of the spacer blocks. Remember, both of the edges should be as smooth as possible as this should be the exact width of the square dowel and when glued up, should show no open cracks along the seams.
Make sure that the two side pieces have the SMOOTH side facing down, the Rough edges facing UP.
This is the position you should be in when you have applied the glue in the next step. Failure to follow these instructions will give you problems with a proper seal of the top of the flute when that step comes.

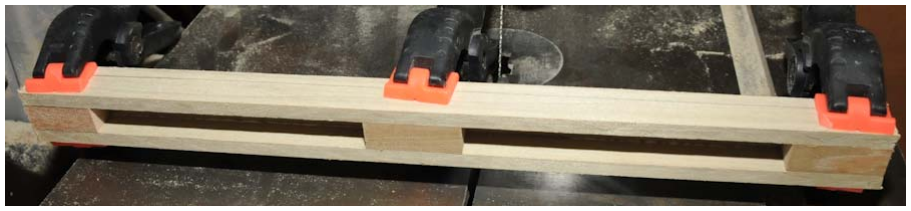
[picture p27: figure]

Now that you have things lined up, Have a paper towel, some water in a cup, and the white glue ready. Without any clamps on the project, and all in place, gently lift the part which will be the bottom of the flute, up and away from the other pieces on the table.
Put a bead of glue down each side of the edges of the wood that is to be the bottom of the flute. Use your finger and run it the length of each of the glue beads until the area is smooth. Run your finger down the sharp edges and remove any over flow excess. Clean up with paper towel and water. Gently place the bottom piece back in the groove on top of the spacer blocks, and press the two sides together to position it in place.
Apply pressure downward on this piece to make it rest evenly on the spacer blocks under it. Apply the clamps only on the part where the spacer blocks are located. Note in the picture above that the spacer blocks and the smooth edges of the sides are all flush.

For just the time
being, remove the
center clamp. Inspect
the position of the
bottom slat. More than
likely, you did not
make a precision cut
of the two sides,
usually, they will be
slightly wider than you
anticipated and they
leave a slight raised
edge on both sides of
the bottom slat.
Perfectly OK, as this
will be sanded smooth
later. But, the area
where the top playing
holes will go will have
even seams.

Note here, that when the
clamps are applied, that
some oozing of the glue is apparent. First check to
make sure all the cracks
have glue in them the length
of the seams, then wipe off
excess with wet towel.
Apply the center clamp. | Pg 3

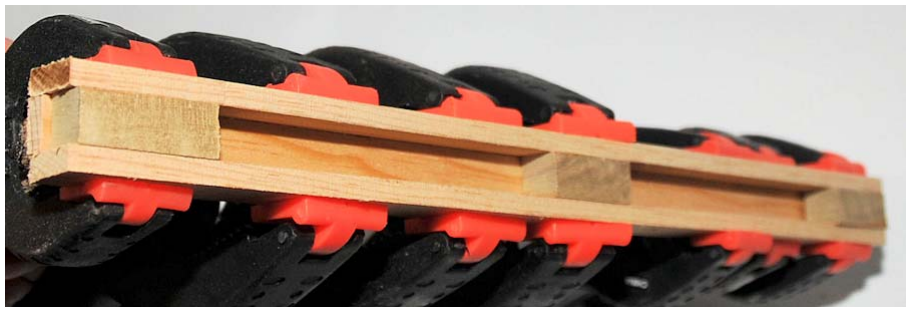
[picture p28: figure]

It is time to give this stage of the project time to set up. Usually that will be better if you left the project in a safe place out of direct sunlight, excess heat…or excess cold.

Proceed to Chapter 3

Shown here is a flute glued up with more clamps applied. You can apply more clamps, but you must use this type of flat surfaced plastic clamp. The main impact is actually pressing on the glue joint holding the bottom of the flute in place.
Absolutely do not use rubber bands, surgical tubing, or elastic bands to bind this flute. Remember, you are making a square flute. Pay attention to the physics of the project. Bands would warp the shape of the flute sides.

During the process of checking your glue up at this stage, it is a good idea to inspect the area where the spacer blocks are seated. You do not want a lot of excess glue to get on the spacers as they will be glued to the inner surface of the flute, and will result in a lot of extra work trying to remove them and all the clean up and smoothing later.

Chapter 3: Measurements and crafting the sound mechanism, first steps.

# How to build A simple North American Style Flute

By: Donn Shands

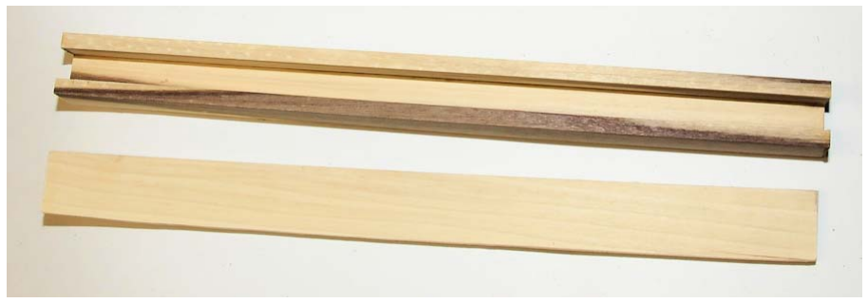
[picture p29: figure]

The picture above shows the bottom section of the flute glued up and the top piece measured and cut.
Not all of the pictures used in this presentation are of the same flute in a stage of being built.
This particular flute had some interesting grain in the wood. It sort of creates an optical illusion in the picture. Over 20 of these flutes were constructed during the documentation of the chapters.

This chapter takes up after the glue has dried on the assembly of the bottom three pieces of the flute.
The thing to do after removing the clamps, is to inspect the way the three pieces held together.
All sides should be evenly spaced into a perfect square U. As a safety precaution, place a glove on your holding hand and use the flat blade chisel to gently lift out the spacer blocks. Some might have had some glue holding them, but usually the glue is not totally over hardened yet and will come loose with out much coaxing. Inspect the seams both inside and out side the piece. If you see that glue is missing and cracks evident, then add some more glue to the area, and use a cotton tip swab and some water to spread into the cracks. Then clean up any excess with a dry cotton tip applicator or a piece of paper towel Try not to leave any excess in the flute interior which may cause bore perpetrations and cause problems in tuning.
You should have a fourth piece of the wood slat cut to the 13 inch length ready to use. Lay the piece to be used as the top down flat on the table with the surface you will want to be the final top to the flute. Place the bottom assembly down on the slat with the two edges down and use a sharp pencil to line off the length of the top. This will give you the exact width of what will be the top of your flute. Remember to cut on the outside of the line. After glue up and finish, you will have time to round off and sand the edges.

Over all length of finished flute. Approx 12 inches. The pieces you have cut to length are 13 inches for now. If you pay attention, you will have some extra length left over on the South End of the flute. You will need that extra when tuning. Some of it will be cut or sanded off to make the flute shorter distance from the rear of the TSH to the end of the flute. Cross that bridge when we come to it later. More than likely, the distance will finally be 9.25 in +/ -

.66 from back
of SAC escape
to cutting edge

From South end
Hole 1 2.54

Hole 2 3.19

Hole 3 3.90

Hole 4 4.61.55

Hole 5 5.33.80

Hole 6 5.95.20

Distance from South end to back of TSH 9.25 in

Missing a few numbers…like the size of the TSH? And the size of the holes? I hesitate to go ahead and give that to you, because I do not want you to just measure out and cut and drill stuff just because the diagram said so.
Something that new flute makers just refuse to learn on their first flutes, is that getting measurements off a blue print will not guarantee the end result will be a working flute. A flute is an experiment in physics and variables. No two flutes will turn out the same. No two flutes will sound exactly the same. Try as you may to be exacting, there will always be some little difference in the way you cut, sawed, sanded, chiseled, or finished every mm of your project.
A true craftsman of flutes will eventually learn from experience how to adjust each variable of a project so that the sum of all the parts of the flute work as they are expected to.
So many beginners rush to the end for completion, and produce a non working piece. They are angry, frustrated, and blame the blue print and measurements, but some where they missed an important and sometimes very crucial step.
What I have illustrated so far, is a way to get you safely to a point where you have a solid non air leaking bottom to your flute. The next steps will show you how to construct the portion of the flute that gives the character of the sound of the flute. Crafting the sound area is not something to go rough shod over. The more time and detail attention paid to this area, the better the possibility of getting a good sound out of your flute.

All holes are
measured to
the center of
each hole.

Now, that being said, keep the glued up bottom portion handy for measurements, and put the piece you will use for the top of the flute on the bench….with the outer face up.

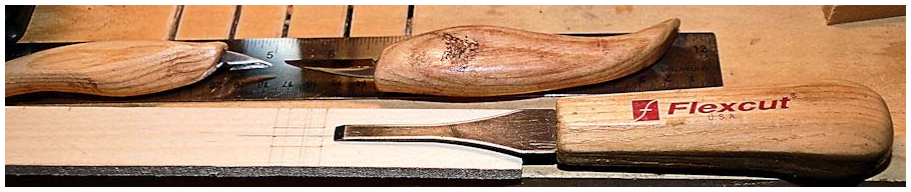
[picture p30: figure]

Get your calipers, calculator, sharp pencil, and 18 in ruler, and determine where the center of the slat used for the top will be measuring from side to side on the narrow side or across the top of the flute.
For now, take time to determine for sure, which side of the top you will use, and which end will fit the best as the top of the flute. One edge of the top piece should be smooth, It is best to make that smooth side meet up flush with the top of one of the edges of the bottom piece. Carefully observe that you do not have much if any hanging over the other side of the top of the flute. If you do, it will throw off the measurement of the sound area being directly in the center of the channel of the body of the flute. Part of your decision for deciding where the sound area will go, will be the configuration of the grain in that area. It is better to try to obtain an area where the wood has consistent straight grain. Some woods will have extra thick heavy wavy grains in some areas. It may cause you problems when carving some of the sharp surfaces needed for the crucial shapes of the TSH area. Look, and plan ahead. You should always consider the final location of parts of a flute in relationship with the grain patterns of the wood.

On this project, we will go contrary to regular measurements used, and take a measurement from the North end, or where the blowing end will be. Measure on the center line to the South 2.44 in. Make a small mark. That will be the back or the North End of the escape SAC hole. Measure 2.92 in and place a small mark. That will be the rear of the TSH. Use the calipers and measure 0.17 to the South of that line of the rear of the TSH.
Measure from the line of the TSH back to the North 0.23 in. Mark that as the beginning of the ramp back down into the escape hole of the SAC.

Future cutting edge,
do not cut out in any first DEEP cuts. You have to
sneak up on it later as you shape the TSH.

Rear of SAC
escape hole

This is delicate work, and sometimes wood and wood grain has a mind of its own. Plan ahead when you make cuts with a knife and a chisel. Pay attention to how the grain of the wood reacts to being cut by the tools.
The goal here is to maintain sharp clean edges that do not have fuzzies of wood splinters sticking up.
Use your chisel edge, or the point of your knife, and dent the wood at each corner insuring that it will cut clean to the square corners. When all corners are dented and cut, then carefully draw as straight a line as possible with the knife edge on all sides of the rectangle.

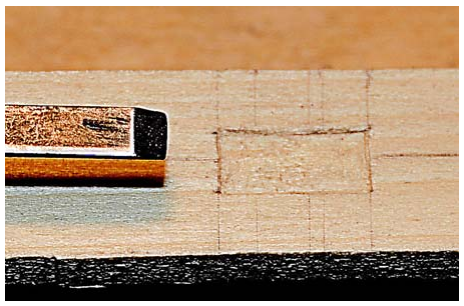
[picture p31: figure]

This next step is a bit tricky to do. Personally, if I were a first time maker, I would try this first on some of the scraps left over from the first cuts for practice.
You use the

¼ in flat chisel to start real slow at the point where you have cut into the grain with your knife. You do not go very deep… you give the chisel a slight push, then stop and go from the other end , then from each side. You are not digging a hole through the flute top yet. You are just defining the beginning depth of the sound hole area.

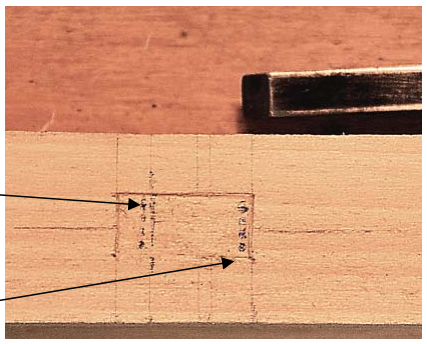
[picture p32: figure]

Use a sharp pencil and place a series of dots that will be where fine drill holes will go.
A series of small holes goes right to the South of the line designating the back of the TSH. Another set of holes goes just to the South of the line designating the back side or North side of the escape hole for the SAC.

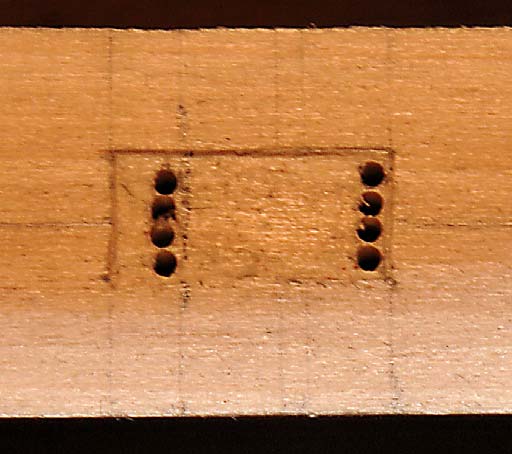
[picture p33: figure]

Remember that pack of small fine drill bits from Harbor Freight I suggested? Well, they come in handy about now. You do not want to be using huge 1/16 in drill bits for this part of the project.
These holes are very important as they mark both sides of the flute top for cutting locations. Make sure they are drilled straight through, perpendicular to the surface.

Just in case, turn the wood over and check the other side to see if all the holes are well defined and all the way through.

We will end this chapter at this point.
The next chapter will detail how the sound area is cut into shape.

Go to Chapter 4

Chapter 4: Crafting the Sound area….continued.

# How to build A simple North American Style Flute

By: Donn Shands

Take a second to reorient yourself to the task at hand. This first photo looks a bit crude, as it should be. (It will be refined later.) It is the top side of the flute sound area. To your right or the North End, you have made the first chisel cut at an angle down toward the bottom of the back wall of the SAC escape hole. Know where you are now?

Now turn the wood over to the underside of the sound area. Start from the bottom of North end and angle down toward the drilled holes. The purpose here is to eventually produce a gentle ramp up and out of the SAC.

Sometimes it helps matters along if the holes were drilled closer together, and you are able to place the flat side of the chisel to the back wall of the TSH and the back wall of the SAC escape hole. A clean cut through both holes saves a lot of later refinement work.
This is not a task where you put the chisel in the hole and just hammer the chisel through. You have to work this area a little bit at a time from each side. If you don’t, it will splinter the wood and ruin your project. Keep remembering how grains of wood react to the stress of knives and chisels as you work and apply pressure to each area.

The two photos above show you still working on the top side of the sound area. This area is highly critical as to how you shape the contour of the ramp down into the SAC. (A)
Notice the flat area on top (B) . This is where the flow of air from the SAC will travel across, go over the edge of the back of the TSH, and continue on to the splitting edge. (C) Which will be about where the arrow is pointing. Notice (D)….that is the rear wall, or North end of the TSH.

Turn the wood over and work on the bottom side of the sound area. Clean up and smooth the rear of the TSH (A) Clean up and smooth the ramp out of the SAC (B)
Keep working the chisel in the area (C) Try to keep the chisel canted so the angle will wind up around 30 degrees if possible. Too much or too little angle and it will make or break the way the flute even works, or sounds.

A

B

Turn the board over so it is face up again. You have been working on the ramp that slants down into the bore of the flute.
Some of the flute makers have called this the labium, or lip. The edge across from the TSH back wall is also sometimes called the splitting edge.
The picture to the right shows the knife getting ready to cut a very small part off this cutting edge. The sharp knife is a precise and quick way to do this. You can use a diamond file to take off the wood, but it is a bit of work. Work both sides of the wood, do not try to finish all on one side. This is part of learning what really is the relationship of the inside and outside of the flute.

On the right you are looking at the bottom side of a completed sound area. The areas are distinct and clean. Air has no fuzzies to catch on and cause ripples.

The photo on the right shows the top side of a sound area. Just about finished. Needs a little touch up here and there. The general rule of the width of a TSH is that it is usually ½ the dimension of the cross section of the bore of the flute. Measurements are made in inches expressed as decimals. The approx dimension of this flute is 0.50 times 0.62 = 1.12 divided by 2 = 0.56. Half of that is
0.28. You could go 0.29 or 0.30, but it is better to start with the lower number in case you need to straighten up the edges while final tuning. The gap, or distance between the rear wall of the TSH and the splitting edge. Or from North to South across the TSH…..should be about 0.17 at least to start.
Too much space in this area will create an “airy” flute. Too much; then you might find that tuning is impossible, …..sorry, you will have to rip the top off and start over on
a new piece.
A | B

A bit hard to see in the photo, but there is a slight slant on the top lip of the cutting edge. (A) This is added and is highly important as the actual splitting edge needs to be just slightly lowered so that it is in a place where the flow of air coming off the flue in a laminar sheet of molecules, will hit it directly on. The flat area
(B) is the actual flue of the sound area. Much controversy by flute craftsmen is raised about this area and dimension. Some want it longer, some want it no less than ¼ long in size, but all want the area to be at least as wide as the TSH. If you had a stony bed under a shallow stream of water, and the water flows across it, ripples will be caused in the water flow. If the same volume of water flows over a smooth surface, there will be little or no ripples on the surface and few if any deviant currents in the flow of water. All these areas where air flow is smooth and the path is direct as possible will not introduce pink or white noise into the notes of the flute.

The picture on the right might have you guessing at first. This is a simple way to see if the depth of the flue is adequate, is it deep enough? Is it in line with the splitting edge? Does the splitting edge need to be lowered or brought up?
Cut a piece of old credit card and place it in the flue. It should touch right to the splitting edge dead center.

1

2 | 3

Sorry for the photography on these three photos. Rather hard to get an in focus shot when you are looking down a long length of wood.
What you are looking at is what the TSH looks like at a steep angle from the North or blowing end of the top side of the flute. You are looking over the flue and at the cutting edge on the opposite side of the TSH. Note in (1) that the splitting edge is not straight across. And, the angle underneath is not sharp enough, so you see more wood in the angle. In photo (2), the splitting edge still needs work. Also the surface bed of the flue needs to be smoothed again so it is flat and even directly across the flue. On (3) it is just about right, on the left side under the splitting edge, it needs to be shaved off a bit to make it all straight and even. This interaction of all the crafting in this area can make or break the usability of a flute. Clean, neat, flue not too deep, flue deep enough to allow a good flow of air. Too deep of a flue, then the flute is airy. A flue that is too tight….or not deep enough, will cause too much back pressure. It will be difficult to play and be expressive.

For now, we will close this chapter.
The next chapter will show the steps needed before you glue the top on the flute.
Go to Chapter 5.

Chapter 5: Crafting the Sound area….continued. Adding the divider block and top glue-up.

# How to build A simple North American Style Flute

By: Donn Shands

The top of the flute is almost ready for glue up, but there is a very important part that still needs to be cut, fitted, and placed correctly inside of the flute chamber.

The first step is to measure and cut a piece of the ½ inch square dowel to make the divider block. First line is drawn square across the dowel. This line meets exactly to rear wall of TSH opening in top piece of flute. Draw the second line so that it continues and completes the arc of the ramp going out of the SAC and toward the flue.

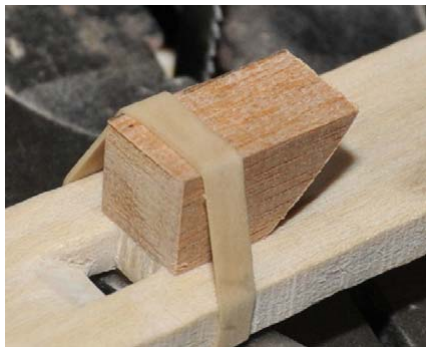
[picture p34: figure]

The picture above shows the shaped block in place. This is only for illustration to show the relative position of what the underside of the top and the divider block looks like when in place

This picture shows the divider block from the back side. As with the previous picture, this is only an illustration to show what the area should look like.

The step of inserting the sound block divider is a slight test of dexterity, and patience.
Before applying any glue, test the position of the sound area divider block. Seat the top making sure the North or blowing end is flush with the bottom U channel. Sight down directly into the TSH and use a flat file or a tool that will help move the block so it is even with the top hole so that the rear of the TSH is one flat continuous wall. The picture on the right shows the block needing to be moved back slightly. What might happen after moving, is the rear edge of the top of the ramp of the block going back down into the SAC will have moved back a bit. Sight down into the hole and use a sharp pencil and mark a line showing the excess. Remove the block and sand the excess off keeping the arc of the ramp. Replace the block

Looking down into the holes, the TSH rear wall is flush even, and the ramp is smooth and continuous.
If you have a problem with the rear ramp being one even smooth ramp without a gap, you can use a dab of Elmers Wood putty along the line where the top ramp meets the beginning of the ramp on the block. Wait to do this until you are finally ready to glue on the top. A wet cotton tip applicator can be inserted into the hole and the gap smoothed over .

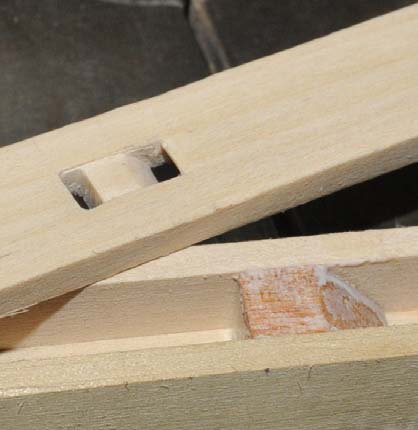
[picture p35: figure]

Remove only the top at this time
Put a pencil mark where the rear wall or face of the divider block should be. Remove the divider block and apply glue and reinsert to exactly the same spot. This is a good time to take a cotton tip applicator and add some extra glue around all the cracks of the block. While you are at it, check the rest of the open chamber to see if any cracks are left without glue in them. Use a couple of cotton tip applicators dipped in water to smooth the glue. Finally use a wet paper towel and remove any excess glue. All seams should be smooth and cracks sealed.

It is time to glue on the top of the flute.
Break off a couple sheets of paper towel. A bit of water in a cup. Have your clamps ready.

Remember all the trouble we spent to make sure that the top rails of the bottom of the flute were smooth and even? That trouble pays off now by providing smooth even seams during glue up.

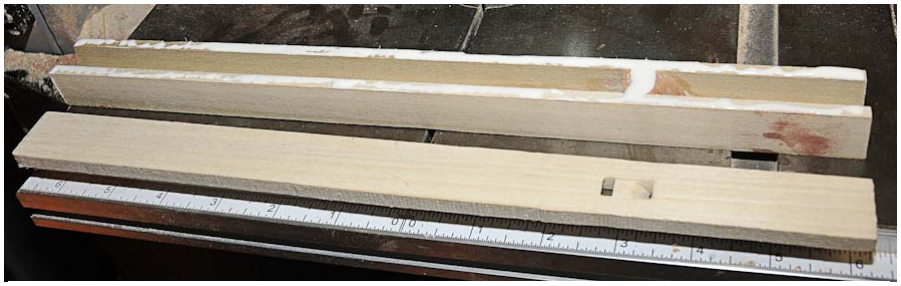
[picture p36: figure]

Please continue by going to Chapter 6 | Pg 3

Sight down the sound area holes and make sure the top is aligned again properly with the edges of the block. Use a wet cotton tip applicator and reach in the sound block area holes and make sure there is no excess glue, and the rear ramp is smooth. Secure the rear or North end of the flute with a clamp. I prefer the flat articulating face plastic clamps. To start with, use one clamp and clamp above and below. Go to the South end and do the same.
Now place a clamp in the center. Take time now to inspect the edges of the top of the flute where it meets the bottom of the flute. Add any glue if needed, wipe off excess with wet paper towel. Repeat the inspection on the second side. Use a small round dowel and a wet rag to swab any excess glue from the interior of the SAC and the main bore of the flute.
Where the end clamps are located, rotate them around so each is facing direct on to the ends of the flute. Move the clamp in the center slightly over to one edge, and apply another clamp directly opposite. Add more clamps opposite each other where space is available.
Allow the glue to set over night at least.

Apply a bead of glue down both of the edges of the bottom section of the flute. Note the gaps in the glue.

Use your finger tip to smooth down the beads of glue so there are no gaps along the edges. Add glue to the bridge across the top of the sound area block. (As noted earlier above, this is a good time to add that small gob of wood putty in the gap of the top and the sound area block where it goes down into the SAC. Remember to smooth as needed.) Wipe any excess glue on the edges inside the chamber of the flute. Carefully seat the top on the bottom part of the flute.

Chapter : 6 After the top is glued on, what is next?

To the new impatient craftsperson, they would hustle to get the clamps off the next day and find a small block of wood to make a makeshift totem or bird and try testing the flute. If they did so, they may or may not get a sound out of the flute.
Which of course is a bit of frustration.
Most of the time after pulling the clamps off, there are several reasons why the sound, if any, is noway near correct and the unfortunate result comes from several factors. Usually, just grabbing a block of wood to use as a totem will not be what is needed in size and edge surface at the TSH. The flute itself may be longer or shorter in the bore than the proper match for the size and construction of the TSH. Then there is the possibility that there are air leaks in the seams of the flute, or through pin holes or knots in the wood.
The first thing to do is to test the flute for air leaks.
Put a finger over the TSH to seal and blow in the South end of the bore. It should be air tight.
Turn the flute around and put a finger solid down on the SAC escape hole and blow in the North or blowing end. That area should be air tight. If not, then track down and seal the leaks.

It is better at this time to construct a simple bird or totem to use with the flute being crafted. Eventually, you will learn how to make many different totems to match different flutes. Totems are made in many different configurations. You will eventually learn a good rule of thumb that for every flute, a totem that is specifically matched to that flute is the best insurance of the flute playing properly. Just grabbing another totem off another flute is not always the best answer.
Some totems are just flat blocks of wood to cover the sound hole area and allow the air to pass in the flue under the smooth surface of the bird. Depending on the construction of the flute, some birds have the flue underneath the bird. Other flutes have the flue in the top surface of the flute and the bottom of the bird is smooth.
The basic classification is that those flutes with the flue in the bird are called Plains Flutes, while the other flutes are called Woodlands type flutes.
For reference, our project at hand has a flue in the body of the flute, and any bird or totem to be used with the flute will have a smooth bottom.

# How to build A simple North American Style Flute

By: Donn Shands

Some flutes can play with a simple piece of wood to cap over the flue area, and the front edge sit right on the edge of the back wall of the TSH. The perpendicular edge is anywhere from ¼ inch to possibly 1 inch high. Sometimes that front wall is angled forward about 30 degrees over the TSH. Some times the face of the wall takes on the shape of an alcove, or a hood that covers the TSH, but is open to the front or South end.

Other flutes require totems with little sphinx legs out front. The little legs guard the sides of the TSH and usually extend from the rear wall of the TSH to the edge of the splitting edge. The height of these legs varies from about ¼ in to higher up to even an inch… The little legs form what is known as a flute chimney. Some totems are crafted whole as one unit with a carved effigy or totem figure on the top part, some glue an effigy on the totem base.
In any case, the totem block is usually held down by leather lacing that binds it to the top of the flute over the sound hole area. If not seated properly so the air is channeled across the flue and directed to the splitting edge, then there is no possibility of a note being played.

Personally, I use a simple ¼ inch piece of the poplar wood that is almost as wide as the body of the flute, and about 2 ½ inches long. Each crafts person will eventually gravitate to making a bird or totem which they will find to work, be simple to make, and will be an expression of themselves and their handiwork. The pictures shown are my simple totem or bird that I use. For some reason, I have found the little sphinx legs for a chimney work best for me. You and many teachers may have your’s and their personal designs that are preferred.
Remember that no two flutes ever come out exactly alike. When a person begins to design other flutes from scratch, then a whole lot of new variables come into play.
Your new design just may require a very different configuration of a totem or bird to make the flute play properly.
For now, I happen to know that the configuration I will show you will work, and suggest you use it. You do not have to get fancy with all the carving. Just put the little sphinx legs out front, and make sure the bottom of the totem is smooth and is wide and long enough to adequately cover the flue and sound area.
To save time putting the totem on and taking it off for testing and further finishing the flute, just use a rubber band and twist it on a couple or three times until secure.

To the right is my simple design of a totem
or bird. The easiest way is to just cut the
rectangular block out. Then measure out
the distance across the TSH and the depth needed to cover each side. Make sure you have enough length to cover the SAC escape hole and enough surface area to cover both sides of the entire flue .I use the Dremel ½ inch sander drum to carve the piece into shape. Make sure you use a leather glove to hold the piece when carving.

The picture on the right is just an illustration of using a
common block of wood for a temporary totem. Just remember, that the bottom of the totem and the top of the flute must match evenly so that no air escapes out from under the totem, except directly forward via the flue. If in question, hold the assembly up to a light and no light should be
showing through under the totem clamped in place. Sand the bottom of the totem on a flat block to adjust if necessary.

In the next chapter, we will discuss options of what to do next…..most would say sand the flute down…nope…not just yet.

Please go to Chapter 7

Chapter : 7
The flute now has a totem attached. Now what?

At this point, there is always the desire to stop any useful crafting, and start sanding down and shaping the flute, and prepping it for decorations.
The most important rule a flute maker should learn to live by is that you make steps at crafting a project in a proper sequence. There are many more steps to go through in shaping this flute that we have come so far with. If we get ahead of ourselves in the chain of sequences, and spend all that time and effort, then by some fluke, make a drastic mistake that cannot be corrected…..and it can happen….then you have wasted a whole bunch of time for nothing. Your intention is to carefully craft a personal project that will be able to play music, and be a functional usable instrument. You will have plenty of time later to decorate and refine your masterpiece. “Wall Hanger”, is a taboo word for a true flute craftsman…..

For now, lets determine some of the basics of the construction of the flute.

# How to build A simple North American Style Flute

By: Donn Shands

Don’t want to confuse you, but the picture at the right, because the flute was constructed square, could be the blowing end or the South end of the flute. The shape is not refined.

Shown at the right is the South end of the flute when shaped. Notice that the inside edges are kept straight.
Now….before you get hasty….don’t spend time shaping this just yet. There are many more steps before you get to this step.
The next picture will have a bearing of how the blowing end of the flute will be crafted.

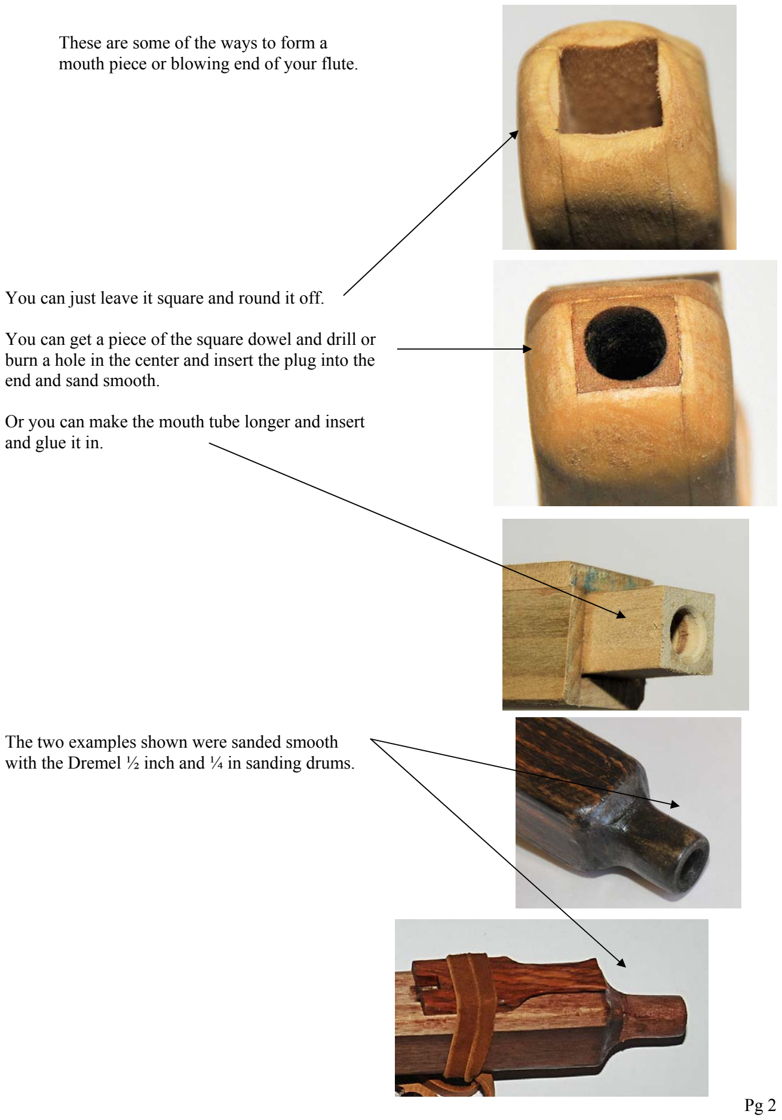
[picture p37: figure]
These are some of the ways to form a; end and sand smooth.; and glue it in.

mouth piece or blowing end of your flute.

You can just leave it square and round it off.

You can get a piece of the square dowel and drill or burn a hole in the center and insert the plug into the

Or you can make the mouth tube longer and insert

The two examples shown were sanded smooth with the Dremel ½ inch and ¼ in sanding drums.

So, before you decide to continue with the next step of tuning, make up your mind what type of blowing mouth piece you want.
Should you consider the use of the square dowel, then you must use a drill press, a drill press vice, and a forester bit to cut the hole. You could use a conventional fine drill for a pilot hole, and use burning rods to make the hole. The use of burning rods however comes later in another chapter. Do not insert the plug in the hole then try to drill it out. It must be done outside the flute then inserted. (Trust me, it may take you several tries depending on your skill to get the hole dead center in the dowel. ) Do not be stupid and even try to use gloves to hold the plug in your hand while trying to drill or burn through it. It is just unsafe and don’t even consider it. This is not a Darwin Club work shop.

By the way…remember, do not attempt to refine the South end of the flute just yet. Crafting of that end will be detailed in the next chapter.

Please go to Chapter 8

Pg 3.

Chapter : 8 Take time to learn some things about necessary tools and accessories that you will need to complete the next step.

I am sure some of you might be tempted to skip over this chapter.
If this is the first time you are going through this How To Manual, then do yourself a favor and take time to read the chapter. Just by happenstance, you might learn something you can use in the future and might do a better job finishing your flute.

Granted, there were some tools discussed in Chapter 1, but at this stage of building this flute, there are some specialized tools that are just not easy to obtain. Even after obtaining them, it will take some extra work to understand how to use them.

We will start with the burning rods.

# How to build A simple North American Style Flute

By: Donn Shands

Fellow flute enthusiast, Mike Jones taught me how to make my own set of burning rods. At the top right is his set. Believe me, that set has seen a lot of miles of use. While Mike’s main interest is crafting bamboo flutes, the techniques he taught me were immediately transferable to the crafting of branch flutes. Many of his tools and methods are described in this How To Manual.

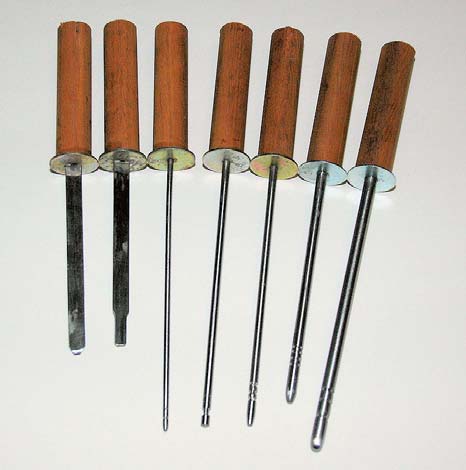
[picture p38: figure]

The set on the right is my personal set. Mike had a few left over lengths of sizes of the steel rods, and I purchased the rest. This is a good afternoon project to assemble. This is only a length of round dowel cut to make the handles, A few steel washers to dress up the appearance. And some glue.
Remember to buy only cold steel. Do not attempt to use aluminum, copper, brass, or a soft metal. Lowes or Home Depot have the rods available in a bin of several sizes. The sizes needed are listed below.

These two are flat steel bars
0.499 by 0.123 inch. The tips of these are ground down to use to burn in TSH on bamboo flutes. Can be used on wood, but causes too much over burn.

This one is, 0.185 inch

This one is 0.247 inch and has an inverted tip to help with getting under the edge of sound holes.

This one is 0.247 inch and used for just regular round holes.

This one is 0.317 inch

This one is 0.374 inch

Not shown is a really fine one 0.122 inch Used for small bore flutes needing very small sound holes.

The best way to purchase the rods is to go in with another person when buying the lengths of steel from the hardware store. Each bulk rod will probably make two to three of the same size burning rod.
Use a grinder with proper eye and hand protection. Fine finish with a sanding disk.
If you are wondering why there are ridges on some rods, in some wild theory, they are supposed to help with heat dispersion.
When building the flute featured in this manual, you will only use 0.185, 0.247, and 0.317 size burning rods.
In reality, burning rods can be made out of old drill bits, old steel screwdrivers, even old steel bolts, ground down or otherwise. Just try to get something long enough so the heat can be kept at a distance from the wood handle.
There are ready made burning rods available for purchase, but usually they only come in two sizes at most. Do a search on the internet if you are interested. Remember, once you construct this set, you will use it for life. It is a great investment for your work bench.

At my senior age, the hands are not always steady when trying to hit the mark with a red hot burning rod. By chance, I was at Harbor Freight and ran across a set of shim tools used to help remove window handles in automobiles. The shape was exactly what I was needing without having to cut, grind, bend and invent my own. With the flute held down securely, you have one hand holding the burning rod, the other positioning the rod in the V near the tip, to accurately guide the tip to the spot marked to burn the sound
hole. Cork was added to one of the tools on the bottom surface. It is handy for use with round surfaces, especially bamboo. The cork helps to not mar the wood, and also helps to keep the tool from sliding over
the surface. | Pg 2

What’s
this?

One thing for sure, if it is not already invented or available at the local store, the garage shop hobbyist will create it out of self defense to make life easier. Shown in the picture, is my set of holders for the burning rods. It was made out of a 2 by 4. Purchase a length of steel conduit,

¾ inch. Measure the length of your burning rods and find the one with the longest length of the exposed steel portion. Use that measurement to cut as many equal pieces of conduit tube. When hot burning rods are returned to their holders, you will want them completely covered in the safety of the conduit tube and not being able to come in contact with another surface. Mark off an adequate distance of space between centers to allow rods to sit next to each other. Drill a forester bit hole that is the same size as the conduit. Insert the cut lengths of conduit. Good idea to put a little glue in the hole with the pipe. A couple of long lag bolts will hold the new rack to your work bench and you are set.
In case you forgot, that orange thing is a safety push stick to use when dealing with your band saw. (Sold at Harbor Freight.)

Of course, you will need something to heat the
burning rods. You can use a camping stove running off propane. Or, you can use a portable bottle of propane with an attached regulator. Or, you can use one of those larger propane tanks, like the one on your BBQ grill, add a length of extension tubing, and then use the regulator on the end. Attach the regulator and tube assembly to the side of your work bench in a safe location. Note the great engineering of tape attaching the assembly to a 1 by 2 that was tie wrapped to the leg of the work bench. Hey, it was cheap…and solved the problem.
Note the flame spreader that is attached to each of the regulators shown. There is a very good chance you will not find that flame spreader at your local Lowe’s or Home Depot. I had to go to a local small hardware store like Ace to obtain the spreader. The spreader helps to heat the burning rods a lot faster than just the straight flame.
If you check some of the files on the flute forums, you
will find some really clever setups of the propane
burners. Some are crafted to provide holding devices
for the rods that are being heated. | Pg 3

Pg 4

I was gently reminded by my proof reader, who was a safety engineer at a company where she worked, that I was forgetting to mention a highly important safety item for the workshop. The portable fire extinguisher.
In fact, a couple of these in strategic areas might be an even better idea.
Take time to review the way you use open flames in the work shop. Secure flammable liquids, and items that are readily combustible in a separate area, or a safe distance from any use of open flames. The extinguisher should be right within reach in the area where you are using your propane setup for the burning rods.

It was requested to provide a bit more detailed explanation of how the burning rods were constructed, so a SUB Chapter has been added. Chapter 8 a, which is included with the rest of these chapters.

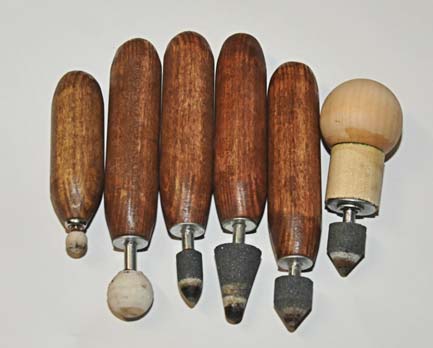
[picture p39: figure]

Shown on the right are sets of our in shop, constructed hand tools that were created out of necessity. While the orange stone shown in the center of the bottom picture is used most of the time in a Dremel chuck, (as shown below) having one in the hand tool set has its place. So, how and what are these tools used for? When a playing hole, (or a tuning hole) is drilled, or burned into a flute, it is sometimes necessary to smooth out the sides, and also chamfer the rim of the hole to take the sharpness off the edge. Doing so, helps to allow the player to better seal off the hole, or slide or bend notes while playing.

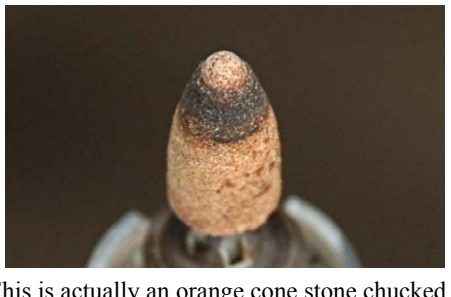
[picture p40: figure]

This is actually an orange cone stone chucked up in Mike’s Foredom extension hand piece. Often this stone is used to help open a hole slightly to raise the note a few cents.

The two stones shown on the right are the ones
most used for the final smoothing of the rim of the
playing holes.
All the stones shown above and here are mounted on either 1/8 in shanks, or ¼ in shanks. The ¼ in shanks will not fit in some Foredom chucks, and for sure, not in Dremel chucks. They will fit in Master Carver Stealth Handles. We decided because these stones were only needed for short
term use, it was much easier to just mount them in
wooden handles for use.

Once again, the shop worker had to improvise. We used pieces of wooden dowels for handles. At the local Hobby Lobby, we found the round balls that just conveniently fit the palm of your hand comfortably, and we used them for handles. This set will join the other hand made tools in your shop as life time companions.

I have been requested to write an expanded description of the stone tools and how they are
made, so, a SUB Chapter has been added. Chapter 8b is included with the rest of these chapters.

In case you were wondering, I have no affiliation with the businesses I mention as sources. Harbor Freight only recently opened up retail stores in our area, and across the USA. For those of us that want to acquire tools and accessories for our workshops, Harbor Freight provided on a local level a source for items that were a good step above the quality of cheap dollar store tools, and a fair quality tool that was far more reasonable than what was being sold at Lowes, Home Depot, and Sears. Those craftspeople that progress in their skills will eventually go on and purchase their more precision tools for their shop, such as band saws and drill presses. They will shop for a brand name tool with more accepted precision and reliability. A workshop with a full compliment of tools does not just come into existence over night.

I will attempt to briefly discuss the needs for computers and computer programs that are used by a great deal of flute craftspeople in their crafting work.
There are several methods of determining the positions and locations of where components of a flute should go while being constructed. Some of the methods are much easier when assisted by computer programs. The most basic method, the “grandfather method,” while sometimes being adequate, and not in need of computer assistance, will not be exact enough to keep a beginner out of making mistakes during construction. Each of the tuning processes have their individual merits, no one of the methods is “The Way” to construct a flute.
There are many ways to be assisted to find out what frequencies are being played for each test of a note for a finger sound hole. Get a room full of flute people, and each will claim they have the best way. We will suggest a few.

The first vital tool that is needed is a tool to identify what frequency is being played while in the process of tuning a flute.
Not everyone has perfect pitch or the perfect ear for a frequency of sound. There are some that can play a note and tell you almost to the cent what the frequency is that was played.
The rest of us need help.
We are in the age of electronics and that rest of us have to depend on electronic precision instruments to determine sound frequency.

Once again, you get 20 flute crafters in a room and ask what they use
for tuning, and you will pretty much get 20 separate answers.
You could use an electronic self contained tuner usually something like a Korg tuner with a digital display. It has a built in microphone and reads out the frequency, shows the note being played, and whether or not that note was being played plus or minus increments in Cents. The unit is accurate and portable.
I found out the hard way that the cheaper guitar tuners with just red and green
LED lights for indicators are not accurate enough for fine tuning North American Style flutes.
I was introduced to two important software programs that run on standard Microsoft computers. They do have the software for the Apple computers, but you may have to research the source.
Most flute crafters do not have access to a second portable computer. However, having an old retired lap top that can be dedicated to the workshop is the best solution. The main thing is that the lap top will
need to have a working sound card, be able to attach a microphone, and
have a CD/DVD drive. Having wireless to connect to the internet is a
plus. | Pg 6

Korg Tuner, just one
of many models.

We are very fortunate to have a few individuals that have graciously made soft ware programs available for North American Style Flute builders. Pete Kosel was the author of the original Flutomat program. Edward Kort helped to improve the program by an addition of a web interface. Clint Goss is noted as a contact for more information.
The original concept of putting the program together was based on information gleaned from some books written by Lew Paxton Price.
For a more concise and correct explanation of this history, please go directly to the FluteKey website.
The address for this information is found available at: http://www.flutekey.com/htm/naflutomat.htm The complete program is available for use at this address. The most recent up-grade of the program is always available at this link.

What most people overlook is that not only is the web page interactive, but it has a very thorough, “Easy Walk Through Explanation”, included by courtesy of Edward Kort.

What did we say about all those impatient people? They never stop to read the instructions.

Thank you Ed, eventually the rookies will wake up and go back in and read the operator’s manual. !

A very simple and easy computer program that is a free download off the internet is, “The Auto Tuner,” previously known as Shakuhachi Tuner, or Syaku8.exe http://www1.ocn.ne.jp/~tuner/tuner_e.html will take you to the web page. Scroll down and download off the link for “Sound color analyzer and Tuner for Shakuhachi.”
This will be a .zip file, so you will need a program to open a zip file if you do not have one.
After installing the program, you will need to click on Options and do a check on your sound card. As mentioned earlier, you will have to have a microphone attached to the computer, going to your sound card input. You might have to go into your control panel and check the input levels.
On the program, select “Flute” for the instrument.
Use a flute, and blow a note. The note will register on the computer screen and show you the letter of the note played, and the frequency of that note.

So, it might be wise if you go ahead and down load the two mentioned programs to your computer. Take some time getting acquainted with how they run. It might help avoid some frustration later when you are actively into the actual tuning process.

Please go to Chapter 9

It was requested to write an expanded description of different methods of flute measurements, and how to determine locations of playing holes. so, a SUB Chapter has been added. Chapter 8 c, which is included with the rest of these chapters. Chapter 8c was written by Mike Jones.

SUB Chapter 8a: Detailed explanation of crafting a burning rod

# How to build A simple North American Style Flute

By: Donn Shands

Chapter 8 gives the main sources of the materials for making burning rods.
It was requested to give a bit more detailed explanation of how the burning rods were made from scratch.

At the top is a previously completed burning rod.
Below it is a piece of raw cold steel. In this case, this piece was left over from making a couple of the same size burning rods as above.
Measure and mark off approx 9 inches of length on this blank rod.
Use a hack saw and the proper safety protection items and cut the rod down to the 9 inch size.

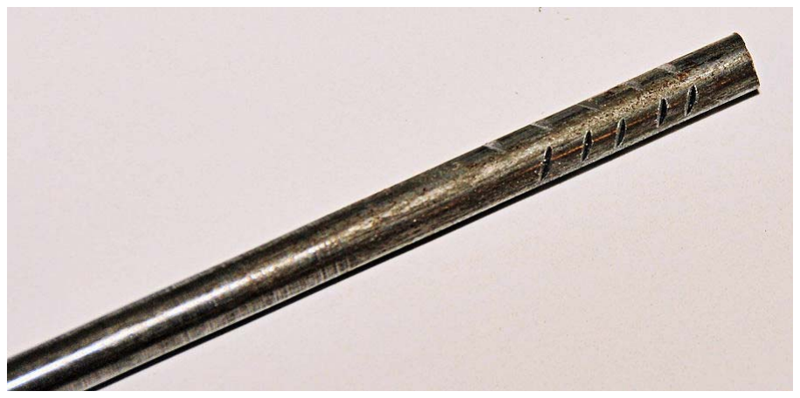
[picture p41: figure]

Take a little time and use a metal file and place scoring marks on one end of the blank burning rod. Later when you insert this end into the handle with glue, the scores will help hold the rod in the handle more firmly.

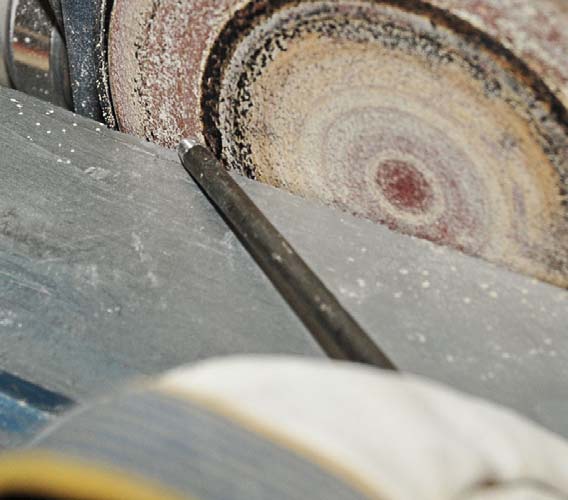
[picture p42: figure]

Put all your safety gear on, eye protection, and gloves before attempting using the disk sander. Remember, the disk sander rotates counter clockwise. Always do your sanding on the left side of the center of the wheel. Never go to the right side. Hold the rod at an angle and twirl it evenly to obtain a rounded point.

Usually sandpaper will help to smooth out the roughness and provide you with a nice smooth rounded end tip.
For this rod, I did not include the additional rings near the tip.
The rings are only added if you feel that heat dispersion is absolutely necessary. Since these rods are as long as they are physically, heat dispersion rings are not necessary.

The handle is a simple matter of cutting a length of round dowel. Usually 5 inches long is adequate. A diameter of 7/8 inch to 1 inch is comfortable in the hand.

Take a little time and use a rasp, or sand paper and round over one end of the handle blank. It just makes handling the burning rod a lot more comfortable.

Being able to drill a hole in the end of the handle that is dead on straight is a bit problematic. You can make a jig that is 90 degrees and up right.
You can mount it on a platform. By holding the dowel in place with a clamp, and drilling into a predetermined center of the dowel, the task is simplified.
This jig just so happened to be a left over piece of plastic that was part of a packing accessory to help prevent damage on a refrigerator during shipping. Sometimes you just find solutions right under your nose.

I found that a bit of epoxy mixed up is the best to hold the rod firmly in the handle. The addition of a fender washer helps to dress up the face where the rod meets the handle. The epoxy will hold the washer on. You can finish off the handle with a little stain and lacquer.

This is the end of SUB Chapter 8a, please return to the main chapters of this series.

Pg 4

Chapter : 8b Detailed instructions on crafting a hand held stone hole reamer

# How to build A simple North American Style Flute

By: Donn Shands

In the main body of Chapter 8, hole reamers were discussed. It was requested to expand on the explanation of how these reamers were crafted.

The stone cones will normally come as a set. They are often on sale at your local Harbor Freight store.
They will come in sets of 5 and some sets will have 1/8 in shanks and others will have ¼ inch shanks.
Some other cones will be part of your extras in your rotary tool set.
For flute making, I have found little use for these stone tips for their usual purpose of grinding metal.
Turns out that they seem to do a great job of grinding out and smoothing playing holes on a flute.

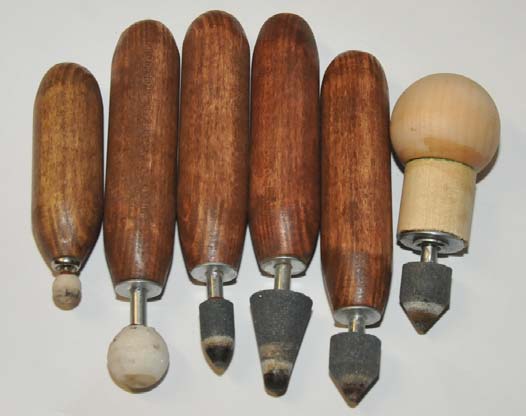
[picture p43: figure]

If you read the Sub Chapter 8a on making burning rods, you can apply the same techniques to making dowels into handles and drilling mounting holes.

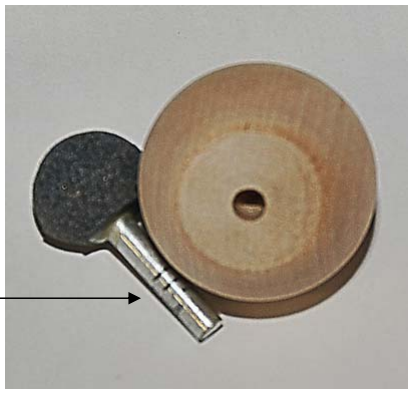
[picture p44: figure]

Shown at the right, is a stone with a ¼ in shank. Along with it in the picture is a pre made ball that has a pre flattened side.

Note that like the burning rod blank, the shank of the stone has ridges cut into it with a file. This will help to hold the shank in the handle when glued with epoxy.

As shown in the burning rod chapter, you can add a fender washer to dress up the contact point.

The round balls are found at Hobby Lobby. They are listed as Ball Knobs 6 to bag…. 1 ¾ inches diameter. 3/16 in pre drilled holes. These have a side sanded off. Item # 165845

The stones in the first picture above, were mounted in completely round balls with no flat surface pre sanded off. The completely round balls do not have pre drilled holes. These are better when mounting the smaller shank stones (1/8 in shank) into a handle.
In the bottom picture of page one on the right side, is an experimental handle of both a flat surface ball and a short piece of dowel. After making many flutes and using these hand reamer stones, we found that the use of the ball handles were a lot kinder on the hands during use.

Eventually, I will build me another set of burning rods and combine the ball on the end, and a short length of dowel for finger rest. The addition of the ball helps to control the rod when twisting it during the burning process.

Pg 2

Chapter : 8c

# How to build A simple North American Style Flute

By: Donn Shands

I also use burning rods to get each hole close to being in tune and then use a Dremel type tools A bullet tip shaped grinding stone is often used to friction burn the holes while fine tuning.
When getting close to being in final tune I use the Dremel to round off the upper hole edges to be more comfortable for the players. I also have some other handle mounted cone shaped grindstones to bevel the outside edge of the holes

## Mike Jones’ method for using NAFlutomat and tuning finger holes

Note that I use a tuner program on my PC and/or laptop for tuning. These types of programs not only will tell you if you are sharp or flat but how many cents sharp or flat and the actual frequency being played. Most have other features as well and I STRONGLY suggest that you try one out, some are even free! In the instructions below I am assuming you will be using such a program or device that will give you the actual pitch in frequency.

Below is the Basic procedure I use to tune a Native American style flute. I sometimes use other methods and I have chosen not to go into details dealing about fine tuning cross-fingered notes. Please see Bob Grealish’s very well written document on that subject. It can be found in the files section of the Native Flute Woodworking Yahoo group.

1. Launch NAFlutomat (version 37) and make sure that Internet Explorer allows it to run the ActiveX script.
2. Set the playing and tuning temperatures in the computer program, where prompted to.
3. If you only want the finger holes tuning (pitch not placement) info, skip to step number 8
4. Set the bore diameter, use an average if it is not consistent or approximate, or if it is not perfectly round. You want to use the diameter of an equivalent circle with the same cross-sectional area.
5. Measure and set the East-West width of the TSH, and then the North-South length of the TSH
Pg 1

6. Set the wall thickness at the TSH
7. Set the Length/Diameter (L/D) ratio you want to use. For 1 1/8" or larger bores, use 18-21; for 3/4-1" bores use 16-18; for 1/2-3/4" bores, use 15-16.
8. Move down to the finger hole section and put in the desired pitch of the flute. Keep in mind that Middle C is 262 Hz, and an A flute is 440 Hz. This will help you pick the correct octave for your flute pitch.
9. If you have a long flute and you want to use tuning/direction holes, turn on that section with the check box. Otherwise skip to step 11.
10. Use a digital tuner to put in the fundamental frequency that the flute is currently playing. Set the size holes you want and the wall thickness and click on “Calculate.”
11. Move back up into the finger hole section, Set the hole 6 wall thickness to whatever your wall thickness is for all the finger holes, and then click on the button at the top of this section to "replicate hole 6 wall thickness" so that all the finger holes are the same.
12. Directly above the button you just clicked on, you will see a box that indicates the minimum playing hole diameter. If the box is empty you need to click on the calculate button. Make a mental note of this diameter.
13. Go to the hole 1 hole diameter and put in a size a little bigger than the minimum hole diameter you made a mental note about. For the typical A and lower flutes I try to stay between 0.25 and 0.4 inches, usually close to 0.3 - 0.35, never less than 0.25. Now put in the minimum size for all 6 finger holes then click on “Calculate.”
14. Look at the column marked Distances between Finger Holes. Calculate a mental average or typical value from the values displayed. Now, adjust the finger hole sizes for holes 2-6 to get most of the distances between finger holes close to the same value. Be sure to click on the Calculate button after each change to see the effect. If you make a finger hole larger, the distance from the previous hole and the one you changed will get smaller and the distance between the changed finger hole and the next higher one will get bigger. Try not to set a finger hole diameter that is smaller than the minimum. Note: a hole somewhat bigger than the minimum is best for hole #1 to give good tone and to make half-holing easier (to sound right the half-hole has to be very close to the minimum size!)
15. Once you are satisfied with the finger hole distances, put a piece of masking tape on the flute to the side of where the finger holes will be put. Mark the distance from the end of the flute to where the tuning/direction holes will go, where hole 1 goes and where hole 6 goes. These are all measured from the foot end of the flute.

Pg 2

16. Now measure the distance between hole 1 and hole 6 and use a calculator to divide it by 5. This is the actual distance to use between finger hole centers. Mark the location on the tape for holes 2-5.
17. At the bottom of the tape, near where the tuning holes will be, write down the playing pitch and the tuning frequency for the fundamental. The frequency for tuning is in the column labeled "tuning frequency" and is already adjusted for the tuning temperature (if you put that in in step #2.) From now on do not concern yourself with the tuning letter or pitch. Only use the frequency.
18. Write the tuning frequencies for holes 1-6 on the tape next to the location of each hole.
19. Now you can put the tuning holes in the flute by drilling or burning. Start smaller than you put in NAFlutomat and gradually enlarge the holes until they are right on the money for the fundamental tuning frequency. NOTE: The fundamental will get slightly flatter after the rest of the finger holes are put in the flute. We will fix it on the 2nd pass.

20 Put in hole #1, smaller than you expect to have it at the end. Enlarge it until it is a little flat of the target frequency.

21. Put in the next finger hole and tune it to be a little more flat than the previous finger hole was. Repeat this for all 6 holes. NOTE: If you see that the finger holes are getting too big or are getting progressively bigger, shift the next finger hole a little higher on the bore. Each following finger hole will have to be moved up the same amount. Repeat this step for each finger hole.
22. Use a dowel (with sandpaper glued to the last 6 inches or so,) to remove any splinters or material hanging in the bore after the finger holes were put in. After all the finger holes have been made in the flute, and the bore checked to be clean and clear of debris, go back and check the fundamental. Tune it to be right on the tuning frequency.
23. Now adjust each finger hole to be very slightly flatter than the previous hole. For example, if the first pass you made them each 7 cents flatter than the previous hole, this time make them about 3 cents flat.
24. Use an Xacto knife, (I prefer the curved carving blade (#28),) to bevel the inside edges of the finger holes. You have to do this in four steps for each hole. Start at 12 O'clock and shave the bevel until 3 o'clock, then start at 12 o'clock and shave the other direction until 9 o'clock. Now start at 6 o'clock and shave until 3 o'clock, then from 6 o'clock until 9 o'clock. You do this in the above 4 steps to prevent splintering. Now bevel the top of each hole the same way or use a Dremel or large cone shaped stone to put a slight bevel where the player’s fingers contact the playing hole. You want this edge to be smooth and comfortable for the player. A dowel about the size of a finger with sandpaper wrapped around it can be used on the outside, sanding lightly across the hole in the East-West direction. The finger hole should now have a shape similar to the inside of a donut or bagel. This will help to make the flute responsive and clear toned at each hole.
25. At this point the beveling should have raised the pitch of each hole slightly and they should all be VERY close to the tuning frequency. IF you have to adjust a finger hole to get it closer to being in tune, be sure to touch up the inside and outside beveling. Finish each hole on the outside edge with some 400 - 600 grit sandpaper.

Chapter 9:
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

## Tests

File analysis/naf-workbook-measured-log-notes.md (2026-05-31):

# NAF Workbook Row Extraction and Public Log Comparison

Issue: `tonykoop/flutes#5`

Readiness: public comparison artifact only. This does not promote the packet to
build-ready, measured-current, or CAD/DXF fabrication authority.

## Public Extraction Scope

`design-table/public-naf-workbook-rows.csv` extracts the public F4, A4, and
C5 rows from the `Low to High Range` sheet of
`design-table/flute-dimensions-parametric.xlsx`. The extraction keeps only
engineering fields needed for acoustic comparison: target frequencies, bore,
wall, mouthpiece, slow-air chamber, spacing, long chamber, flue, true-sound-hole
length, and six hole diameters/positions.

The CSV intentionally does not publish private workbook/archive paths, owner
fields, price fields, recipient details, dates, or free-text build notes.

## Comparison Method

`analysis/naf-workbook-measured-log-comparison.csv` compares each extracted row
against sanitized aggregates from the workbook `Built` sheet:

- count of public rows for the key,
- count/range/average for logged long-chamber values when present,
- count/range/average for TSH width, track length, and nest width when present.

The comparison is useful evidence that the historical workbook and measured
build logs cover the target keys. It is not enough to claim final tuning
authority because the public log extract does not expose a complete measured
fundamental plus six-hole tuning trace for each selected key.

## Authority Boundary

- The workbook rows are `public_workbook_extract_unvalidated`.
- The log comparison is `public_sanitized_build_log_aggregate`.
- The F4/A4/C5 rows can now drive review and follow-up measurement planning.
- CAD/DXF, cut lists, or V5 tuning claims still require a current measured
  flute row with fundamental and finger-hole tuning evidence.

## Local Validation

Run this guard after editing the public extraction or comparison tables:

```bash
python3 scripts/check_public_naf_comparison.py
```

The check keeps the F4/A4/C5 public rows aligned with the comparison rows,
rejects local filesystem path leaks, rejects private/public-hostile CSV
headers, and confirms the family-spec rows still point at the public extract
while staying `measurement_required`.

## Private or Summarized Data

The following workbook fields were inspected only to produce public aggregates
and were not exported: owner, price, private notes, dates, recipient/disposition
context, and private source/archive paths. Historical row numbers were also
omitted from the published comparison table to avoid turning the public artifact
into a build registry dump.

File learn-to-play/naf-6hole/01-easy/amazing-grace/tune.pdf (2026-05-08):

# Amazing Grace

### Arranged for naf-6hole

Key: Am Meter: 3/4 Tempo: 1/4=68

(Engraved notation: open tune.svg or tune.ly to view; see references/adobe-handoff.md for inline embedding.)

(Fingering chart: see tune-fingering.svg.)

Practice tip
The high register of an A-NAF needs more breath support than the lower register — don't overblow, but commit firmly to each note. The D6 in the second phrase is the highest note in the songbook; aim for it
gently and let it bloom rather than pushing it.

The dotted halves at every phrase end are the soul of the tune. Don't truncate — sustain to the end of your breath, then take a fresh breath before the next phrase. The breath itself is the rhythm.

Generated by sheet-music · github.com/tonykoop/sheet-music · MIT license

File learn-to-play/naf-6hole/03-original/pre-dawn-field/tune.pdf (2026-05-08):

# Pre-Dawn Field

### Arranged for naf-6hole

Key: Am Meter: 4/4 Tempo: 1/4=60

(Engraved notation: open tune.svg or tune.ly to view; see references/adobe-handoff.md for inline embedding.)

(Fingering chart: see tune-fingering.svg.)

Practice tip
Hold the long notes — the dotted halves and whole notes — *as long as your breath lasts*. The tune is built around sustains, not motion.
The high A5 (bar 18) is a full bar of held tonic; treat it as a
deliberate exhale, not a "note."

The grace note at bar 21 is the only ornament in the tune. Play it *late* — slip into the A5 just barely before the beat, then let the
A ring. That's the frost-breath.

If you run out of air on the high A, that's OK. Take a breath right

Generated by sheet-music · github.com/tonykoop/sheet-music · MIT license

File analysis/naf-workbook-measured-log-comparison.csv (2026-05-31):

comparison_id | workbook_row_id | key | workbook_long_chamber_in | workbook_long_chamber_mm | public_built_log_count | public_logged_chamber_count | public_logged_chamber_range_in | public_logged_chamber_avg_in | delta_logged_avg_minus_workbook_in | public_tsh_count | public_tsh_range_in | public_tsh_avg_in | public_track_count | public_track_range_in | public_track_avg_in | public_nest_count | public_nest_range_in | public_nest_avg_in | authority | notes
NAF-CMP-F4 | NAF-PUB-F4 | F4 | 17.030 | 432.562 | 10 | 3 | 17.000-19.000 | 17.750 | +0.720 | 4 | 0.439-0.478 | 0.453 | 4 | 1.500-1.930 | 1.680 | 4 | 0.700-0.790 | 0.752 | public_sanitized_build_log_aggregate | Build log rows for F4 show multiple historical generations/pattern names. Aggregates omit owner, price, private notes, dates, and source paths.
NAF-CMP-A4 | NAF-PUB-A4 | A4 | 13.287 | 337.490 | 9 | 2 | 15.000-15.625 | 15.312 | +2.026 | 5 | 0.378-0.387 | 0.382 | 5 | 1.480-1.710 | 1.584 | 5 | 0.580-0.670 | 0.625 | public_sanitized_build_log_aggregate | Build log rows for A4 support comparison context only. The log does not publish current full tuning traces for every finger hole.
NAF-CMP-C5 | NAF-PUB-C5 | C5 | 11.233 | 285.318 | 11 | 1 | 17.750-17.750 | 17.750 | +6.517 | 8 | 0.294-0.335 | 0.318 | 8 | 1.130-1.780 | 1.525 | 8 | 0.500-0.770 | 0.623 | public_sanitized_build_log_aggregate | C5 has a large chamber-length mismatch in the sanitized logs, so this row must remain comparison-only until source-generation differences are reconciled.

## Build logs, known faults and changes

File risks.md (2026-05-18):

# Flutes Packet Risks

## Overclaiming Historical Evidence

The repository has real build history, but the public packet does not yet expose a row-by-row, non-private build registry. Treat the history as strong provenance, not as automatic V5 build readiness.

Mitigation: publish selected non-private build IDs with key, species, measured result, and failure mode before raising readiness.

## Mixed Family Drift

Wooden NAF rows, PVC proof rows, legacy SolidWorks files, and songbook assets can look like one family if they are blended too early.

Mitigation: keep `family_split` explicit in every CSV. PVC and legacy CAD rows remain `unknown_requires_measurement` until their own measurements or exports exist.

## Formula Misuse

NAF correction factors and K2-style empirical adjustments are family-specific. Applying them to PVC, other duct flutes, or archived CAD without checking bore and voicing geometry can create plausible but wrong dimensions.

Mitigation: use `dimension_provenance=measurement_required` until the row is extracted and checked against measured stock or built flutes.

## Visual Authority Drift

Photos, screenshots, SVG diagrams, and generated explorer views can become accidental dimensional authority.

Mitigation: keep `visual-output-register.csv` current. Only CAD, DXF, design tables, measured templates, or reviewed drawings may control fabrication.

## Cultural Framing

The repo documents Native American style flutes by a non-Indigenous maker. Packet language must keep attribution and cultural boundaries visible.

Mitigation: preserve the README cultural attribution in explorer and packet summaries.

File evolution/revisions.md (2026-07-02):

# Revision Register — flutes

| Rev | Date | Parent | Delta | Downstream artifacts invalidated |
| --- | --- | --- | --- | --- |
| A | 2026-07-01 | — | Stage 0 intake of current masters (CAD/flutes_family.scad + CAD/design-table-seed.csv + Flutes.xlsx). | none (no alpha/beta/production artifacts exist yet) |

Stage 0 only. Gate A has not been run; no Alpha compiles, vendor quotes, or production lock exist for this product.

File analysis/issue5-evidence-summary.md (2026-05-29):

# Issue #5 Evidence Summary — Public Workbook Extraction + NAF Comparison

This file cross-references the artifacts that fulfill `tonykoop/flutes#5` scope:
"Extract sanitized public F4/A4/C5 workbook rows, compare vs. measured NAF logs."

## Artifact Map

| Artifact | Location | Status |
|---|---|---|
| Sanitized F4/A4/C5 workbook rows | `design-table/public-naf-workbook-rows.csv` | Present (`public_workbook_extract_unvalidated`) |
| Build-log comparison (F4/A4/C5) | `analysis/naf-workbook-measured-log-comparison.csv` | Present (`public_sanitized_build_log_aggregate`) |
| Comparison methodology and privacy notes | `analysis/naf-workbook-measured-log-notes.md` | Present |
| Family member rows with acoustic law | `family-spec.csv:2-6` | Present (`measurement_required` provenance) |
| Validator gate rows for comparison | `validation.csv:4-8` (VAL-003, VAL-004) | `public_extract_added`, `comparison_added_private_fields_omitted` |
| Promotion gates cross-reference | `design.md:34-40` | Present |
| Visual authority map | `visual-output-register.csv` | Present |

## Privacy Compliance

Verified present in all public artifacts:
- No per-flute owner, price, date, or recipient fields
- No private archive/source paths
- No full build-log row dumps — only sanitized aggregates (count, range, average)
- Master workbook (`Flutes.xlsx`) and full built registry remain private

## C5 Mismatch Caveat

The C5 public comparison shows a large delta (+6.517 in) between the workbook long-chamber
and the sanitized built-log aggregates. This is documented in both the comparison CSV and
`design.md:38`. The C5 row must remain `comparison-only` until the source-generation difference
is reconciled — it does not block the extraction from satisfying issue #5 scope.

## V5 Authority Boundaries

All public extraction artifacts use `public_workbook_extract_unvalidated` or
`public_sanitized_build_log_aggregate` authority. None are fabrication authority.
CAD/DXF or cut-list work from these rows requires current measured-flute data (fundamental
plus six-hole tuning trace) per `validation.csv` gate VAL-003.

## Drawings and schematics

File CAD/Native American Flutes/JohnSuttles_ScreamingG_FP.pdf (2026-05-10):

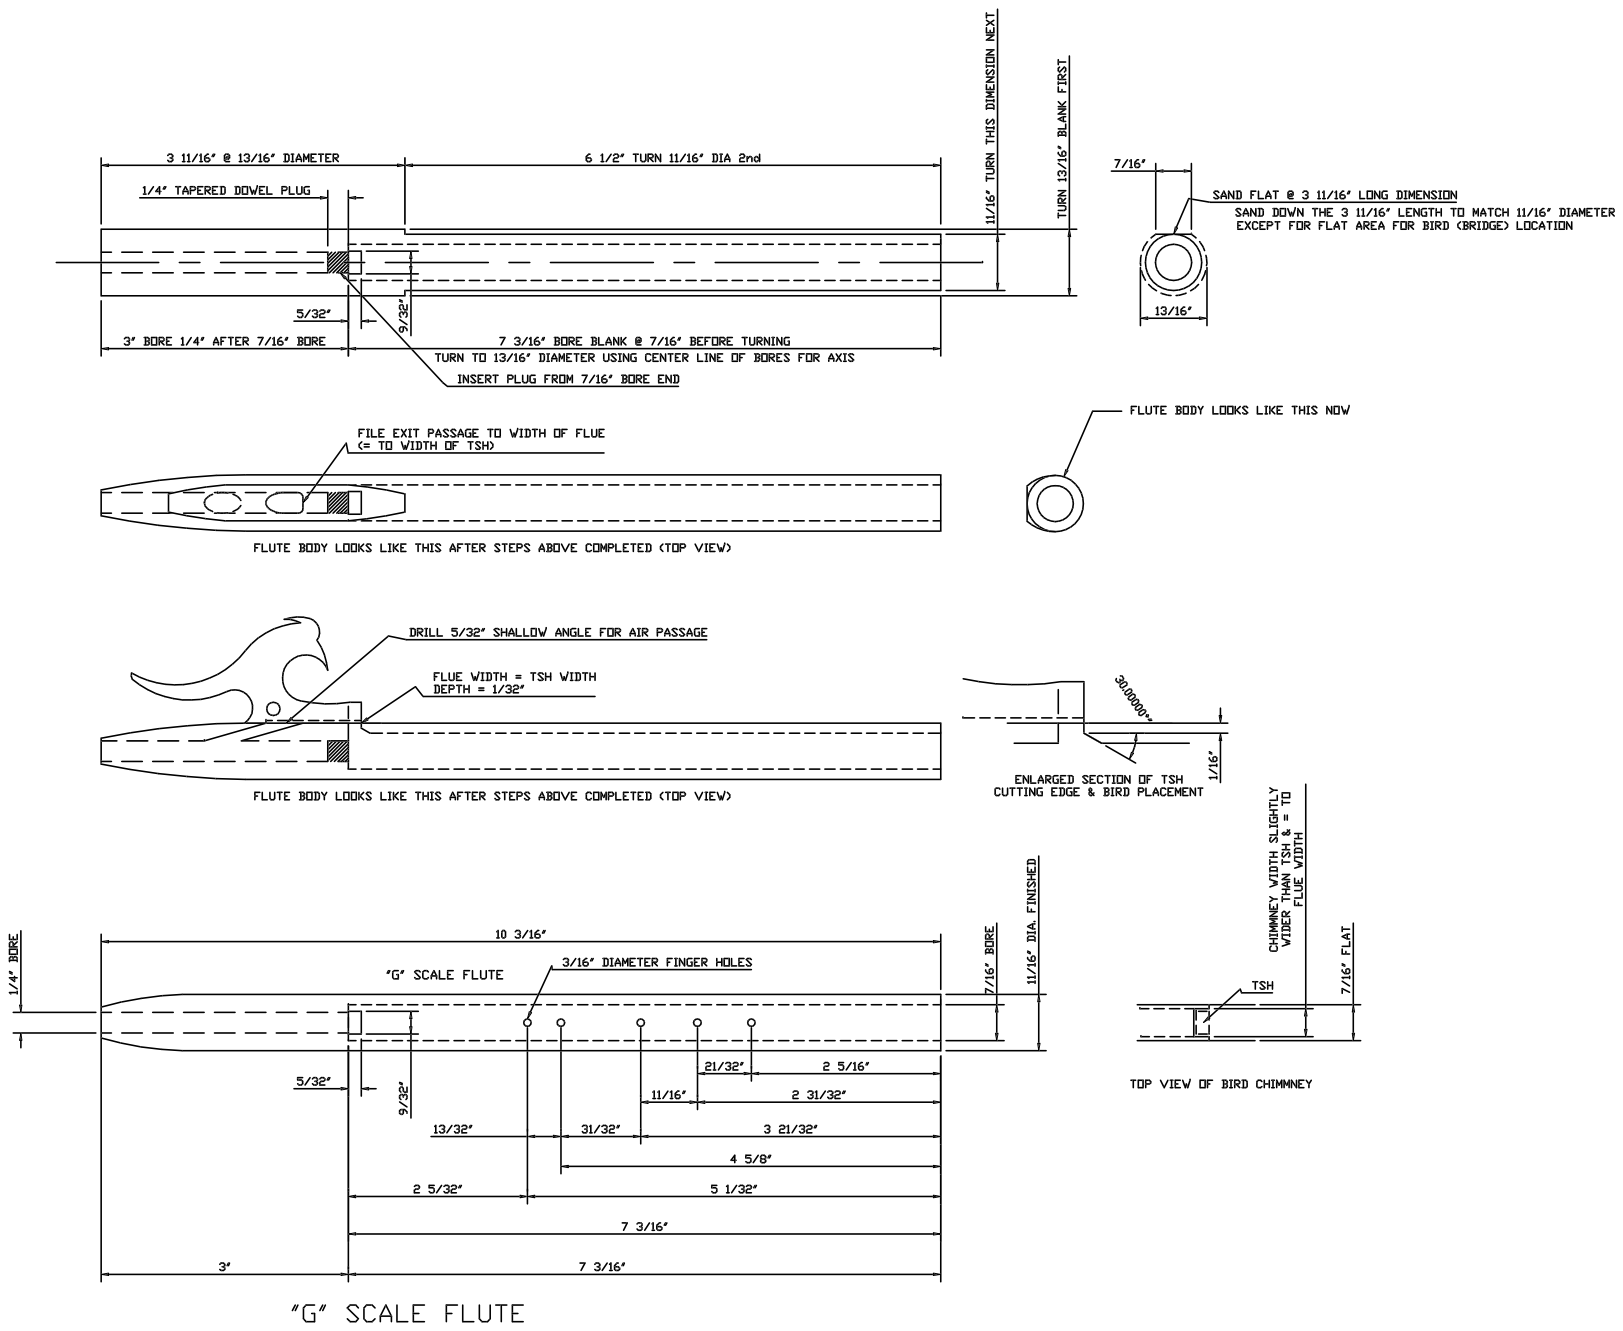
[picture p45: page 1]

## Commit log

2026-04-25 initial push
    [flute-dimensions-parametric.xlsx]
2026-04-25 Scrub recipient/owner data from README and build registry
    - Anonymize Owner column (153 entries -> 'Recipient NNN') in Built sheet
    - Clear Price column values
    - Redact Notes column ('[private]')
    - Remove entire Customers sheet
    - Update README to clarify customer info is kept private
    Original xlsx archived locally outside repo.
    [flute-dimensions-parametric.xlsx]
2026-04-25 Update flute count to 150+ and remove Price Calculator sheet
    - README: 50+ -> 150+ in 3 places (intro line 3, summary line 15, registry line 74)
    - xlsx: drop Price Calculator sheet (commercial pricing methodology)
    [flute-dimensions-parametric.xlsx]
2026-04-25 Add hero image (using sibling of stated pick — see commit notes)
2026-04-26 Embed design-table screenshot with how-to-read-it caption
    Adds the design-table screenshot at the top of "The parametric
    design table" section. Caption explains the layout: columns =
    target keys (F4-E5), three colored bands = pentatonic minor scale
    frequencies, user-set inputs, and derived/calculated dimensions
    including K1/K2 acoustic-length corrections. Frames the table as
    the engineering core readers can grasp at a glance before opening
    the workbook.
2026-05-09 analysis: add L3-frontier wood-species coupled structural-acoustic FEM (#2)
    Adds analysis/wood-species-fem/ with six documents for flutes#1:
    - wood-property-table.md: E_L, ρ, η_L for cedar/walnut/maple from FPL-GTR-190
    - fem-scenario.md: FEM geometry, mesh, BCs, and coupling physics for COMSOL/Ansys
    - modal-results-table.md: 5 acoustic modes + 3 structural bending modes per
    species; acoustic Q-factor tables by mode
    - tone-color-comparison.md: Q-weighted spectral centroid (f_QSC) per species,
    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
2026-05-18 Add Round 31 flutes V5 scaffold (#4)
    * Add Round 31 flutes V5 scaffold
    * Remove local path references from Round 31 docs
    ---------
    [bom.csv, cut-list.csv, design-table-seed.csv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]
2026-05-20 Merge public NAF workbook comparison slice
    * Add public NAF workbook comparison rows
    * Sync flutes design gates with public NAF extraction
    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
    [family-spec.csv, naf-workbook-measured-log-comparison.csv, public-naf-workbook-rows.csv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]
2026-05-20 Add public NAF comparison guard (#7)
    [validation.csv]
2026-05-23 Recover from 2026-05-18 hygiene-bot stash; restore 22 CAD files (NAF parts, JohnSuttles reference PDF, design tables)
    [Epsilon.SLDASM, Fetish.SLDPRT, Native Flute Alpha - Overblow Float.SLDPRT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]
2026-05-31 wolfram-rename(flutes): unique {slug}-starter.wl + dedupe + ref fixes (cloud-sync naming) (#9)
    [Flutes - CNC Flute Dimensions.csv, Flutes-AI.xlsx, Flutes.xlsx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]
2026-05-31 Add image-gen concept prompt; wire explorer images
2026-06-21 Wire 3 rendered concept image(s) into explorer gallery
2026-07-02 V5 packet refresh: status line, provenance, evolution intake
    Normalized Status to **Status:** L1 concept packet (kept scaffold prose + status
    table). Added provenance rows to CAD/mcp-session-log.md for CAD/design-table-seed.csv,
    the OpenSCAD family master, workbook, and wolfram model. Added wolfram register
    row (gap). Stage 0 evolution intake (manifest, design-intent, revisions).
    Existing CAD/flutes_family.scad kept (no rewrite); openscad render check pass.
    v5-validator: 2 fails -> 0 fails.
    [visual-output-register.csv]
